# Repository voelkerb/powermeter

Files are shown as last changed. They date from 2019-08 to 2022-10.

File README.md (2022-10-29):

# PowerMeter

The PowerMeter is a WiFi equipped electricity meter which can also switch the connected appliance _on_ and _of_. 
You can record high-frequency voltage and current waveforms or embedd it into your smart home system using e.g. _MQTT_.
Further modular add-ons allow to use other wireless connectivity such as LoRaWAN or to embedd other sensors into the housing. 

<p align="center">
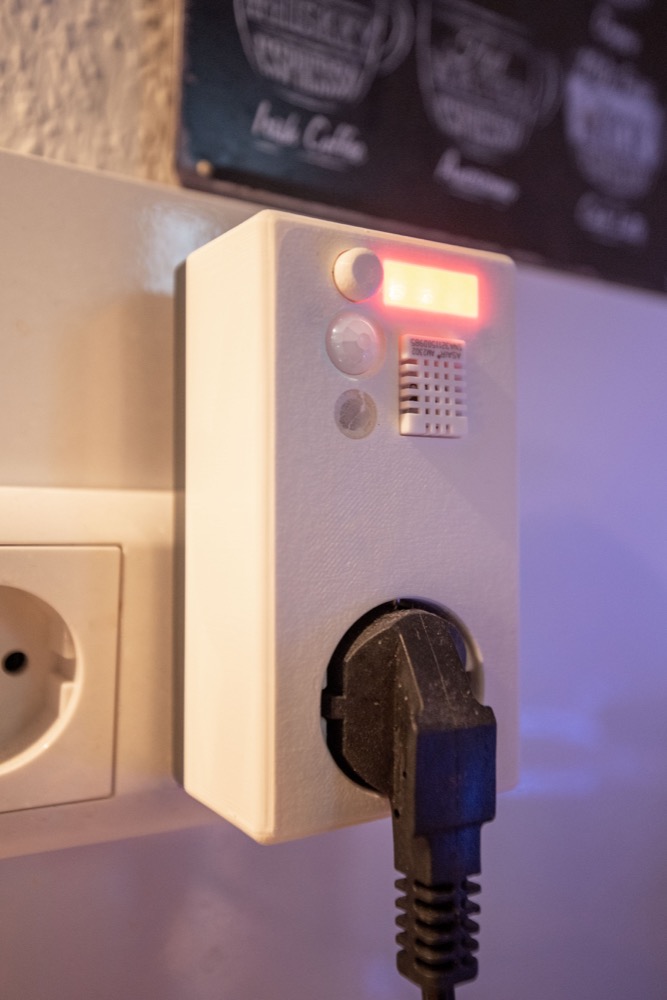
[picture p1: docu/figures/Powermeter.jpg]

</p>

### Clone this repo with
```bash
git clone --recurse-submodules git@github.com:voelkerb/powermeter.git
```

If you are interested in gathering the whole-house energy consumption, see the [SmartMeter](https://github.com/voelkerb/smartmeter) instead.

## Hardware Version _1_ vs _2_
The development started with hardware [Version 1.0](/Schematic/Version_1). It consists of an ESP8266 microcontroller and a dedicated electricity monitoring chip. As the main idea behind this project was to record voltage and current waveforms at higher frequencies, several drawbacks for this use case were fixed with Hardware [Version 2.0](/Schematic/Version_2). It features a faster microcontroller with 8MB internal storage for data buffering, an RTC for precise sampling and time keeping and a full 16A relay so that high-power appliances like dish washers can be switched _on_ and _off_. The USB connection present in [Version 1.0](/Schematic/Version_1) has been removed, but can still be added with an additional extension board.

## Why to use?
It's open source, easy to use, easy to build and offers lots of flexibility. 

The hardware is...
* tested to work reliable with 230V.
* flexible enough to be integrated into existing projects.
* extendable via a UART interface.
* rather cheap (all components sum up to around 30€).

The firmware supports...
* existing 2.4GHz WPA2 networks or can create its own network.
* to receive commands via USB, TCP or MQTT.
* to store the configuration in the internal non volatile memory.
* to provide data at sampling rates from 1/5Hz all the way up to 8kHz.
* to calibrate the measurements.
* integration into most existing smart home systems e.g. HomeKit (via homebridge and MQTT).
* FFMpeg streaming. This allows to store high frequency data directly into files (e.g. MKV).

## How to build one?
You want to build your own PowerMeter? As the PCBs are provided in this repo, you can simply make your own.

Depending on your requirements, you might either build [Version 1.0](/Schematic/Version_1) or [Version 2.0](/Schematic/Version_2). 
* [Version 1.0](/Schematic/Version_1) features an ESP8266 microcontroller and a 10A solid state relay.
    * Benefits: 
        * The parts are cheaper (around 30€).
        * It comes with a USB interface for uploading the firmware or streaming data
    * Drawbacks:
        * Non-modular.
        * The 10A relay can only switch connected appliances with a maximum power consumption of <2300 Watt.
* [Version 2.0](/Schematic/Version_2) features an ESP32 microcontroller and a 16A bistable relay.
    * Benefits: 
        * You can switch appliances with up to 3600Watt. 
        * You have multi-core microcontroller that also supports Bluetooth.
        * 8MB of internal storage allows to buffer data. If you stream high frequency data at e.g. 2kHz, this can hold up to 500s of data on network dropouts.
        * An RTC keeps track of time allowing you to synchronize sampling rates during high frequency sampling.
        * Extendable by stacking other modules on an extension header. 
    * Drawbacks:
        * A little bit more expensive (parts around 35€).

Steps to build your own PowerMeter:
1. Make the PCB ([Version 1.0](/Schematic/Version_1) or [Version 2.0](/Schematic/Version_2)). I recommend to use [JLC](https://jlcpcb.com) as it is super cheap and the quality is still decent.
2. Buy the parts listed under [BOM](/BOM).
3. Solder everything together. We used a small reflow oven, but it could also be done using a fine soldering iron. 
4. Buy a matching housing. We highly recommend to use [this one](https://www.conrad.de/de/p/bopla-eletec-se-432-de-cee-stecker-gehaeuse-120-x-65-x-50-abs-polycarbonat-lichtgrau-graphitgrau-1-st-522228.html) as the PCB was specially designed for it, the mounting holes match, and it is safe to use with 230V. We also experimented with custom 3D prints (see [CAD](/CAD)) but it's at your own risk to do so. 
5. Wire the PowerMeters using the following diagram. 

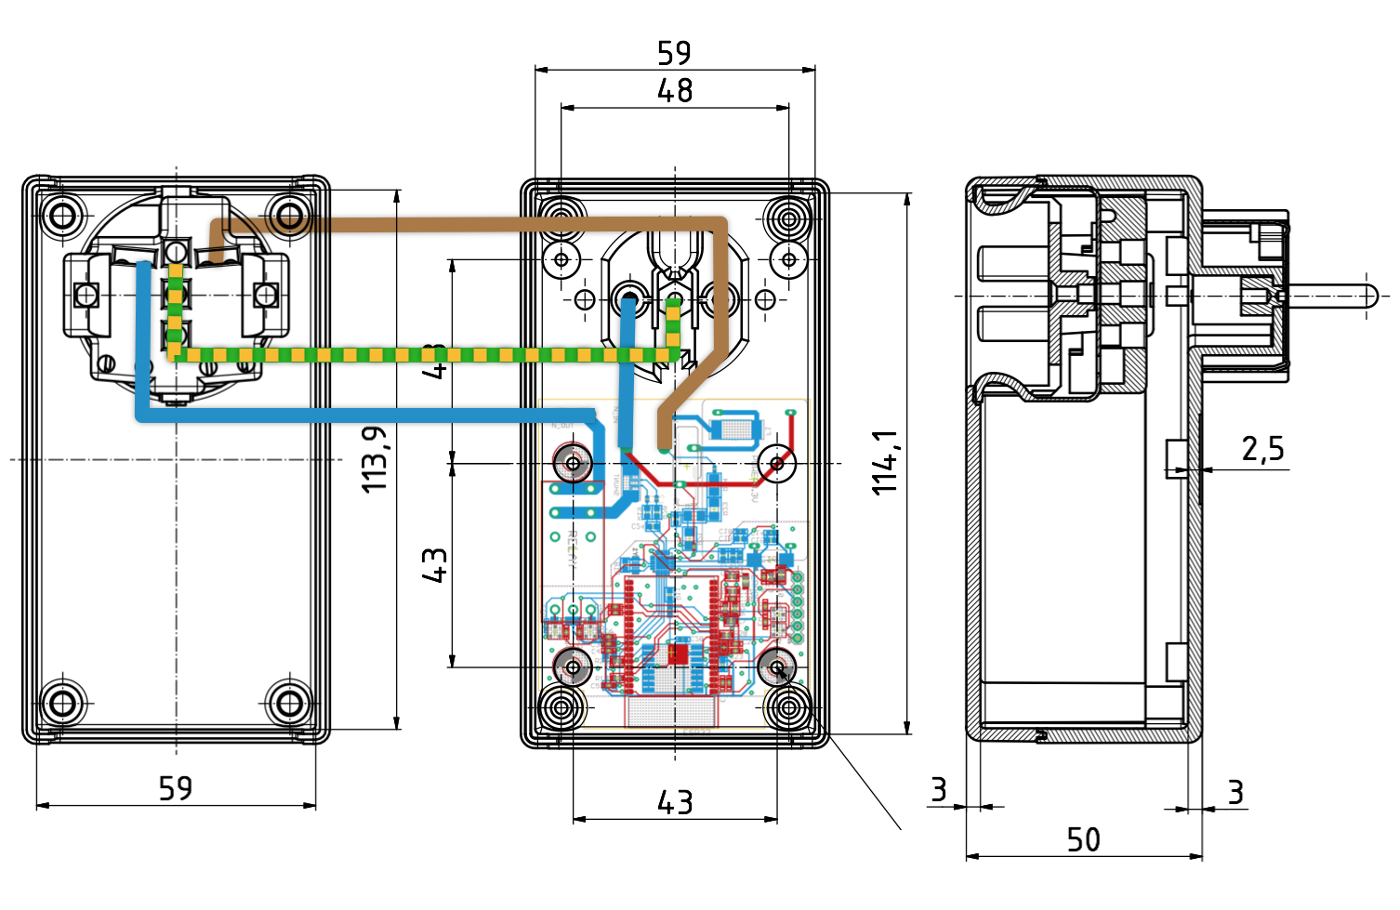
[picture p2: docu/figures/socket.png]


6. Upload the [firmware](/Firmware) according to the instructions for your version. 
7. Interface with the PowerMeter accordingly as stated [here](/docu/README_Firmware_Cmds.md) 

# Use cases
## Smart homes
There are plenty of use cases for a smart plug inside a smart home.
* Switch appliances _on_ and _off_ using a voice assistant or your smartphone
* Include it in home automation software to switch appliances based on an automation. There are lots of possibilities here, e.g.: 
    * Switch appliances _on_ and _off_ by time of day.
    * Switch appliances _off_ automatically at standby consumption.
    * Trigger an alert if the consumption exceeds a limit.
    
      <p align="center">
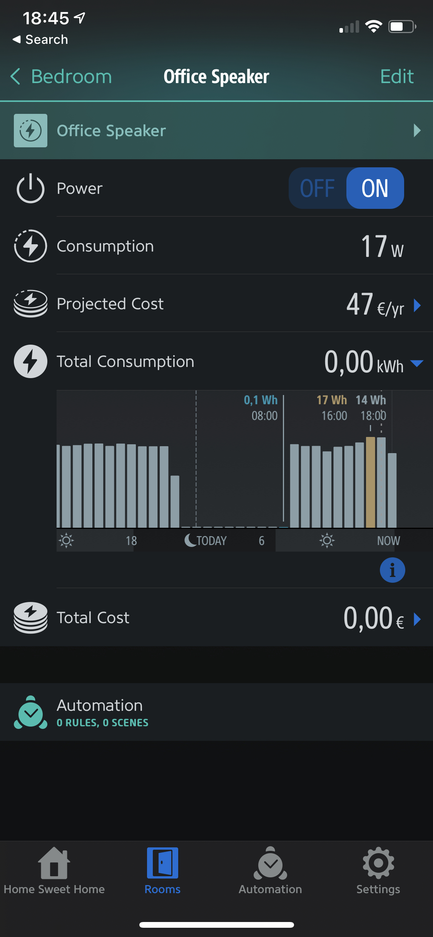
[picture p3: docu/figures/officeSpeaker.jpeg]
      
      </p>
* Monitor the power consumption of an appliance over day. See this faulty fridge as an example.
         
<p align="center">
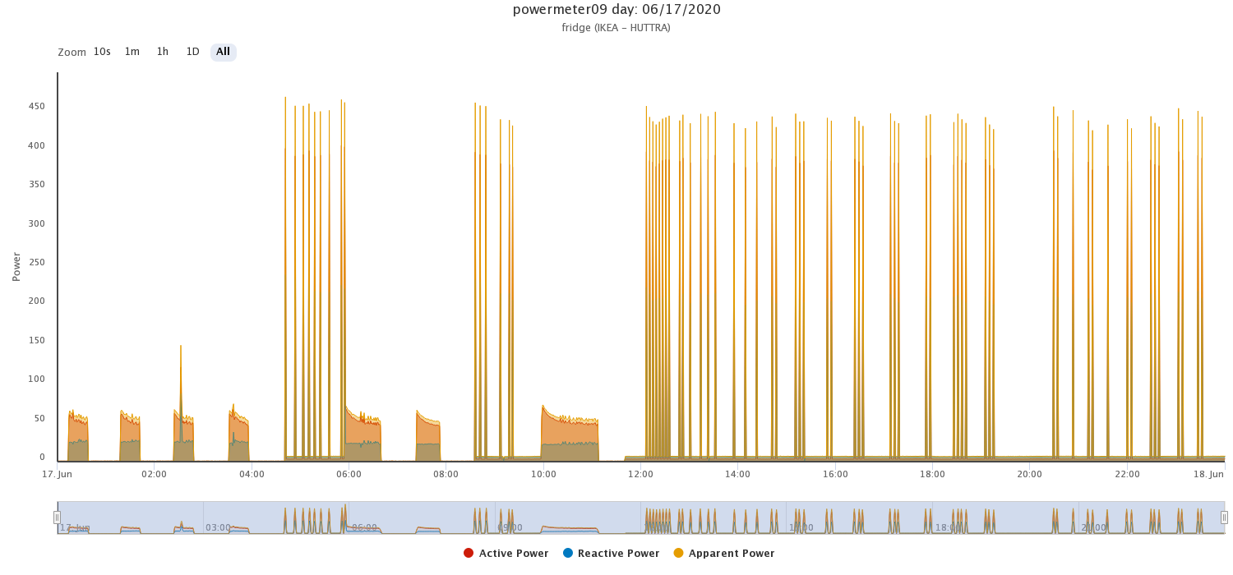
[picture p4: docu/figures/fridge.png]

</p>

## For research purpose
* Analyze high frequency voltage and current waveforms.
         
   <p align="center">
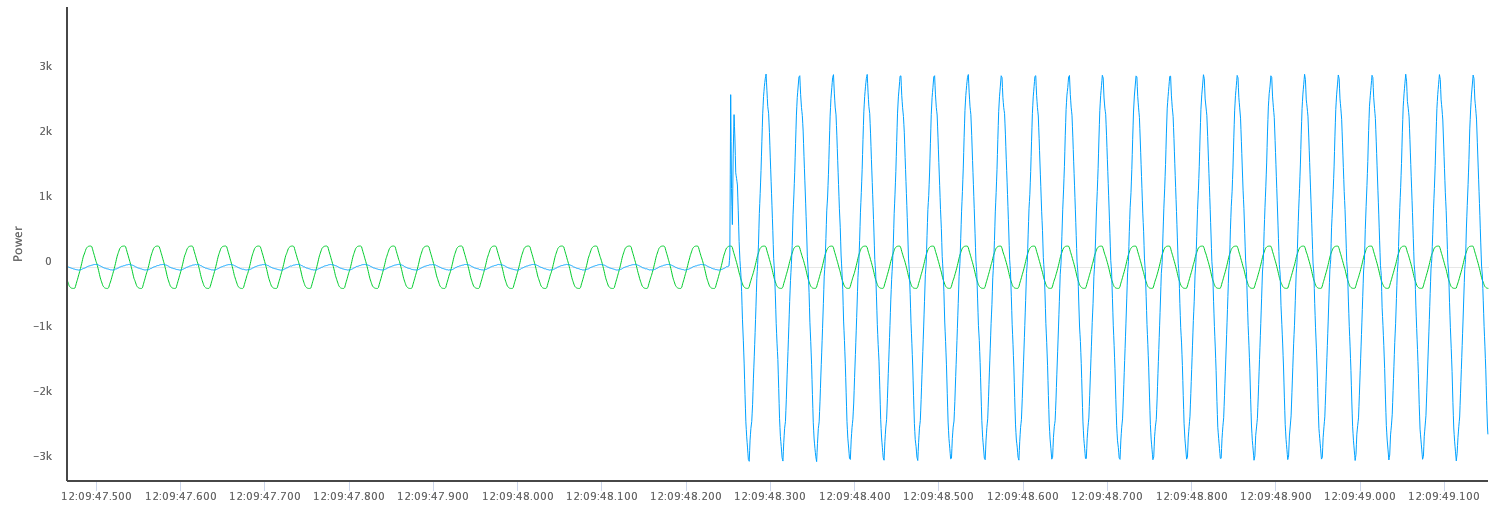
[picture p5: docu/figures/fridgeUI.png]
   
   </p>
* Record high frequency electricity datasets (see e.g. the [FIRED](https://github.com/voelkerb/FIRED_dataset_helper) dataset which can be used for Non-Intrusive Load Monitoring).

# License:
## Firmware:
Copyright (c) 2019 Benjamin Völker. All rights reserved.
This work is licensed under the terms of the [CC 4.0 licence](https://creativecommons.org/licenses/by/4.0/).

## Hardware:
Copyright (c) 2019 Benjamin Völker. All rights reserved.
This work is licensed under the terms of the [TAPR Open Hardware License](https://web.tapr.org/TAPR_Open_Hardware_License_v1.0.txt).

# Reference

Please cite our publications if you compare to or use this system:
* Benjamin Völker, Philipp M. Scholl, and Bernd Becker. 2019. Semi-Automatic Generation and Labeling of Training Data for Non-intrusive Load Monitoring. In Proceedings of the Tenth ACM International Conference on Future Energy Systems (e-Energy '19). Association for Computing Machinery, New York, NY, USA, 17–23. DOI:https://doi.org/10.1145/3307772.3328295
 
* Benjamin Völker, Marc Pfeifer, Philipp M. Scholl, and Bernd Becker. 2020. FIRED: A Fully-labeled hIgh-fRequency Electricity Disaggregation Dataset. In Proceedings of the 7th ACM International Conference on Systems for Energy-Efficient Buildings, Cities, and Transportation (BuildSys '20). Association for Computing Machinery, New York, NY, USA, 294–297. DOI:https://doi.org/10.1145/3408308.3427623

* Völker, B.; Pfeifer, M.; Scholl, P.M.; Becker, B. A Framework to Generate and Label Datasets for Non-Intrusive Load Monitoring. Energies 2021, 14, 75. https://doi.org/10.3390/en14010075

Kudos also go to Pascal Verboket & Valentin Czisch for developing the first draft schematics prior to [Version 1.0](/Schematic/Version_1).

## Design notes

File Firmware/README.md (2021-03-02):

[powermeter]: (https://github.com/voelkerb/powermeter)

# What hardware do you have?

Depending on the hardware you have, you require different firmware versions:

**[Hardware version 1](/Schematic/Version_1) requires [firmware version 1](Version_1/README.md).**

**[Hardware version 2](/Schematic/Version_2) requires [firmware version 2](Version_2/README.md).**

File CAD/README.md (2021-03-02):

[powermeter]: (https://github.com/voelkerb/powermeter)
[bopla]:(https://www.conrad.de/de/p/bopla-eletec-se-432-de-cee-stecker-gehaeuse-120-x-65-x-50-abs-polycarbonat-lichtgrau-graphitgrau-1-st-522228.html)

# Rough PCB Model
You can use the [circuit board](circuitBoard.SLDPRT) design file to design custom enclosures for the PCB.

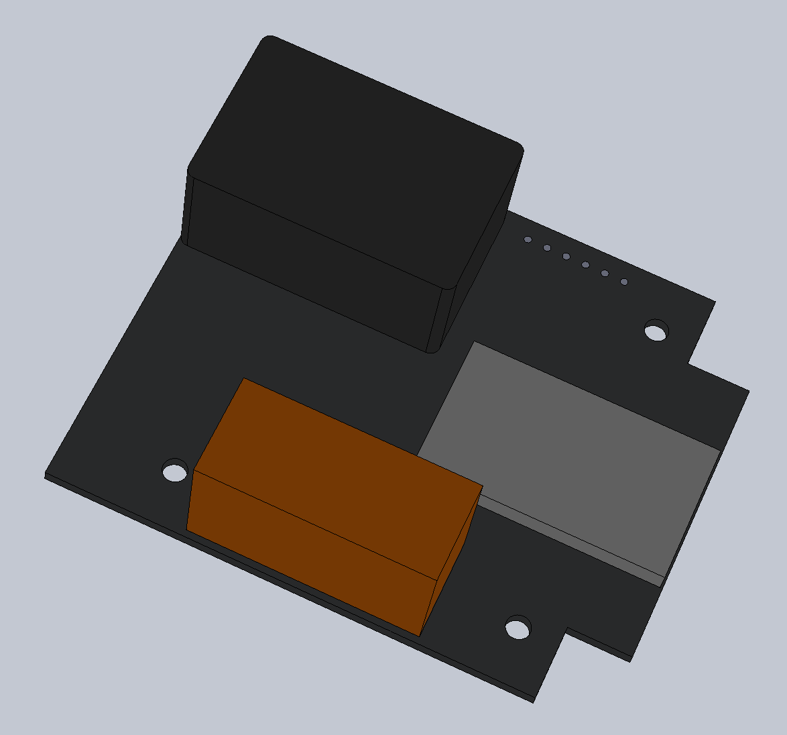
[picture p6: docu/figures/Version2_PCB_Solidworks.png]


We encourage you to use the off-the-shelf case which can be found at [here](https://www.conrad.de/de/p/bopla-eletec-se-432-de-cee-stecker-gehaeuse-120-x-65-x-50-abs-polycarbonat-lichtgrau-graphitgrau-1-st-522228.html) as you are working with 230V.
The PCB was specially designed for this case and perfectly matches into its mounting holes. Even if the case is bulky and kind of ugly, it offers a secure encapsulation, provides enough room and is rather inexpensive.

As the PCB is designed in Eagle, a 3D part can also be imported directly in Fusion360 (see file [powermeterV2.f3d](powermeterV2.f3d)).

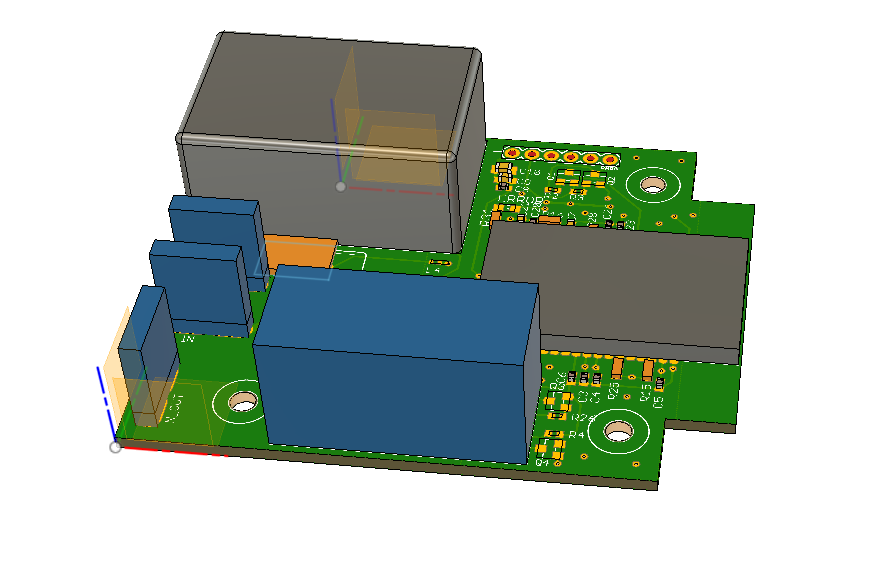
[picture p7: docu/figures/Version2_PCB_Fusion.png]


For a simple stl file which you can also 3D print to see if your casing matches, we refer to [powermeterV2.stl](powermeterV2.stl)).

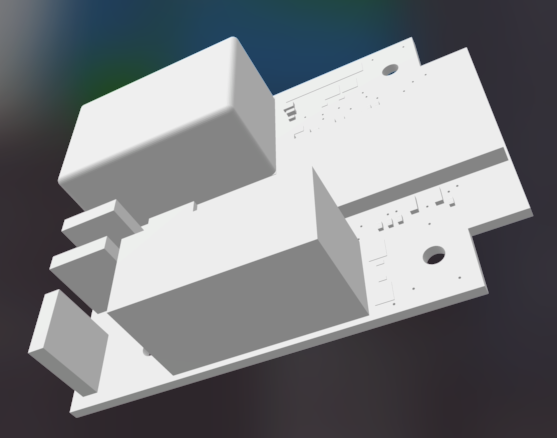
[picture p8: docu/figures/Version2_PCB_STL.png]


# Casing for a cable
Sometimes the [bopla] case cannot be used as it is a little to bulky. Then you can embed the [powermeter] inside the cable using [case_in_cable_top.STL](case_in_cable_top.STL) and [case_in_cable.STL](case_in_cable.STL). Simply print them and place the PCB inside. 

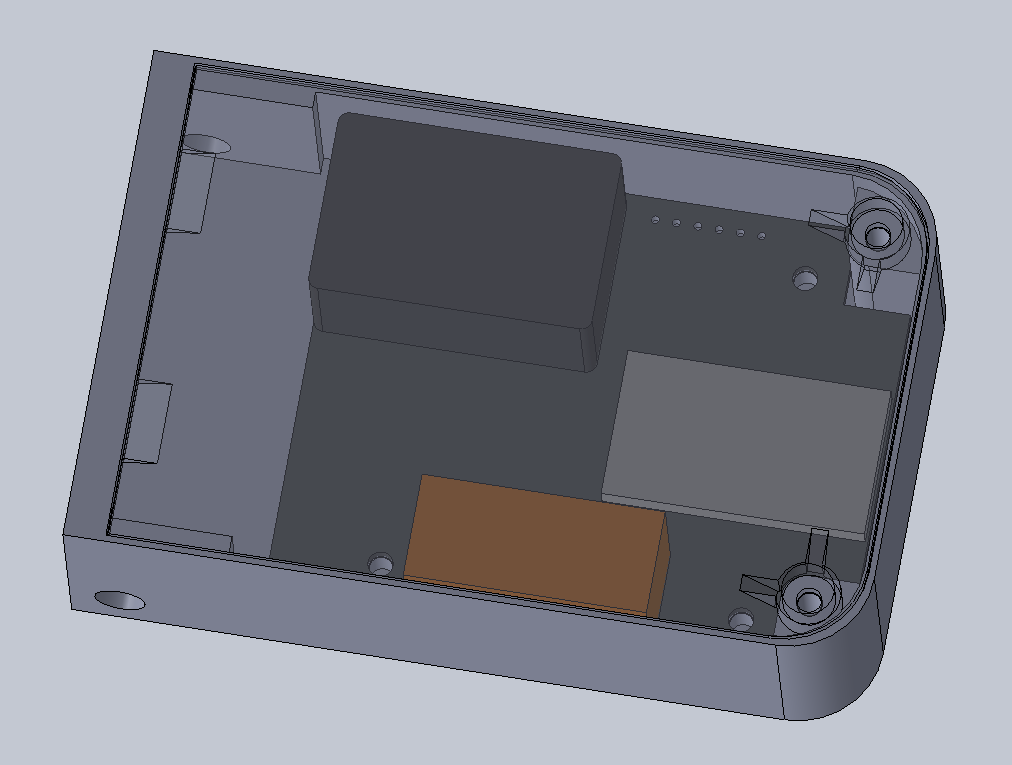
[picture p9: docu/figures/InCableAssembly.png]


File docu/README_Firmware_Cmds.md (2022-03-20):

[PowerMeter]: (https://github.com/voelkerb/PowerMeter)

# How to interface with a PowerMeter

## The Basics
The [PowerMeter] has to be connected to an outlet for power supply. \
At first boot, the [PowerMeter] will open a WiFi-Network called "powermeterX".\
It is not password protected, so you can simply connect to it. 
Open a TCP connection to IP ```powermeterX.local``` (or ```192.168.4.1```) at port ```54321```.
This will show you basic information of the [PowerMeter] as a JSON encoded messages.
```bash
Info:{"cmd":"info","type":"PowerMeter","version":"2.2","compiled":"Mar_2_2021_09:57:58","sys_time":"03/02/2021 10:37:07.662","name":"powermeterX","ip":"192.168.4.1","mqtt_server":"-","stream_server":"-","time_server":"time.google.com","sampling_rate":4000,"buffer_size":3670016,"psram":true,"rtc":false,"calV":1,"calI":1,"state":"idle","relay":1,"calibration":[1,1],"ssids":"[energywifi]","ssid":"-","rssi":-71,"bssid":"-"}
```
You will further notice that a lifeness log messages is sent each second.
We will further see how to use commands to interface with a PowerMeter.

**Each command sent to the [PowerMeter] over USB or a TCP channel requires JSON encoding as ```{"cmd":<cmdName>,[optional]}``` and is answered by a JSON encoded answer message preceded by a the text "Info:". If an error occurred while processing the commmand, the error key is set true in the returned JSON.**

## Overview
| CMD | Description | 
| --- |---|
| ["info"](#info) | Get basic information |
| ["switch"](#relay) | Switch relay _on_ or _off_ |
| ["getPower"](#getting-energy-data) | Get active, reactive and apparent power |
| ["getVoltage"](#getting-energy-data) | Get current RMS voltage level |
| ["getCurrent"](#getting-energy-data) | Get RMS current |
| ["getEnergy"](#getting-energy-data) | Get energy in Wh and time period |
| ["getPeriod"](#getting-energy-data) | Get current net frequency |
| ["getPhaseAngle"](#getting-energy-data) | Get phase angle between voltage and current  |
| ["mdns"](#name) | Set new mDNS and general [PowerMeter] name |
| ["addWifi"](#wifi) | Add WiFi AP |
| ["delWifi"](#wifi) | Remove WiFi AP |
| ["calibration"](#calibration) | Set calibration parameter |
| ["restart"](#restart) | Restart [PowerMeter] |
| ["dailyRestart"](#restart) | Schedule reset every day |
| ["factoryReset"](#reset) | Reset to standard values |
| ["basicReset"](#reset) | Reset everything but the name |
| ["resetEnergy"](#reset-energy) | Reset accumulated energy |
| ["sample"](#using-a-sampling-command) | Start receiving high frequency data |
| ["reqSamples"](#using-a-sampling-command) | Get certain amount of high frequency samples |
| ["cts"](#pause-streaming) | Allow/forbid to stream samples |
| ["stop"](#stop-streaming) | Stop receiving data |
| ["log"](#log-level) | Change log level |
| ["clearLog"](#log) | Clear logs |
| ["getLog"](#log) | Returns all warning and error log messages |
| ["mqttServer"](#mqtt) | Set MQTT server |
| ["publishInterval"](#mqtt) | Publish interval for data over MQTT |
| ["streamServer"](#using-a-stream-server) | Set stream server |
| ["ntp"](#time-synchronization) | Trigger NTP sync |
| ["timeServer"](#time-synchronization) | Set time server for NTP |
| ["lora"](#lorawan) | Interface with the LoRaWAN module |
| ["sensorBoardInfo"](#sensorboard) | Get info and config of sensor board |
| ["getSensors"](#getting-sensor-values) | Get sensor reading of all sensors |
| ["getHum"](#getting-sensor-values) | Get humidity level |
| ["getTemp"](#getting-sensor-values) | Get temperature |
| ["getLight"](#getting-sensor-values) | Get light intensity |
| ["getPIR"](#getting-sensor-values) | Get binary movement detection |
| ["calibrateTemp"](#calibrating-sensor-values)  | Set offset of temperature sensor |
| ["calibrateHum"](#calibrating-sensor-values) | Set offset of humidity sensor |
| ["calibrateLight"](#calibrating-sensor-values) | Set multiplier for light sensor |
| ["powerIndication"](#eco-feedback) | Set min and max power for eco feedback |
| ["setLED"](#changing-the-leds) | Set the LEDs to show a specific pattern |

## Info
```{"cmd":"info"}```\
The info command will print information about the [PowerMeter]. As this is the most often required command, it is automatically sent to each new connected TCP client. 

## Log Level
```{"cmd":"log","level":<logLevel>}```\
Choose between the following log levels: ```all, debug, info, warning, error```\
Each new connection is initialized with log level ```info```.
```bash
Info:{"error":false,"msg":"Log Level set to: warning"}
```

## Name
```{"cmd":"mdns","payload":{"name":"<newName>"}}```\
This command should be used to give the [PowerMeter] a new unique name.
It will be used to announce presence over MDNS and if no known network is found, an AP is opened using this name.

```bash
Info:[I]03/02 10:42:24: MDNS Name: powermeterX
Info:{"error":false,"msg":"Set MDNS name to: powermeterX","mdns_name":"powermeterX"}
```

## Relay
```{"cmd":"switch","payload":{"value":"<false or true>"}}```\
Switches the relay (and thus the connected appliance) _on_ or _off_.
```bash
Info:{"error":false,"msg":"Switching: On"}
```

## Restart
```{"cmd":"restart"}```\
Restarts the [PowerMeter]. The TCP connection will be lost.

You can also trigger the module to automatically reset at a particular time (```<hour>:<minute>:00```) each day for maintenance reason. Use ```<hour> = <minute> = -1``` to disable.\
```{"cmd":"restartDaily","hour":<hour>,"minute":<minute>}```

## Reset
```{"cmd":"factoryReset"}```\
Resets everything to defaults. The default values are:
- name: _powermeterX_
- wifi aps: <StandardSSID> -> (pwd: <StandardPWD>)
- timeserver: _time.google.com_
- streamserver: -
- mqtt broker: -
- _calV_ = _calI_ = 1.0
- _energy_ = 0
- _resetHour_ = _resetMinute_ = -1

If you want to reset everything except the name, use: ```{"cmd":"basicReset"}```

## Log
```{"cmd":"getLog"}```\
The [PowerMeter] has some decent logging capabilities. Despite logging over a connected TCP connection and Serial. _Warning_ and _Error_ messages are logged to internal flash memory.
The _getLog_ command will dump the all logs in the flash and contains two JSON response messages.
```bash
Info:{"cmd":"log","msg":"*** LOGFile *** [E]03/02 11:26:20: Cannot connect to MQTT Server -//n*** LOGFile *** "}
Info:{"error":false}
```
All newlines are replaces by "_//n_".\
To clear all log messages, use ```{"cmd":"clearLog"}```.

## Calibration
```{"cmd":"calibration","calV":<calV>,"calI":<calI>}```\
Calibrate the [PowerMeter].
```<calV>``` and ```<calI>``` are floating point values with the default value 1.0.
Every measured voltage and current value is multiplied by the calibration factor. Power and Energy are multiplied by ```<calV>```*```<calI>```.

## Reset Energy
```{"cmd":"resetEnergy","energy":<energy>,"ts",<ts>}```\
Simply resets the accumulated energy stored in flash.
* ```<energy>``` (optional): float value in Watthours. If no value is provided, the energy is reset to 0Wh.
* ```<ts>``` (optional): unix timestamp to indicate the start time of energy accumulation. If no value is provided the current time is used.  

## Time synchronization
```{"cmd":"ntp"}```\
Will perform an NTP time synchronization.
```
Info:[I]03/02 11:28:14: NTP synced with conf: 11
Info:{"msg":"Time synced","error":false,"current_time":"03/02/2021 11:27:40.182"}
```
To set a new NTP timeserver, use the command: ```{"cmd":"timeServer", "payload":{"server":"<serverAddress>"}}```. The _serverAddress_ can be also be its DNS name e.g. time.google.com
```bash
Info:[I]03/02 11:28:14: NTP synced with conf: 11
Info:{"error":false,"msg":"Set TimeServer address to: time.google.com","time_server":"time.google.com"}
```

## WiFi
Add wifi AP: ```{"cmd":"addWifi", "payload":{"ssid":"<ssidName>","pwd":"<pwdName>"}}```
```bash
Info:{"error":false,"ssid":"Test","pwd":"TestPwd","msg":"New Ap, SSID: Test, PW: TestPwd","ssids":"[energywifi, Test]"}
```
Remove a wifi AP: ```{"cmd":"delWifi", "payload":{"ssid":"<ssidName>"}}```
```bash
Info:{"error":false,"msg":"Removed SSID: Test","ssids":"[energywifi]"}
```

## MQTT
Once connected to an MQTT server, the PowerMeter will publish the current power consumption each 5 seconds and each state change of the relay. 
To set the MQTT server, use the command: 
```bash
{"cmd":"mqttServer", "payload":{"server":"<ServerAddress>, "user":<user>, "pwd":<pwd>, "port":<port>"}}
```
  
```<ServerAddress>```: IP of broker - "-" to disable MQTT\
```<user>```: [Optional] User name of authentification - standard None\
```<pwd>```: [Optional] PWD of authentification - standard None\
```<port>```: [Optional] Port of the TCP connection - standard 1883\
```bash
Info:[I]03/02 11:38:42: MQTT connected to 192.168.0.13
Info:[I]03/02 11:38:42: Subscribing to: powermeter/+
Info:[I]03/02 11:38:42: Subscribing to: powermeter/powermeterX/+
Info:{"error":false,"msg":"Set MQTTServer address to: 192.168.0.13","mqtt_server":"192.168.0.13"}
```

### Publish Interval
To set the interval that data is published over MQTT use: 
```bash
{"cmd":"publishInterval","intv":<intv>}
```
```<intv>```: the time in seconds (float) data is published automatically, -1 to disable autopublish

NOTE: In sampling mode, MQTT is disabled for performance reason.

### Receiving MQTT messages
The relay state is send as a retained message on topic ```powermeter/<name>/state/switch```
```bash
powermeter/powermeterX/state/switch true
```
Each 5 seconds, information about the power consumption is sent.
It contains the _active power_ in _Watt_, the _RMS voltage_ in _V_,  the _RMS current in _A_, the current timestamp, and the accumulated energy since last restart. Furthermore, if more than _2 Watt_ is drawn, ```inUse``` is ```true```.
```bash
powermeter/powermeter15/state/sample {"power":1116.89,"inUse":true,"current":4.82,"energy":0,"volt":236.56,"ts":"1614681575"}
powermeter/powermeter28/state/sample {"power":0.01,"inUse":false,"current":0,"energy":0,"volt":230.85,"ts":"1614681576"}
powermeter/powermeter27/state/sample {"power":0,"current":0,"inUse":false,"energy":0,"volt":231.28,"ts":"1614681576"}
```
If a [SensorBoard](#sensorboard) is connected to the [PowerMeter], all sensor values are further published over MQTT. Whenever a sensor changes its value, it is published under a distinct topic with the timestamp and unit.
```bash
powermeter/powermeter11/state/sensors/temp {"temp":25.5,"unit":"C","ts":1631873651}
powermeter/powermeter11/state/sensors/PIR {"PIR":true,"ts":1631873717}
powermeter/powermeter11/state/sensors/hum {"hum":51.7,"unit":"%","ts":1631873716}
powermeter/powermeter11/state/sensors/light {"light":110,"unit":"lux","ts":1631873486}
powermeter/powermeter08/state/sensors/temp {"temp":26.2,"unit":"C","ts":1631873706}
powermeter/powermeter08/state/sensors/hum {"hum":60.8,"unit":"%","ts":1631873716}
powermeter/powermeter08/state/sensors/light {"light":352,"unit":"lux","ts":1631873616}
```

### Sending MQTT messages
Mqtt can also be used to send any command. Special topics are used to switch the relay or to get basic electricity related measurements, but any of the available commands can be sent.
* Switching the relay using topic ```powermeter/<name>/switch```:
  ```bash
  mosquitto_pub -h 192.168.0.13 -t 'powermeter/powermeter27/switch' -m true
  ```
* Sample a single value using topic ```powermeter/<name>/sample``` and message one of ```v,i,p,q,s,e``` (_RMS voltage_,_RMS Current_, _active_, _reactive_, _apparent power_ or _active energy_). On no, or any other message, the _active power_ is sent.
  ```bash
  powermeter/powermeter27/sample p
  ````
  The response contains a JSON dictionary with the key _value_, _unit_ and _ts_, example:
  ```bash
  powermeter/powermeter27/state/sample {"value":1.003773,"unit":"W","ts":"03/02/2021 11:59:59.034"}
  ```
* You can also send any command, which can be sent over a bare TCP connection using topic ```powermeter/<name>/cmd```
  ```bash
  mosquitto_pub -h 192.168.0.13 -t 'powermeter/powermeter27/cmd' -m '{"cmd":"switch","payload":{"value":"false"}}'
  ```
* If you have multiple PowerMeters and want to send the message to all at the same time (e.g. to change some global settings such as the MQTT broker), you can simple ditch the specific PowerMeter name and all will answer. 
  ```bash
  powermeter/sample p
  powermeter/powermeter24/state/sample {"value":1.487539,"unit":"W","ts":"03/02/2021 12:08:28.208"}
  powermeter/powermeter28/state/sample {"value":0.039796,"unit":"W","ts":"03/02/2021 12:08:28.210"}
  powermeter/powermeter20/state/sample {"value":193.0246,"unit":"W","ts":"03/02/2021 12:08:28.208"}
  powermeter/powermeter26/state/sample {"value":15.28467,"unit":"W","ts":"03/02/2021 12:08:28.209"}
  ...
  ```

## SensorBoard
If a [SensorBoard](https://github.com/voelkerb/powermeter.sensorboard/) is connected to the expansion header and the Firmware is configured to make use of it (see [compile info](https://github.com/voelkerb/powermeter/blob/master/docu/README_Firmware_2_compile.md)), additional environmental sensor data is available.

* ```{"cmd":"sensorBoardInfo"}```\
  Returns information about the sensor board and all calibration parameters.\
  Sample output:
  ```bash
  {"error":false,"tempOffset":-2.5,"humOffset":10,"brightness":100,"calLight":1,"minLEDWatt":2,"maxLEDWatt":200,"active":true,"autoMode":true}
  ```

### Getting sensor values

* ```{"cmd":"getPIR"}```\
Returns if motion is detected near the [PowerMeter].

* ```{"cmd":"getHum"}```\
Returns the current humidity level in %.

* ```{"cmd":"getTemp"}```\
Returns the current temperature in degrees Celsius.

* ```{"cmd":"getLight"}```\
Returns the current light intensity in Lux.

* ```{"cmd":"getSensors"}```\
Returns all sensor values.

### Calibrating sensor values

* ```{"cmd":"calibrateTemp","offset":<offset>}```\
```<offset>```: ```float``` gets permanently stored as an offset added to the measured temperature.

* ```{"cmd":"calibrateHum","offset":<offset>}```\
  ```<offset>```: ```float``` gets permanently stored as an offset added to the measured humidity level.

* ```{"cmd":"calibrateLight","value":<value>}```\
  ```<value>```: ```float``` gets permanently stored as a value multiplied with the measured light intensity level.

### Changing the LEDs

```bash
{"cmd":"setLED","brightness":<brightness>,"pattern":<patter>,"duration":<duration>,"fgColor":[<red>,<green>,<blue>],"bgColor":[<red>,<green>,<blue>]}
```
* ```<brightness>``` (optional): ```0.0-100.0```
  * gets permanently stored as the new maximum brightness value.
* ```<pattern>``` (optional): ```0-5```; the specific LED pattern to show.
  * ```0```: _static_ pattern, shows a static color
  * ```1```: _blink_ pattern, blink between foreground and background color. The blink interval is 1s.
  * ```2```: _round_ pattern, one LED (fgColor) goes around. Other LEDs in bgColor. The time to move to the next LED is 200ms.
  * ```3```: _glow_ pattern, glow (fade) from fg to bg color and back. Glowing takes around 1.5s.
  * ```4```: _power_ pattern, show the power consumption mapped to a color (<3W = Black, 3-500W linear mapped between green and red, >500W full red). The LED color is updated depending on the current power each 5s.
* ```<duration>``` (optional): ```-1-2^32```
  * duration in milliseconds, the new patter is shown. Afterwards, the last pattern (with a duration of -1) is shown.
  * ```-1``` indicates that the pattern should be shown for infinite length.
* ```<fgColor>``` (optional):
  * foreground color of the pattern.
  * array with three values from ```0-255``` for each color: _red_, _green_, _blue_
  * default: [64,64,64]
* ```<bgColor>``` (optional):
  * background color of the pattern.
  * array with three values from ```0-255``` for each color: _red_, _green_, _blue_
  * default: [0,0,0]

### Eco Feedback

Use the build in LEDs of the SensorBoard as Eco-Feedback. This is the standard setting when the [PowerMeter] boots. 

* ```{"cmd":"powerIndication","min":<minW>,"max":<maxW>}```
  * ```<minW>``` (optional): ```float``` minimum Watt. If less power is drawn, the LEDs are turned black.If exactly ```<minW>```W are drawn, the LEDs will indicate green. 
  * ```<maxW>``` (optional): ```float``` maximum Watt. If more power is drawn, the LEDs are full red. Otherwise, they linearly map between full green on ```<minW>```W and full red on ```<maxW>```W. 

## LoRaWAN
If a supported module is connected to the expansion header and the Firmware is configured to make use of it (see [compile info](https://github.com/voelkerb/powermeter/blob/master/docu/README_Firmware_2_compile.md)), data is also sent via LoRaWAN.

Credentials for OTA activation must be set at compile time. We may add this to the configuration later on.

### Communicate with the module

* ```{"cmd":"lora", "msg":"info"}```\
Send this command to get info about the currently set DEV_EUI and APP_EUI and the connection status. Sample output:
  ```bash
  Info:[I]08/03 18:02:03: LoRa-TX: AT+ID
  Info:[I]08/03 18:02:03: LoRa-RX: +ID: DevAddr, <XX:XX:XX:XX>
  Info:[I]08/03 18:02:03: LoRa-RX: +ID: DevEui, <XX:XX:XX:XX:XX:XX:XX:XX>
  Info:[I]08/03 18:02:03: LoRa-RX: +ID: AppEui, <XX:XX:XX:XX:XX:XX:XX:XX>
  Info:{"error":false,"connected":true,"joined":true}
  ```
* ```{"cmd":"lora", "msg":"join"}```\
Try to join the network.
Sample output:
  ```bash
  Info:[I]08/03 18:04:17: LoRa-TX: AT+MODE=LWOTAA
  Info:[I]08/03 18:04:17: LoRa-RX: +MODE: LWOTAA
  Info:[I]08/03 18:04:17: LoRa-TX: AT+DR=EU868
  Info:[I]08/03 18:04:17: LoRa-RX: +DR: EU868
  Info:[I]08/03 18:04:17: LoRa-TX: AT+CH=NUM,0-2
  Info:[I]08/03 18:04:17: LoRa-RX: +CH: NUM, 0-2
  Info:[I]08/03 18:04:17: LoRa-TX: AT+KEY=APPKEY,"XXXXXXXXXXXXXXXXXXXXXXXXXXXXXXX"
  Info:[I]08/03 18:04:17: LoRa-RX: +KEY: APPKEY XXXXXXXXXXXXXXXXXXXXXXXXXXXXXXX
  Info:[I]08/03 18:04:17: LoRa-TX: AT+CLASS=A
  Info:[I]08/03 18:04:17: LoRa-RX: +CLASS: A
  Info:[I]08/03 18:04:17: LoRa-TX: AT+JOIN
  Info:[I]08/03 18:04:17: LoRa-RX: +JOIN: Start
  Info:[I]08/03 18:04:17: LoRa-RX: +JOIN: NORMAL
  Info:[I]08/03 18:04:26: LoRa-RX: +JOIN: Network joined
  Info:[I]08/03 18:04:26: LoRa-RX: +JOIN: NetID 000013 DevAddr <XX:XX:XX:XX>
  Info:[I]08/03 18:04:26: LoRa-RX: +JOIN: Done
  ```
* ```{"cmd":"lora", "msg":"AT"}```\
Sample output:
  ```bash
  Info:[I]08/03 18:04:11: LoRa-TX: AT
  Info:{"error":false,"connected":true,"joined":true}
  Info:[I]08/03 18:04:11: LoRa-RX: +AT: OK
  ```
Anything else is regarded as an AT command. See the modules documentation for more detail: [Grove-E5](https://files.seeedstudio.com/products/317990687/res/LoRa-E5%20AT%20Command%20Specification_V1.0%20.pdf)

### UpLink Messages

If the module is connected, the code will automatically try to join the LoRaWAN network each ```LORA_UPDATE_INTERVAL''' seconds. If connected, active and reactive power, RMS voltage and current and electrical energy is sent with the relay state and the system time as raw bytes. 
All values are send as little-endian in the following order:

* active power as 4 byte float value
* reactive power as 4 byte float value
* RMS current as 4 byte float value
* RMS voltage as 4 byte float value
* electrical energy as 4 byte float value
* unix timestamp as 4 byte unsigned int
* relay state as 1 byte unsigned int

These can be decoded in the TTN network application layer e.g. using the following uplink formatter:

```JavaScript
function Decoder(bytes, port) {
  var decoded = {};
  if (port == 8) {  // Adjust the port depending on your config
    var values = ["active","reactive","irms","vrms","energy","ts","relay"];
    var valueBytes = [4, 4, 4, 4, 4, 4, 1];
    var i = 0;
    for (let k = 0; k < values.length; k++) {
      if (i >= bytes.length) { break; }
      var buf = new ArrayBuffer(valueBytes[k]);  // Create a buffer
      var view = new DataView(buf);  // Create a data view of it
      // Set individual bytes LE
      for (let j=0; j < valueBytes[k]; j++) { view.setUint8(valueBytes[k]-1-j, bytes[i+j]); }
      var num = 0;
      if (values[k] == "ts") { num = view.getUint32(0); }
      else if (values[k] == "relay") { num = view.getUint8(0); } 
      else { num = view.getFloat32(0); }
      decoded[values[k]] = num;
      i += valueBytes[k];
    }
  }
  return decoded;
}
```

### DownLink Messages

Down link messages must be sent on the same port according to the following format:
```<prefix><relayState><reset>```.

* ```<prefix>```: Should match the config and exists to check data integrity.
* ```<relayState>```: 1 byte unsigned int. ```0``` to switch off, ```1``` to switch on, and ```2``` to toggle.
* ```<reset>```: 1 byte unsigned int. ```0``` to do nothing, ```1``` to restart the PowerMeter.
If you have configured TTN to be accessible via an MQTT server, you can toggle the relay using:

```
mosquitto_pub -h <ttnLocation>.cloud.thethings.network -d -t '<ttnVerssion>/<yourApplicationID>@ttn/devices/<yourDeviceID>/down/push' -u <yourMqttUser> -P <yourMqttPWD> -m '{"downlinks":[{"f_port": 8,"frm_payload":"AB0200","priority": "NORMAL"}]}' -d
```
The message must be a JSON dictionary in the shown format. The DownLink message is set via the key ```frm_payload``` and must be base64 encoded. 

## Getting Energy Data
To obtain one shot measurements, several commands exist for all kinds of electrical quantities.
All data is returned as a JSON dict with the command and the measurement's unit.

* ```{"cmd":"getPower"}```\
Returns active, reactive and apparent power.

* ```{"cmd":"getVoltage"}```\
Returns RMS voltage level.

* ```{"cmd":"getCurrent"}```\
Returns RMS current level.

* ```{"cmd":"getEnergy"}```\
  Returns energy since reset. Includes time span.
  ```bash
  Info:{"error":false,"cmd":"getEnergy","energy":1034.259,"unit":"Wh","startTs":1629464739,"start":"08/20/2021 15:05:39.000","days":31}
  ```

* ```{"cmd":"getPeriod"}```\
Get current net frequency. Resolution is 8us according to datasheet.

* ```{"cmd":"getPhaseAngle"}```\
Returns phase angle between voltage and current.

## Getting High Frequency Data
Finally, to get some high frequency data out of the PowerMeters beyond whats possible using [mqtt](#mqtt), you have multiple possibilities. 

### Using FFmpeg
Using ffmpeg is by far the most simple way to store high frequency data. Thus, the sampling rate remains at 4kHz and only current and voltage measurements are streamed.
On your host computer, simply install [ffmpeg](https://ffmpeg.org) and run the following:
```bash
ffmpeg -nostdin -hide_banner -fflags +nobuffer+flush_packets -f f32le -ar 4000.0 -guess_layout_max 0 -ac 2.0 -flush_packets 1 -thread_queue_size 512 -analyzeduration 0 -i tcp://<PowerMeterIP>:54322 -c:a wavpack -frame_size 4000 -metadata:s:a:0 CHANNELS=2 -metadata:s:a:0 CHANNEL_TAGS="v,i" -metadata:s:a:0 title="<PowerMeterName>" -map 0 -y output.mkv 
```
You can directly use the MDNS name for ```<PowerMeterIP>```. Some of the settings in call such as the metadata are of course optional. 

### Using a stream server
At your future data sink (which simply might be your computer), host a TCP server at port ```54322```.
Find you IP address and set it as the target stream server for each PowerMeter using the command ```{"cmd":"streamServer", "payload":{"server":"<YourIp>"}}```.
The [PowerMeter] will check if the stream server is available each 30s and automatically connects to it.
For the data format, see [Data Format](#data-format).

### Using a sampling command
This is the most complicated command of the PowerMeter. It has multiple and potentially optional parameter which will be explained in the following. 
```bash
{"cmd":"sample", "payload":{"type":"<type>", "measures":"<measures>", "rate":<rate>, "prefix":<prefix>, "port":<port>,"time":<time>,"flowCtr":<flowCtr>,"slot":[<slot>,<slots>],"ntpConf":<ntpConf>}}
```
Example:
The response for the command ```{"cmd":"stop","payload":{"type":"TCP","rate":1}}``` is:
```bash
Info:{"error":false,"measures":"v,i","chunksize":8,"samplingrate":1,"conn_type":"TCP","measurements":2,"prefix":true,"flowCtr":false,"cmd":"sample","unit":"V,mA","startTs":"1614697441.119"}
```

Parameters:
* ```<type>``` + optional: ```<port>```: The Type of the data stream.
  * "Serial": sampled data is sent over USB Serial connection
  * "TCP": sampled data is sent over TCP connection (the one you opened to it). 
  * "UDP": sampled data is sent over a UDP connection. You need to specify the UDP Port with ```<port>```.
  * "MQTT": sampled data is sent over MQTT (broker must be set, see [MQTT](#mqtt)). 
  * "FFMPEG": connect with an ffmpeg call to the stream server on port ```54322```. No prefix is supported and no line ending, just the raw data. Can be used directly with ffmpeg streaming. Allows to change settings while using [ffmpeg streaming](#using-ffmpeg).

* ```<rate>```: The goal sampling rate of the data.
  * Integer value between 1 and 8000 (default: 4000)

* ```<measures>``` (optional):
  * "v,i": will return _voltage_ and _current_
  * "p,q": will return _active_ and _reactive power_
  * "v,i_RMS": will return _RMS voltage_ and _RMS current_
  * "v,i,p,q": will return _voltage_, _current_, _active_, and _reactive power_
  * Default: "v,i"

* ```<prefix>``` (optional):
  * "true" or "false": if _true_, each chunk of measurement will be sent with the prefix ```"Data:"<chunk_length><packet_num><data>```
  * ```<chunk_length>```: 2 bytes stating the length the amount of bytes in ```<data>```, format: _```<H```_
  * ```<packet_num>```: running packet number as 4 bytes integer, format: _```<I```_
  * Default: _true_

* ```<ntpConf>``` (optional):
  * Integer, interpreted as milliseconds. The NTP request before starting the sampling needs to be confident within this threshold value. 
  * NOTE: NTP requests are send over UDP to the specified NTP server. The time it takes to get the answer needs to be considered as well for millisecond resolution. As the request has to be sent to the server and from the server back to the [PowerMeter], half of the time the request took is added to the received NTP time. The request is thus only confident up to the time it took to receive the response, as in the worst case - if a response took 10ms - it could be 0ms for sending to the server and 10ms for getting the response. This would mean, the time is off the actual time about 5ms - which is our confidence level. As most sampling is stored relative (start time + sampling rate), getting the start time as exact as possible is crucial. 
  * Default: no NTP request is sent

* ```<flowCtr>``` (optional):
  * "true" or "false": if _true_, the sink has to request _x_ amount of samples with the ```reqSamples``` command or actively enable sending with a [cts](#pause-streaming) command.
  * Default: _false_
  * Request ```<numSamples>``` using the command: ```{"cmd":"reqSamples","samples":<numSamples>}```
    * ```<numSamples>```: long, must be between 10 and 2000
    * NOTE: In order for the command to work, the [PowerMeter] must be sampling and during the sampling command ```flowCtr``` must have been set to _true_!

* ```<time>``` (optional):
  * Unix timestamp at which sampling should be started. The timestamp must be in the future more than 500ms but is not allowed to be further in time then 20s. 
  * NOTE: This can be used to start sampling with multiple devices at an exact point in time. Sampling further starts at a positive voltage zero crossing. Therewith, PowerMeters at the same phase are synchronized within 1/f<sub>L</sub> with f<sub>L</sub> being the grid line frequency.  
  * Default: Sampling is started immediately 

* ```[<slot>,<slots>]``` (optional):
  * ```<slot>``` integer, the slot number in which data is sent
  * ```<slots>``` integer, the total number of slots
  * The idea is that only one device sends data at the same time in a network with multiple device ```d_i```. Each device will only send data if the following condition is true: ```now.seconds%slots == slot```
  * Example: 3 devices _d<sub>i</sub>_ with configs: _d<sub>0</sub> = [0,3]_, _d<sub>1</sub> = [1,3]_, _d<sub>2</sub> = [2,3]_. All devices send data each 3 seconds. e.g. _d<sub>0</sub>_ at second _0,3,6,..._ 
  * NOTE: This only works, if all data sampled can be send out in this second. If you e.g. have 10 devices, one device has to send 10s of data every 10s within just 1s. If the PowerMeter is not able to sent all data within this second, buffer overflows will occur. However, it avoids wifi/tcp collisions caused by multiple PowerMeters.
  * Default: _false_

### Pause streaming
You can use flow control during sampling with the command: ```{"cmd":"cts","value":<value>}```
* ```<value>``` can be _true_ or _false_. _True_ to let device stream data, _false_ to pause.
* NOTE: does not necessarily have to be paired with sampling in which ```flowCtr``` was set to _true_.

### Stop streaming 
```{"cmd":"stop"}```\
Send this command to stop sampling or streaming. As a response, you get information about the sampling process.
```bash
Info:{"msg":"Received stop command","sample_duration":16157,"samples":16,"sent_samples":16,"start_ts":"1614697441.119","stop_ts":"1614697457.276","ip":"192.168.0.138","avg_rate":0.955618,"cmd":"stop"}
```

## Misc
### Availability
You can send ```?``` without a JSON encoding to test if the device is still reachable. It will return ```Info: Setup done``` and will stop sampling! (Just for backward compatibility)

### Keepalive
As a keepalive command, you can send ```!```. This simply gets ignored but might prevent the TCP connection from being closed automatically if nothing is sent.

## Data Format
The data is returned encoded as 32 Bit MSB first float values.
If not explicitly disabled using ```"prefix":"false"```, data is preceded by a prefix.\
```"Data:"<chunk_length><packet_num><data>```
  * ```<chunk_length>```: 2 bytes describing the length of this data chunk, format: _```<H```_
  * ```<packet_num>```: running packet number as 4 bytes integer, format: _```<I```_
If disable or the stream type is set to FFMPEG, just the ```<data>``` is returned.

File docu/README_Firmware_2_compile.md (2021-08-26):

[PowerMeter]: (https://github.com/voelkerb/PowerMeter)

# How to compile Firmware Version 2

## Preprocessor Settings

Before you want to compile the code, make sure the preprocessor settings are as you want them to be.
Take a look at [constDefine.h](https://github.com/voelkerb/PowerMeter/blob/master/Firmware/Version_2/constDefine.h).
The PowerMeter supports multiple addons such as LoRa or an additional sensor board. Depending on your configuration, the preprocessor settings must be set correctly. 

### Standard Settings:
You can set some standard WiFi configurations which will also be kept on a configuration reset. Simply add you WiFi credentials to a file named ```privateConfig.h``` under _src/config/_  
```c++
#define NUM_STANDARD_WIFIS 2

const char * MY_STANDARD_WIFIS[] = {
     /*SSID*/ "mySecretAP1", /*PWD*/ "mySecret1",
     /*SSID*/ "mySecretAP2", /*PWD*/ "mySecret2",
};
```

### General Settings:

* ```SENT_LIFENESS_TO_CLIENTS```: Uncomment to send lifeness messages with the current system time each second to connected TCP clients or over serial.
* ```REPORT_ENERGY_ON_LIFENESS```: Uncomment to send energy info as lifeness messages.
* ```LIFENESS_UPDATE_INTERVAL```: Interval for sending lifeness messages.
* ```SEND_INFO_ON_CLIENT_CONNECT```: Uncomment to send system info JSON dictionary automatically on TCP client connect.
* ```USE_SERIAL```: Comment to disable serial, uncomment if you want to use serial.
* ```SERIAL_SPEED```: Baudrate of any serial connection. The serial connectors are accessible via the extension header.
* ```SERIAL_LOGGER```: Uncomment if you want log messages to be sent via serial.
* ```LOG_PREFIX_SERIAL```: Prefix for logs over serial connection.
* ```CMD_OVER_SERIAL```: Uncomment if you want commands to be processed via serial.
* ```PS_BUF_SIZE```: Amount of PSRAM for data buffering. Arduino does only support up to 3.5MB.
* ```DEFAULT_SR```: Default samplingrate.
* ```LOCATION_TIME_OFFSET```: Location time offset from UTC. 
* ```MDNS_UPDATE_INTERVAL```: Interval for MDNS updates.
* ```TCP_UPDATE_INTERVAL```: Interval for adding TCP clients.
* ```RTC_UPDATE_INTERVAL```: Interval for updating the RTC's time.
* ```ENERGY_UPDATE_INTERVAL```: Interval energy is stored to flash. If no energy is reported, this is also the interval it is updated. As energy register overflows around each 19Wh, keep it smaller than ```t < 19Wh*3600s/MAX_POWER```. With a worst case ```MAX_POWER``` of ```3600W``` this results in around ```19s```. 
* ```STREAM_SERVER_UPDATE_INTERVAL```: Interval for checking if an external TCP server is ready to receive data.
* ```MQTT_UPDATE_INTERVAL```: Interval to send energy info over MQTT.
* ```LOG_PREFIX```: Prefix for logs via TCP connection.
* ```DATA_PREFIX```: Prefix for data via TCP connection.

### Connection Settings:

* ```STANDARD_UDP_PORT```: Standard port for UDP connections.
* ```STANDARD_TCP_SAMPLE_PORT```: Standard port for TCP connections.
* ```STANDARD_TCP_STREAM_PORT```: Standard port for TCP streaming e.g. via ffmpeg.
* ```MAX_CLIENTS```: Allow at max this many TCP clients.
* ```MAX_SEND_SIZE```: Maximum chunk size for data. Chunksize is set dynamically depending on the samplingrate.  

### NTP Sampling Correction

* ```NTP_CORRECT_SAMPLINGRATE```: If NTP synchronizations should be used to correct the sampling rate by means of repeating or leaving out samples.
* ```NTP_CONFIDENCE_FOR_CORRECTION```: Required confidence for NTP sampling correction in milliseconds.
* ```CORRECT_SAMPLING_THRESHOLD```: Drift in seconds when sampling correction should be applied.
* ```MAX_CORRECT_SAMPLES```: Maximum number of samples to correct for one sync.

### LoRaWAN Settings:

* ```LORA_WAN```: Comment to disable, uncomment to enable LoRaWAN connection via an extension board with AT command firmware (e.g. [Grove LoRa E5](https://wiki.seeedstudio.com/Grove_LoRa_E5_New_Version/)). Therewith you can e.g. connect to [The Things Network](https://www.thethingsnetwork.org). Lora Credentials (such as ```APP_KEY```, ```APP_EUI``` and ```DEV_EUI``` - in case of LoRaWAN OTA Authentification) should be stored in an external ```privateConfig.h``` file in the base folder of the specific firmware (see [constDefine.h](https://github.com/voelkerb/PowerMeter/blob/master/Firmware/Version_2/constDefine.h) for more details).
* ```APP_KEY```: Application key of OTA activation for TTN network.
* ```DEV_EUI```: Device EUI for TTN network.
* ```APP_EUI```: Application EUI of OTA activation for TTN network.
* ```LORA_PORT```: Port over which data is sent and received.

### SensorBoard Settings:

* ```SENSOR_BOARD```: Comment to disable, uncomment to enable SensorBoard connection via the custom [SensorBoard](https://github.com/voelkerb/powermeter.sensorboard/). Therewith you can measure temperature, humidity, light and people's motion next to the [PowerMeter]. It further has a button to toggle the relay and LEDs to indicate the current power consumption and interactions with the [PowerMeter]
* ```SENSOR_UPDATE_INTERVALL```: Update interval for sensor measurements if in latch mode. In the automatic mode, sensor values are sent by the SensorBoard if they have changed.

## Compile from source using Arduino or PlatformIO

* In order to upload the firmware, you must install the latest version of the Arduino ESP32 environment. See [official instructions](https://github.com/espressif/arduino-esp32/blob/master/docs/arduino-ide/boards_manager.md):
  * Enter _https://raw.githubusercontent.com/espressif/arduino-esp32/gh-pages/package_esp32_index.json_ into _Arduino > Settings > Additional Board Manager URLs_ field.
  * Open Boards Manager from _Tools > Board_ menu and install _esp32 platform_
* Select _ESP32 Dev kit_ with _240MHz_ and _PSRAM enabled_ from _Tools > Board_ 

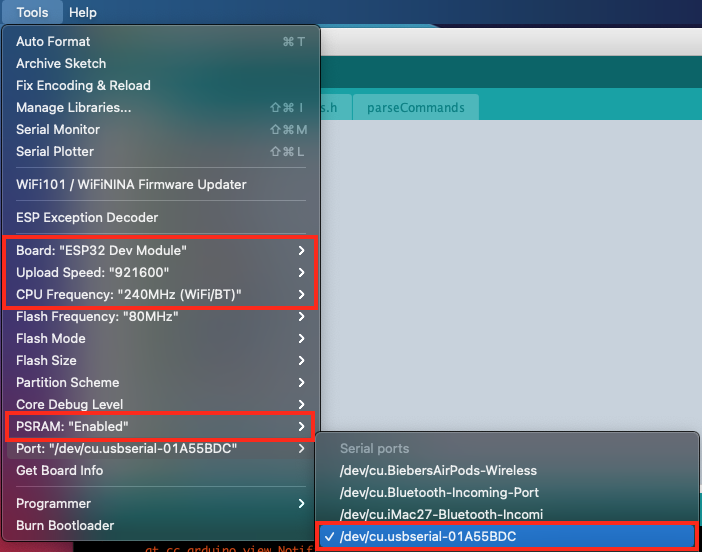
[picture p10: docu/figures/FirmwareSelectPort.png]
    
    
* Open the latest firmware "Version_X_X".
* Press _Compile_

## Upload using an FTDI

* Connect the [PowerMeter] to an FTDI according to the following wiring: 

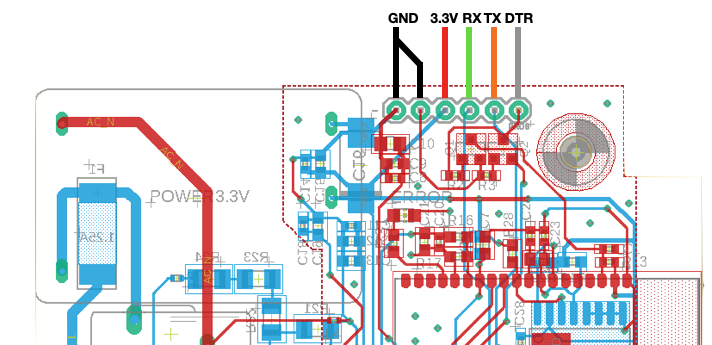
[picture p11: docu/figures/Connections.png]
  

* Select no more than 2Mbauds
* Press _Compile and Upload_

## Upload using Arduino-OTA

* Select the [PowerMeter] you want to upload to from the available network ports
* If the corresponding [PowerMeter] is not shown, make sure you are in the same network or try to reset the [PowerMeter] (unplug it from the socket and plug it back in).

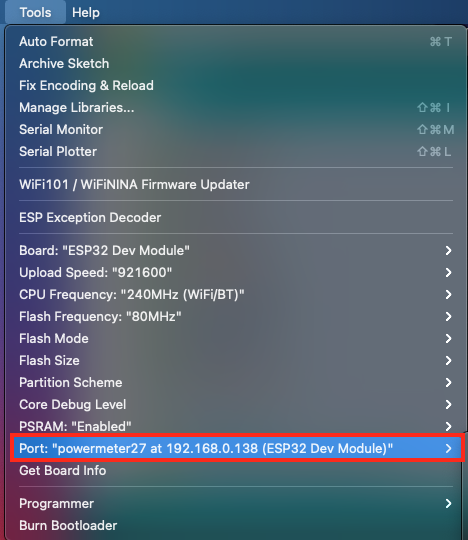
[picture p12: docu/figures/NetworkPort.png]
    

* Upload using password "energy"

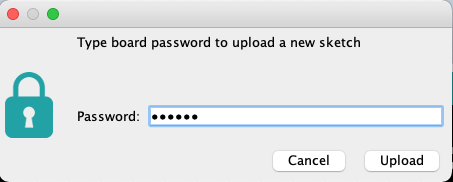
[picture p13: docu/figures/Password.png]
    

## Upload using custom Uploader

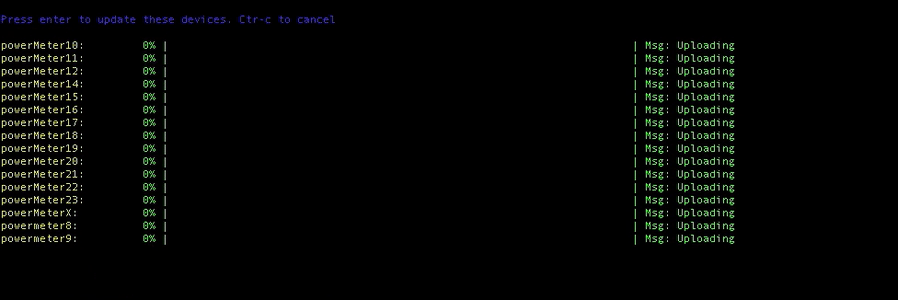
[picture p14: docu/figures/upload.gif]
  

* Compile the firmware
* Copy the path of the compiled binary _elf_ or _bin_ (the _bin_ will be used either way)

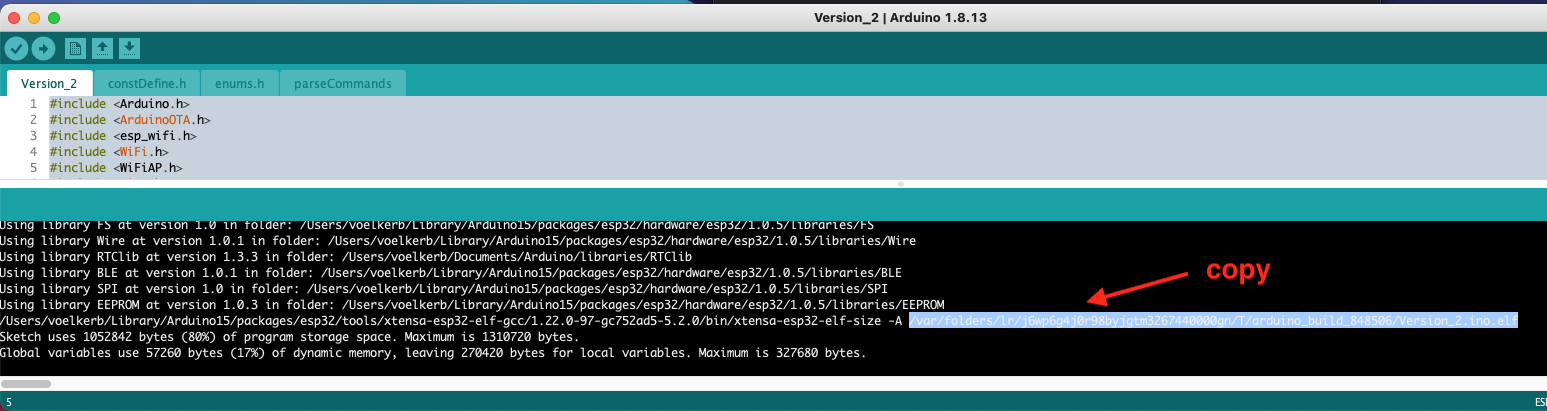
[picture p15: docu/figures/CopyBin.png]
    

* Use the upload script
  ```bash
  python3 upload.py PowerMeter <pathToElfOrBin> 
  ```
  Select one or mulitple [PowerMeter] from the provided list
  ```
  Available Devices:
  #  PowerMeter:              Device:                  IP:                      
  0  PowerMeter0              PowerMeter0              192.168.0.145            
  1  PowerMeter15             PowerMeter15             192.168.0.113            
  2  PowerMeter20             PowerMeter20             192.168.0.111            
  3  PowerMeter21             PowerMeter21             192.168.0.118            
  4  PowerMeter24             PowerMeter24             192.168.0.115            
  5  PowerMeter26             PowerMeter26             192.168.0.119            
  6  PowerMeter27             PowerMeter27             192.168.0.138            
  7  PowerMeter28             PowerMeter28             192.168.0.114            
  Press ENTER to continue with all devices.
  Deselect specific devices e.g.: -2,-4,-7
  Select specific devices e.g.: 1,3,5,6
  Search again a/A
  Press r/R to reset
  e/E to cancel Or press CTR-C to exit program
  ```
  Press enter and watch the magic

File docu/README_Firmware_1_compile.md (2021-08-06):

[PowerMeter]: (https://github.com/voelkerb/PowerMeter)

# How to compile firmware version 1

## Compile from source using Arduino or PlatformIO

* In order to upload the firmware, you must install the latest version of the Arduino ESP8266 environment. See [official instructions](https://github.com/esp8266/Arduino):
  * Enter _http://arduino.esp8266.com/stable/package_esp8266com_index.json_ into _Arduino > Settings > Additional Board Manager URLs_ field.
  * Open Boards Manager from _Tools > Board_ menu and install _esp8266 platform_
  * Select _Node MCU 1.0_ from _Tools > Board_ 
  * Select a reasonable fast _upload speed_ and select _160 MHz_ as the _CPU Frequency_
    
* Open the latest firmware "Version_X_X".
* Press _Compile_

## Upload using USB

* Plug the [PowerMeter] into a socket, as it is requires for power supply 
* Connect the [PowerMeter] over micro USB to you PC. The USB connection is galvanically isolated - so do not panick.
* Select no more than 2Mbauds
* Press _Compile and Upload_

## Upload using Arduino-OTA

* Select the [PowerMeter] you want to upload to from the avaialble network ports
* If the corresponding [PowerMeter] is not shown, make sure you are in the same network or try to reset the [PowerMeter] (unplug it from the socket and plug it back in).

    

* Upload using password "energy"

    

## Upload using custom Uploader

  

* Compile the firmware
* Copy the path of the compiled binary _elf_ or _bin_ (the _bin_ will be used either way)

    

* Use the upload script
  ```bash
  python3 upload.py PowerMeter <pathToElfOrBin> 
  ```
  Select one or mulitple [PowerMeter] from the provided list
  ```
  Available Devices:
  #  PowerMeter:              Device:                  IP:                      
  0  PowerMeter0              PowerMeter0              192.168.0.145            
  1  PowerMeter15             PowerMeter15             192.168.0.113            
  2  PowerMeter20             PowerMeter20             192.168.0.111            
  3  PowerMeter21             PowerMeter21             192.168.0.118            
  4  PowerMeter24             PowerMeter24             192.168.0.115            
  5  PowerMeter26             PowerMeter26             192.168.0.119            
  6  PowerMeter27             PowerMeter27             192.168.0.138            
  7  PowerMeter28             PowerMeter28             192.168.0.114            
  Press ENTER to continue with all devices.
  Deselect specific devices e.g.: -2,-4,-7
  Select specific devices e.g.: 1,3,5,6
  Search again a/A
  Press r/R to reset
  e/E to cancel Or press CTR-C to exit program
  ```
  Press enter and watch the magic

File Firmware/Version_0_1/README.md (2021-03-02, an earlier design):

[powermeter]: (https://github.com/voelkerb/powermeter)

# Firmware Version 0.1

## Supported Hardware
This firmware version supports Hardware Revision 1.

## Legacy Notice
This firmware is no longer supported. Please use [Version 1](../Version_1/README.md)

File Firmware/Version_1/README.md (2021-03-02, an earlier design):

[powermeter]: (https://github.com/voelkerb/powermeter)

# Firmware Version 1

## Supported Hardware
This firmware version supports Hardware Revision 1.

## [Firmware Commands](/docu/README_Firmware_Cmds.md)

## [Compilation](/docu/README_Firmware_1_compile.md)

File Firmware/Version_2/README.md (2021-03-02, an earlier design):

[powermeter]: (https://github.com/voelkerb/powermeter)

# Firmware Version 2

## Supported Hardware
This firmware version supports Hardware Revision 2.

## [Firmware Commands](/docu/README_Firmware_Cmds.md)

## [Compilation](/docu/README_Firmware_2_compile.md)

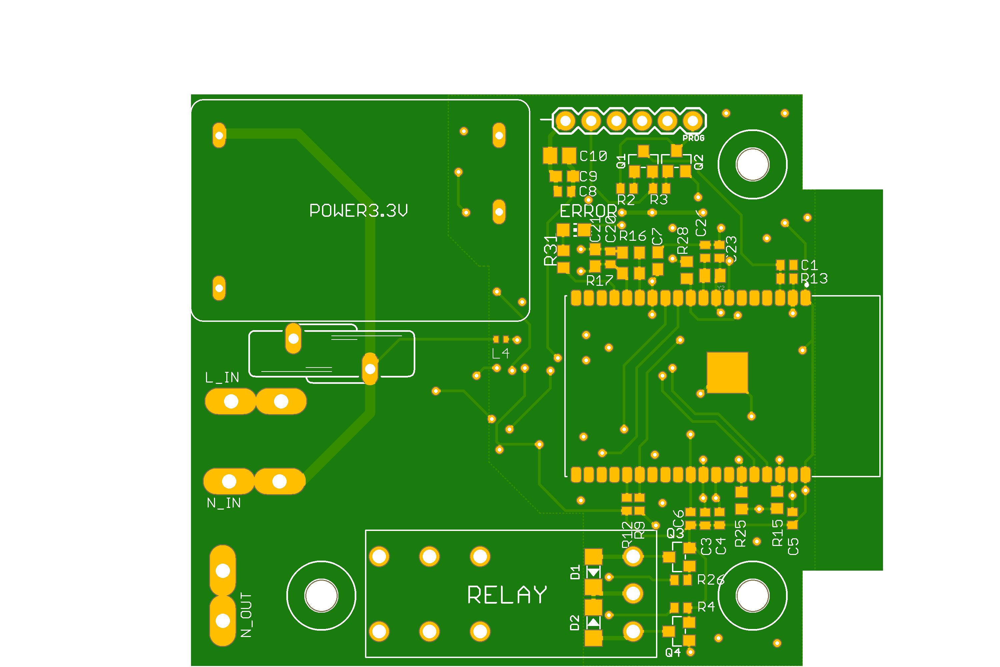
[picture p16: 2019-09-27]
Schematic/Version_2/powermeterV2_top.png

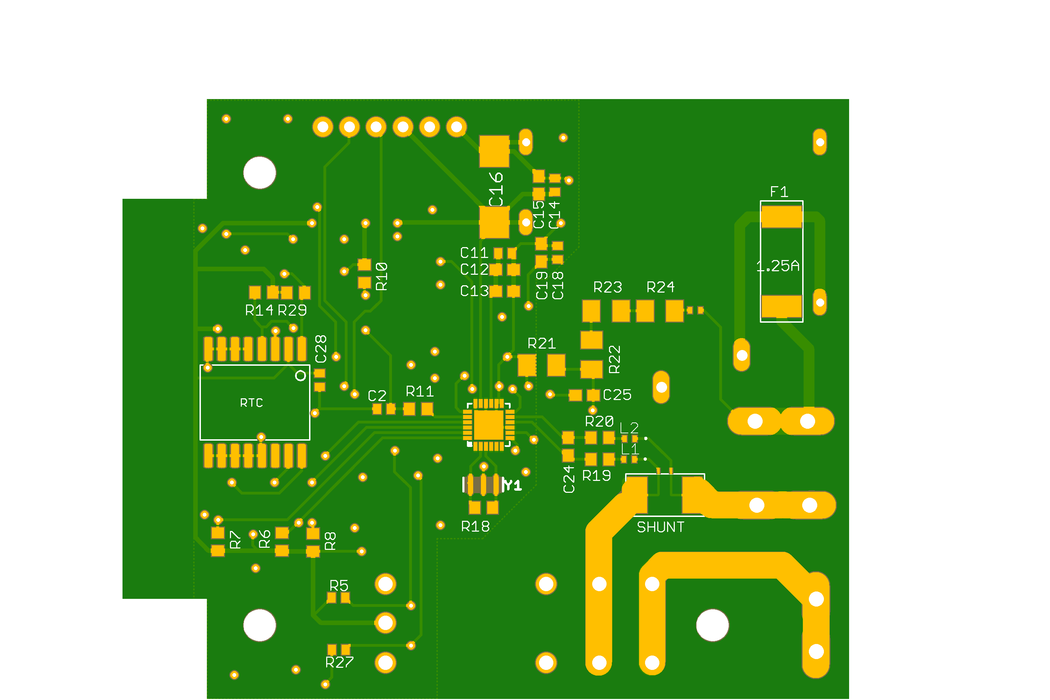
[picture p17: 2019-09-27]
Schematic/Version_2/powermeterV2_bot.png

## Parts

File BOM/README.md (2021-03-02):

[powermeter]: (https://github.com/voelkerb/powermeter)

# BOM
| Schematic Reference | Qty/Board | MPN | Description | Line Item | Octopart URL |
|---|---|---|---|---|---|
| Power | 1 | IRM-02-3.3 | Power adapter | IRM-02-3.3 | https://octopart.com/irm-02-3.3-mean+well-74649647 |
| F1 | 1 | 3403.0167.11 | Fuse | 3403.0167.11 | https://octopart.com/3403.0167.11-schurter-107903 |
| Q1, Q2, Q3, Q4 | 4 | MMSS8050-L-TP | Transistor | MMSS8050-L-TP | https://octopart.com/mmss8050-l-tp-mcc-21709877 |
| Y1 | 1 | CSTCE16M0V53-R0 | Crystal | CSTCE16M0V53-R0 | https://octopart.com/cstce16m0v53-r0-murata-314372 |
| ESP | 1 | ESP32-WROVER-B | ESP | ESP32-WROVER-B | https://octopart.com/esp32-wrover-b-espressif+systems-94918056 |
| Relais | 1 | 8-1393239-4 | Relais | RT314F03 | https://octopart.com/8-1393239-4-te+connectivity-40362663 |
| STPM | 1 | STPM32TR | Current measure IC | STPM32TR | https://octopart.com/stpm32tr-stmicroelectronics-31004291 |
| SHUNT | 1 | WSLF25123L000FEA | Shunt | WSLF25123L000FEA | https://octopart.com/wslf25123l000fea-vishay-75451311 |
| R1 | 1 | B72210S0321K101 | Varistor | B72210S0321K101 | https://octopart.com/b72210s0321k101-epcos-11931378 |
| R2, R3, R13 | 3 | 7-1676481-8 | 12k | CPF0603B12KE1 | https://octopart.com/7-1676481-8-te+connectivity+%2F+amp-41874359 |
| R4-8, R10, R14, R28, R29 | 9 | CPF0603F10KC1 | 10k | CPF0603F10KC1 | https://octopart.com/cpf0603f10kc1-te+connectivity-42013076 |
| R19, R20, R26, R27 | 4 | CPF0603F1K0C1 | 1k | CPF0603F1K0C1 | https://octopart.com/cpf0603f1k0c1-te+connectivity-42013134 |
| R11, R16 | 2 | CPF0603B100RE | 100 | CPF0603B100RE | https://octopart.com/cpf0603b100re-te+connectivity-22738717 |
| R17 | 1 | CPF0603B22KE1 | 22k | CPF0603B22KE1 | https://octopart.com/cpf0603b22ke1-te+connectivity-9539435 |
| R18 | 1 | CRCW06031M00FKEA | 1M | CRCW06031M00FKEA | https://octopart.com/crcw06031m00fkea-vishay-39988003 |
| R21 | 1 | TNPW1206470RBEEN | 470 (large) | TNPW1206470RBEEN | https://octopart.com/tnpw1206470rbeen-vishay-42015781 |
| R22, R23, R24 | 3 | MMA02040C2703FB300 | 270k | MMA02040C2703FB300 | https://octopart.com/mma02040c2703fb300-vishay-44272846 |
| R15, R25 | 2 | CPF0603B4K75E1 | 4.7k | CPF0603B4K75E1 | https://octopart.com/cpf0603b4k75e1-te+connectivity-22739584 |
| R9, R12 | 0 | RT0402DRE075K1L | Not connected | RT0402DRE075K1L | https://octopart.com/rt0402dre075k1l-yageo-1447598 |
| R31 | 1 | CRGP0603F220R | 220Ohm | CRGP0603F220R | https://octopart.com/crgp0603f220r-te+connectivity-91018741 |
| L1, L2, L3, L4 | 4 | MMZ1005A152ET000 | Inductors | MMZ1005A152ET000 | https://octopart.com/mmz1005a152et000-tdk-51459017 |
| C2-6, C8, C11, C14, C18, C20 | 10 | GRM1555C1H151JA01D | 150p | GRM1555C1H151JA01D | https://octopart.com/grm1555c1h151ja01d-murata-196848 |
| C7, C24 | 2 | C0603C103K5RECAUTO | 10n | C0603C103K5RECAUTO | https://octopart.com/c0603c103k5recauto-kemet-81065496 |
| C9, C12, C15, C19, C21, C28  | 6 | VJ0603V104ZXAPW1BC | 100n (0603) | VJ0603V104ZXAPW1BC | https://octopart.com/vj0603v104zxapw1bc-vishay-44708075 |
| C10 | 1 | C0603C475K9PACTU | 4.7u | C0603C475k9PACTU | https://octopart.com/c0603c475k9pactu-kemet-104242 |
| C13 | 1 | 06033C104KAT2A | 1u | 06033C104KAT2A | https://octopart.com/06033c104kat2a-avx-39590598 |
| C16 | 1 | TAJD107K006SNJ | 100u | TAJD107K006SNJ | https://octopart.com/trjd107k016rrj-avx-17541841 |
| C1 | 1 | C0402C102K5RAC7411 | 1nF | C0402C102K5RAC7411 | https://octopart.com/c0402c102k5rac7411-kemet-51077941 |
| C25 | 1 | 06035C223KAT4A | 22n | 06035C223KAT4A | https://octopart.com/06035c223kat4a-avx-2680592 |
| C23, C26 | 1 | C0402C270J5GACTU | 27pF | C0402C270J5GACTU | https://octopart.com/c0402c270j5gactu-kemet-149444 |
| D1, D2 | 2 | 1N4148UR-1 | Freilaufdiode | 1N4148UR-1 or 1N4148W-HE3-08 | https://octopart.com/1n4148ur-1-microchip-95801106 |
| ERROR | 1 | LTST-C191KRKT | Error LED 0603 package | 859-LTST-C191KRKT | https://octopart.com/ltst-c191krkt-lite-on-549908 |
| Y2 | 0 | NX2012SA-32.768K-STD-MUB-1 | Not connected | NX2012SA-32.768K-STD-MUB-1 | https://octopart.com/nx2012sa-32.768k-std-mub-1-ndk-47319425 |
| RTC | 1 | DS3231S# | | 700-DS3231S | https://octopart.com/ds3231s%23-maxim+integrated-8253516 |
| Flat Headers | 3 | 1226275 | | | |
| Sum/Boards | 74 | | | | |

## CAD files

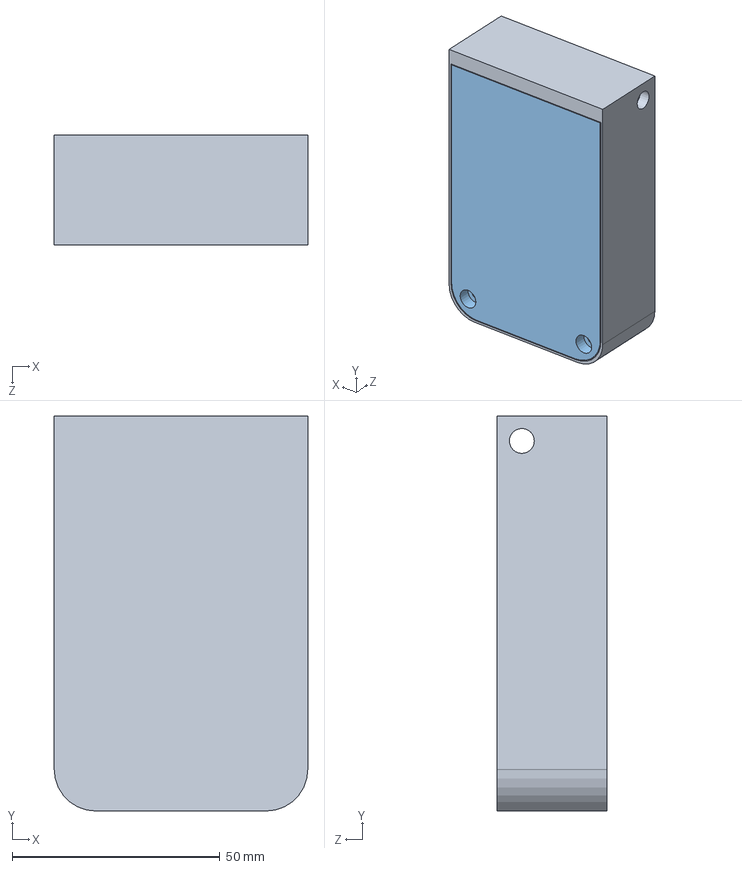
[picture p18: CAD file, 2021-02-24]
CAD/Assem1.SLDASM
61.0 x 95.0 x 26.5 mm
case_in_cable
platine
case_in_cable_top

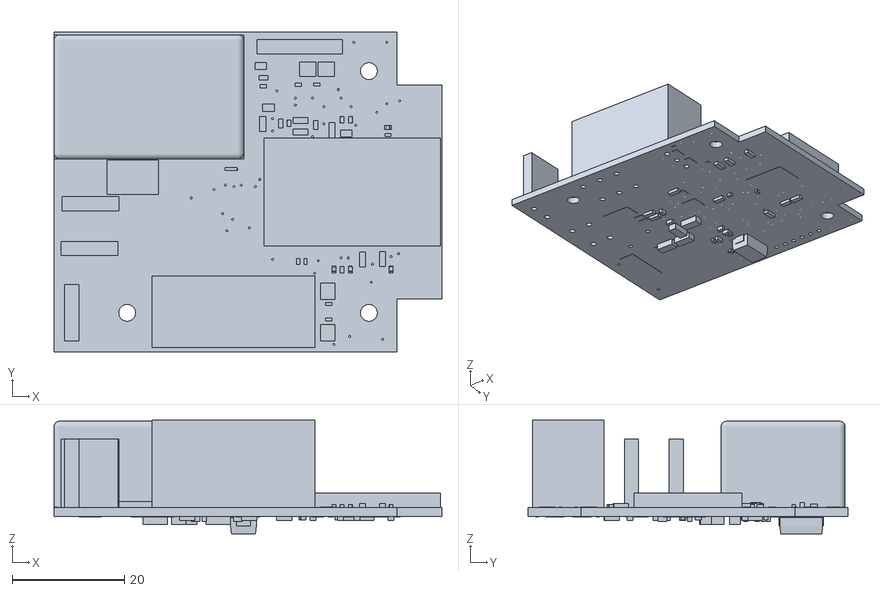
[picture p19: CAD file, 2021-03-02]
CAD/powermeterV2.stl
69.0 x 57.0 x 20.3

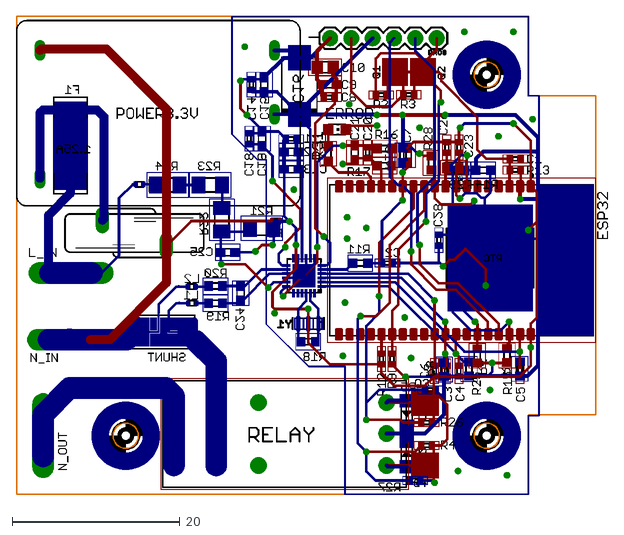
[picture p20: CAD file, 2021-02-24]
Schematic/Version_2/powermeterV2.dxf
70.5 x 57.1

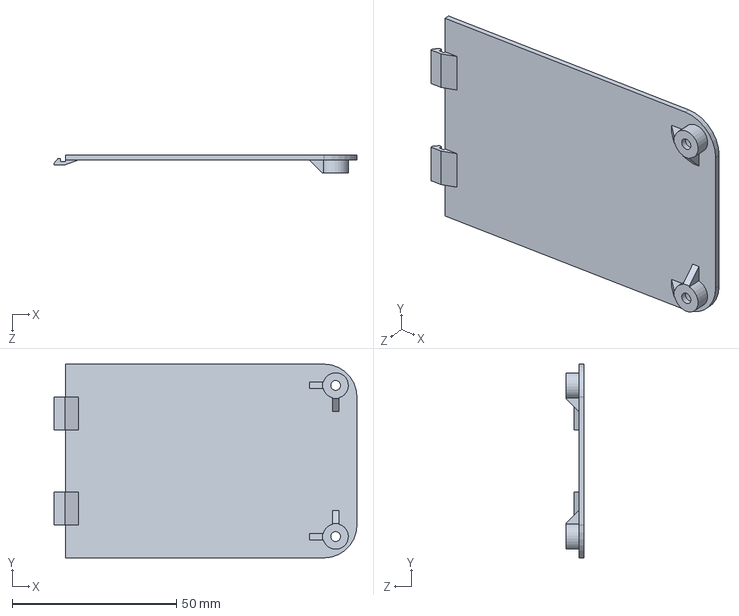
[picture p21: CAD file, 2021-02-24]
CAD/case_in_cable_top.SLDPRT
92.2 x 59.0 x 5.50 mm

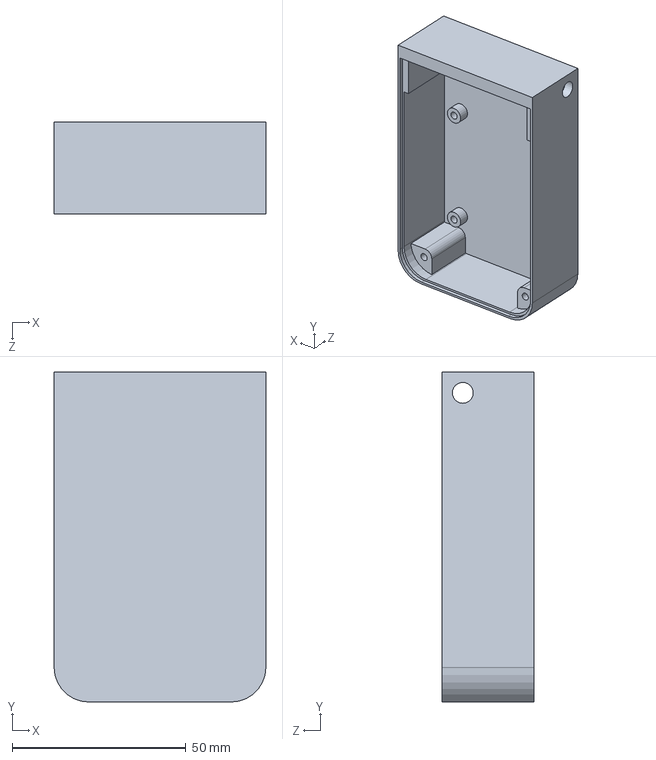
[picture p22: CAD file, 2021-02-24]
CAD/case_in_cable.SLDPRT
61.0 x 95.0 x 26.5 mm

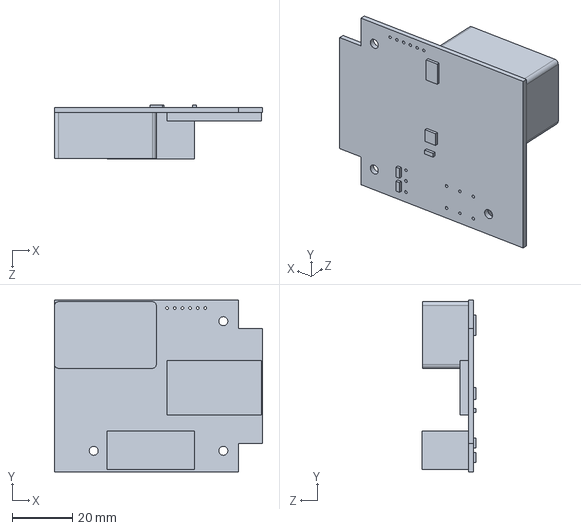
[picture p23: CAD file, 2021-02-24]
CAD/cuircuitBoard.SLDPRT
69.0 x 57.0 x 18.0 mm

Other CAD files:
CAD/case_in_cable.STL
CAD/case_in_cable_top.STL
CAD/powermeterV2.f3d

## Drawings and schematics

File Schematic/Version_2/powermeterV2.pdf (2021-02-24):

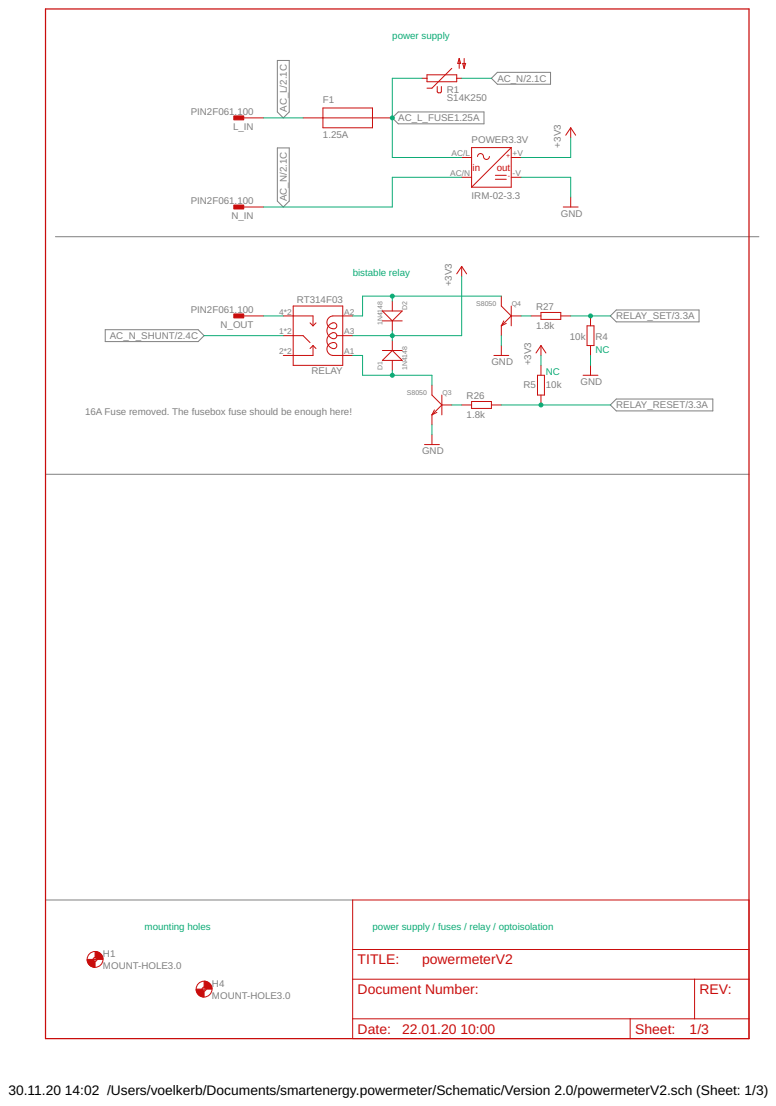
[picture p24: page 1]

16A Fuse removed. The fusebox fuse should be enough here!

power supply / fuses / relay / optoisolation

Document Number: | REV:

Date: 22.01.20 10:00 | Sheet: 1/3

30.11.20 14:02 /Users/voelkerb/Documents/smartenergy.powermeter/Schematic/Version 2.0/powermeterV2.sch (Sheet: 1/3)

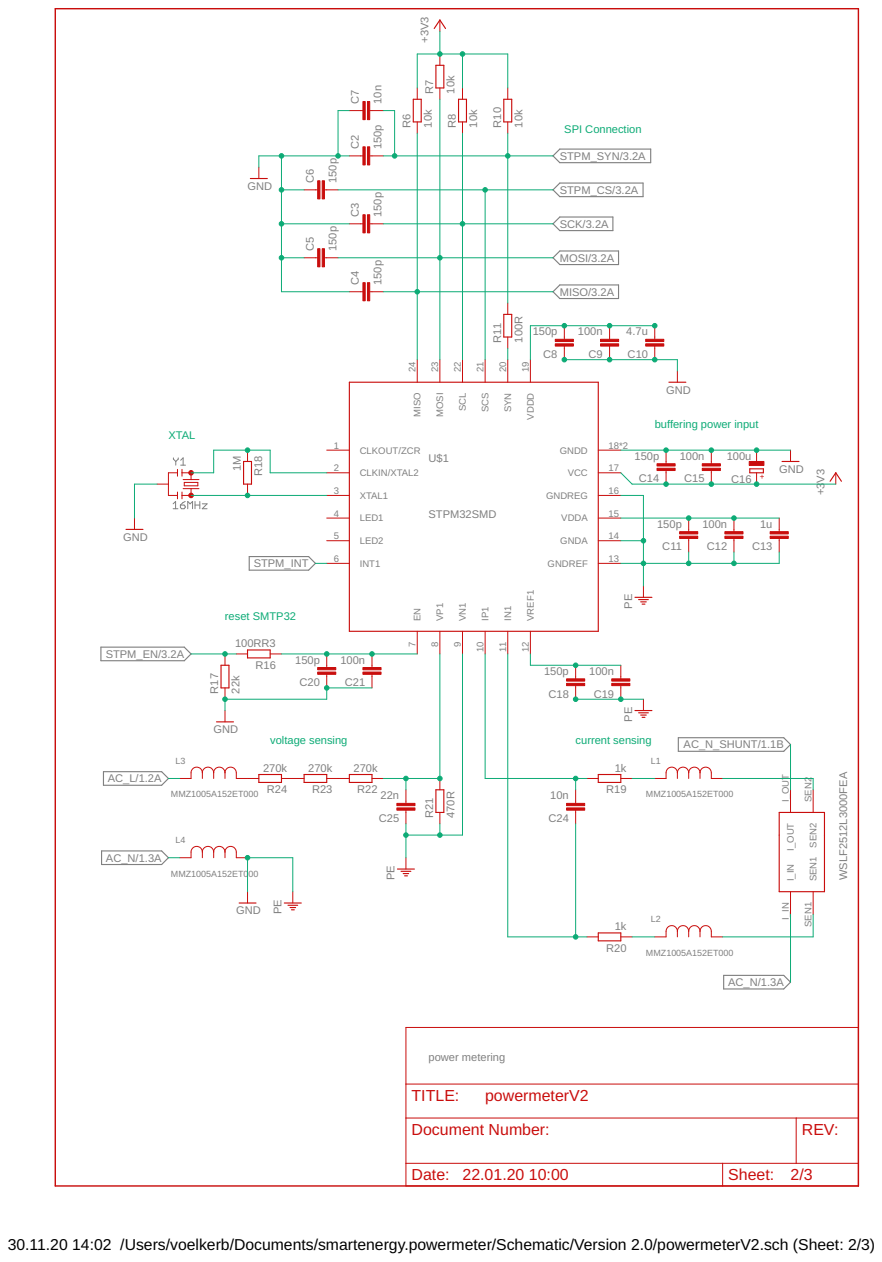
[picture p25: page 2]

30.11.20 14:02 /Users/voelkerb/Documents/smartenergy.powermeter/Schematic/Version 2.0/powermeterV2.sch (Sheet: 2/3)

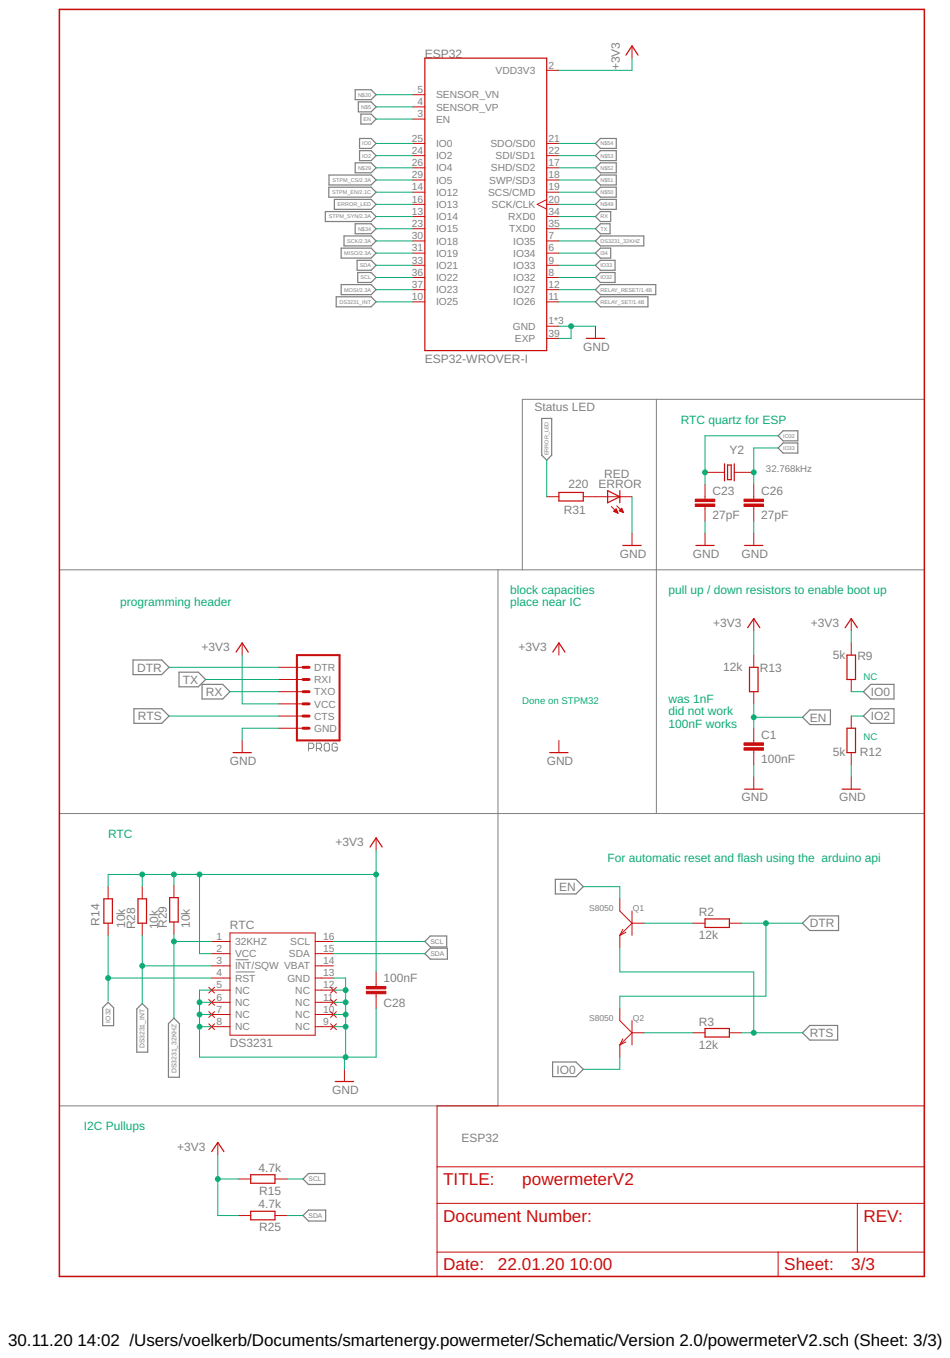
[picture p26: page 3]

RTC quartz for ESP

block capacities place near IC

pull up / down resistors to enable boot up

For automatic reset and flash using the arduino api

30.11.20 14:02 /Users/voelkerb/Documents/smartenergy.powermeter/Schematic/Version 2.0/powermeterV2.sch (Sheet: 3/3)

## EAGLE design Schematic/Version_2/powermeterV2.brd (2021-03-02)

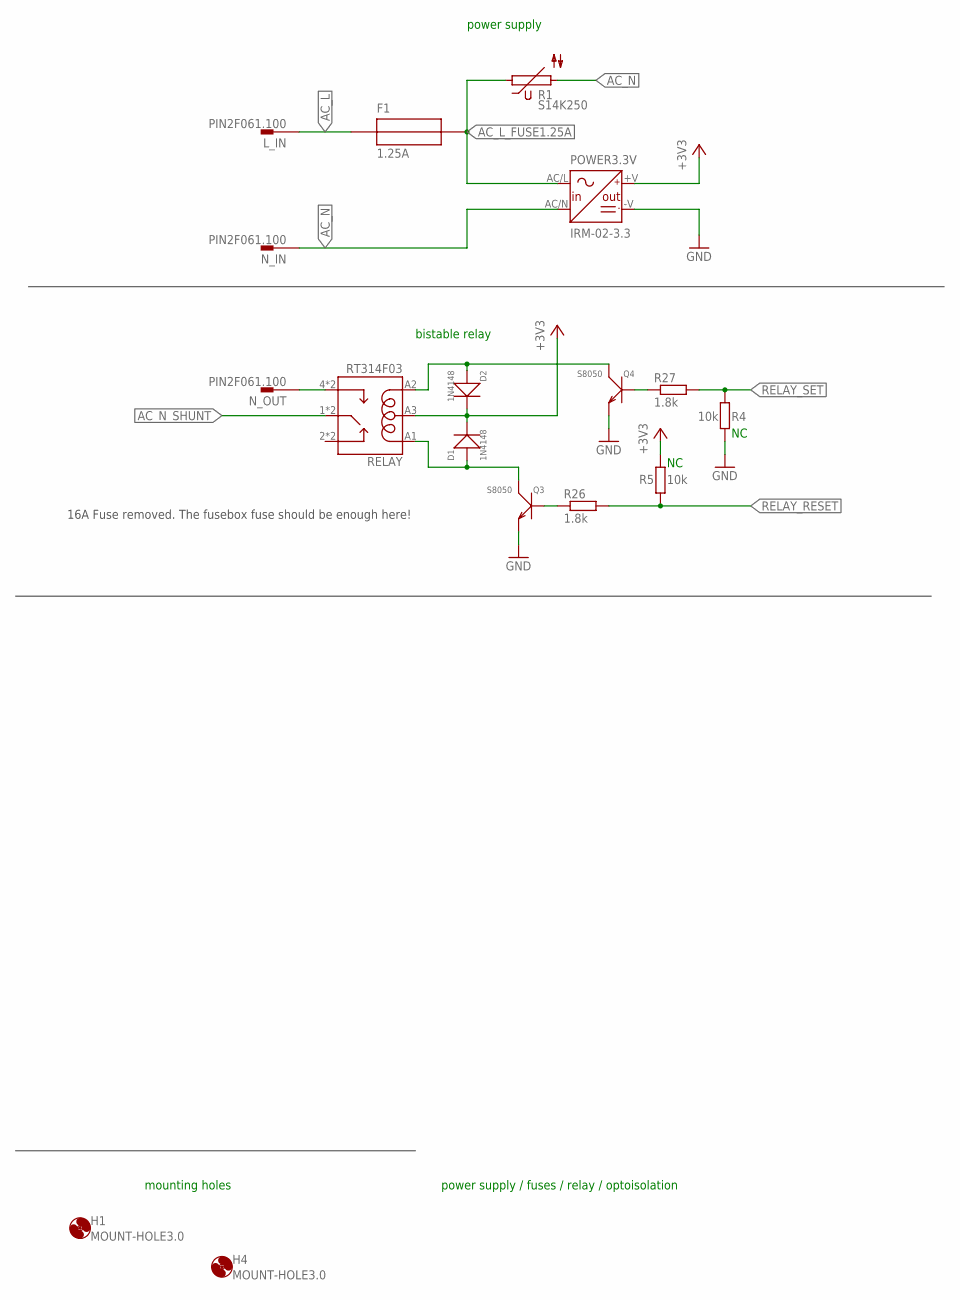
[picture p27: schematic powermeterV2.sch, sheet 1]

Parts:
D1, D2: 1N4148; LL-34
F1: 1.25A; SMD_FUSE
H1, H4: MOUNT-HOLE3.0; 3,0
L_IN: PIN2F061.100; F061.100
N_IN: PIN2F061.100; F061.100
N_OUT: PIN2F061.100; F061.100
POWER3.3V: IRM-02-3.3; MW_IRM-02
Q3, Q4: S8050; SOT-23
R1: S14K250
R4, R5: 10k; R0402
R26, R27: 1.8k; R0402
RELAY: RT314F03; RELAY_RT314F03

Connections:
+3V3: D1.C (-), D2.C (-), POWER3.3V.+V (+V_OUT), R5.2, RELAY.A3; also elsewhere on the board
AC_L: F1.P$1 (1), L_IN.A1, L_IN.A2; also elsewhere on the board
AC_L_FUSE1.25A: F1.P$2 (2), POWER3.3V.AC/L (L), R1.1
AC_N: N_IN.A1, N_IN.A2, POWER3.3V.AC/N (N), R1.2; also elsewhere on the board
AC_N_SHUNT: RELAY.1 (11), RELAY.11; also elsewhere on the board
GND: POWER3.3V.-V (-V_OUT), Q3.2 (E), Q4.2 (E), R4.2; also elsewhere on the board
unnamed: N_OUT.A1, N_OUT.A2, RELAY.4 (14), RELAY.14
unnamed: Q3.1 (B), R26.1
unnamed: D1.A (+), Q3.3 (C), RELAY.A1
unnamed: Q4.1 (B), R27.1
unnamed: D2.A (+), Q4.3 (C), RELAY.A2
RELAY_RESET: R5.1, R26.2; also elsewhere on the board
RELAY_SET: R4.1, R27.2; also elsewhere on the board

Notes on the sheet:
power supply / fuses / relay / optoisolation
power supply
bistable relay
mounting holes
16A Fuse removed. The fusebox fuse should be enough here!

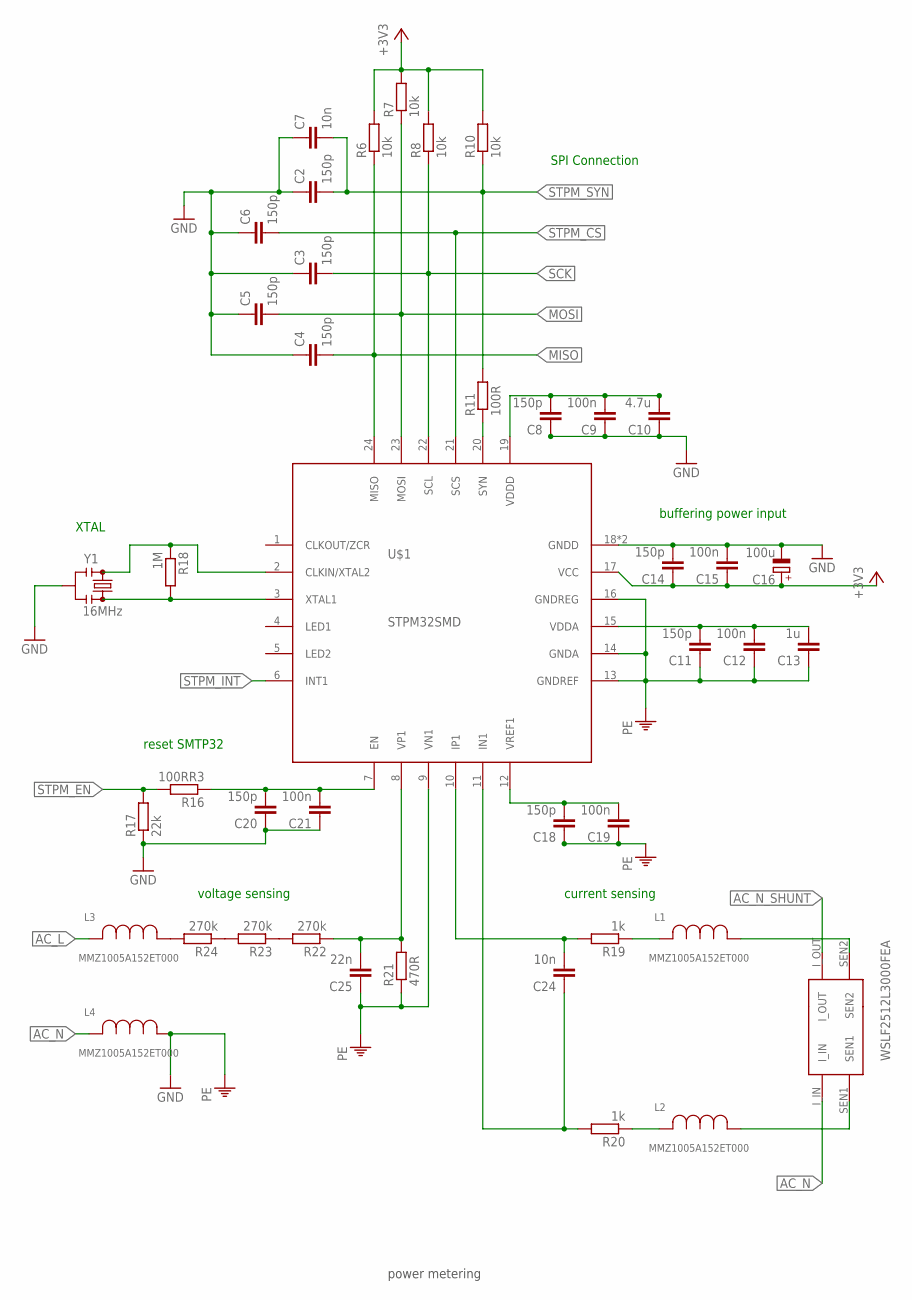
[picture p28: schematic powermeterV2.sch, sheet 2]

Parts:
C2, C3, C4, C5, C6, C8, C11, C14, C18, C20: 150p; C0402
C7, C24: 10n; C0603
C9, C12, C15, C19, C21: 100n; C0603
C10: 4.7u; C0805
C13: 1u; C0603
C16: 100u; D/7343-31W
C25: 22n; C0603
L1, L2, L3, L4: MMZ1005A152ET000; IND_1005
R6, R7, R8, R10: 10k; R0603
R11: 100R; R0603
R16: 100RR3; R0603
R17: 22k; R0603
R18: 1M; R0603
R19, R20: 1k; R0603
R21: 470R; M1206
R22, R23, R24: 270k; M1206
SHUNT: WSLF2512L3000FEA; SMD_SHUNT
U$1: STPM32SMD; QFN24
Y1: 16MHz; RESONATOR-SMD-3.2X1.3

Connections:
+3V3: C14.1, C15.1, C16.+, R6.2, R7.2, R8.2, R10.2, U$1.17 (VCC); also elsewhere on the board
AC_L: L3.2; also elsewhere on the board
AC_N: L4.2, SHUNT.I_IN; also elsewhere on the board
AC_N_SHUNT: SHUNT.I_OUT; also elsewhere on the board
DC_GND1: C18.2, C19.2, U$1.12 (VREF1)
DC_GND2: C20.2, C21.2, R16.1, U$1.7 (EN)
GND: C2.1, C3.1, C4.1, C5.1, C6.1, C7.1, C8.1, C9.1, C10.1, C11.1, C12.1, C13.1, C14.2, C15.2, C16.-, C18.1, C19.1, C20.1, C21.1, C25.1, L4.1, R17.1, R21.1, U$1.9 (VN1), U$1.13 (GNDREF), U$1.14 (GNDA), U$1.16 (GNDREG), U$1.18 (GNDD), U$1.EXP (GNDD), Y1.2; also elsewhere on the board
MISO: C4.2, R6.1, U$1.24 (MISO); also elsewhere on the board
MOSI: C5.2, R7.1, U$1.23 (MOSI); also elsewhere on the board
unnamed: C8.2, C9.2, C10.2, U$1.19 (VDDD)
unnamed: C11.2, C12.2, C13.2, U$1.15 (VDDA)
unnamed: R18.2, U$1.3 (XTAL1), Y1.3
unnamed: R18.1, U$1.2 (CLKIN/XTAL2), Y1.1
unnamed: C24.1, R20.2, U$1.11 (IN1)
unnamed: R11.1, U$1.20 (SYN)
unnamed: C24.2, R19.2, U$1.10 (IP1)
unnamed: C25.2, R21.2, R22.1, U$1.8 (VP1)
unnamed: R23.2, R24.1
unnamed: R22.2, R23.1
unnamed: L3.1, R24.2
unnamed: L1.2, R19.1
unnamed: L2.2, R20.1
unnamed: L1.1, SHUNT.SEN2
unnamed: L2.1, SHUNT.SEN1
SCK: C3.2, R8.1, U$1.22 (SCL); also elsewhere on the board
STPM_CS: C6.2, U$1.21 (SCS); also elsewhere on the board
STPM_EN: R16.2, R17.2; also elsewhere on the board
STPM_INT: U$1.6 (INT1)
STPM_SYN: C2.2, C7.2, R10.1, R11.2; also elsewhere on the board

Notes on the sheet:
power metering
SPI Connection
buffering power input
reset SMTP32
XTAL
current sensing
voltage sensing

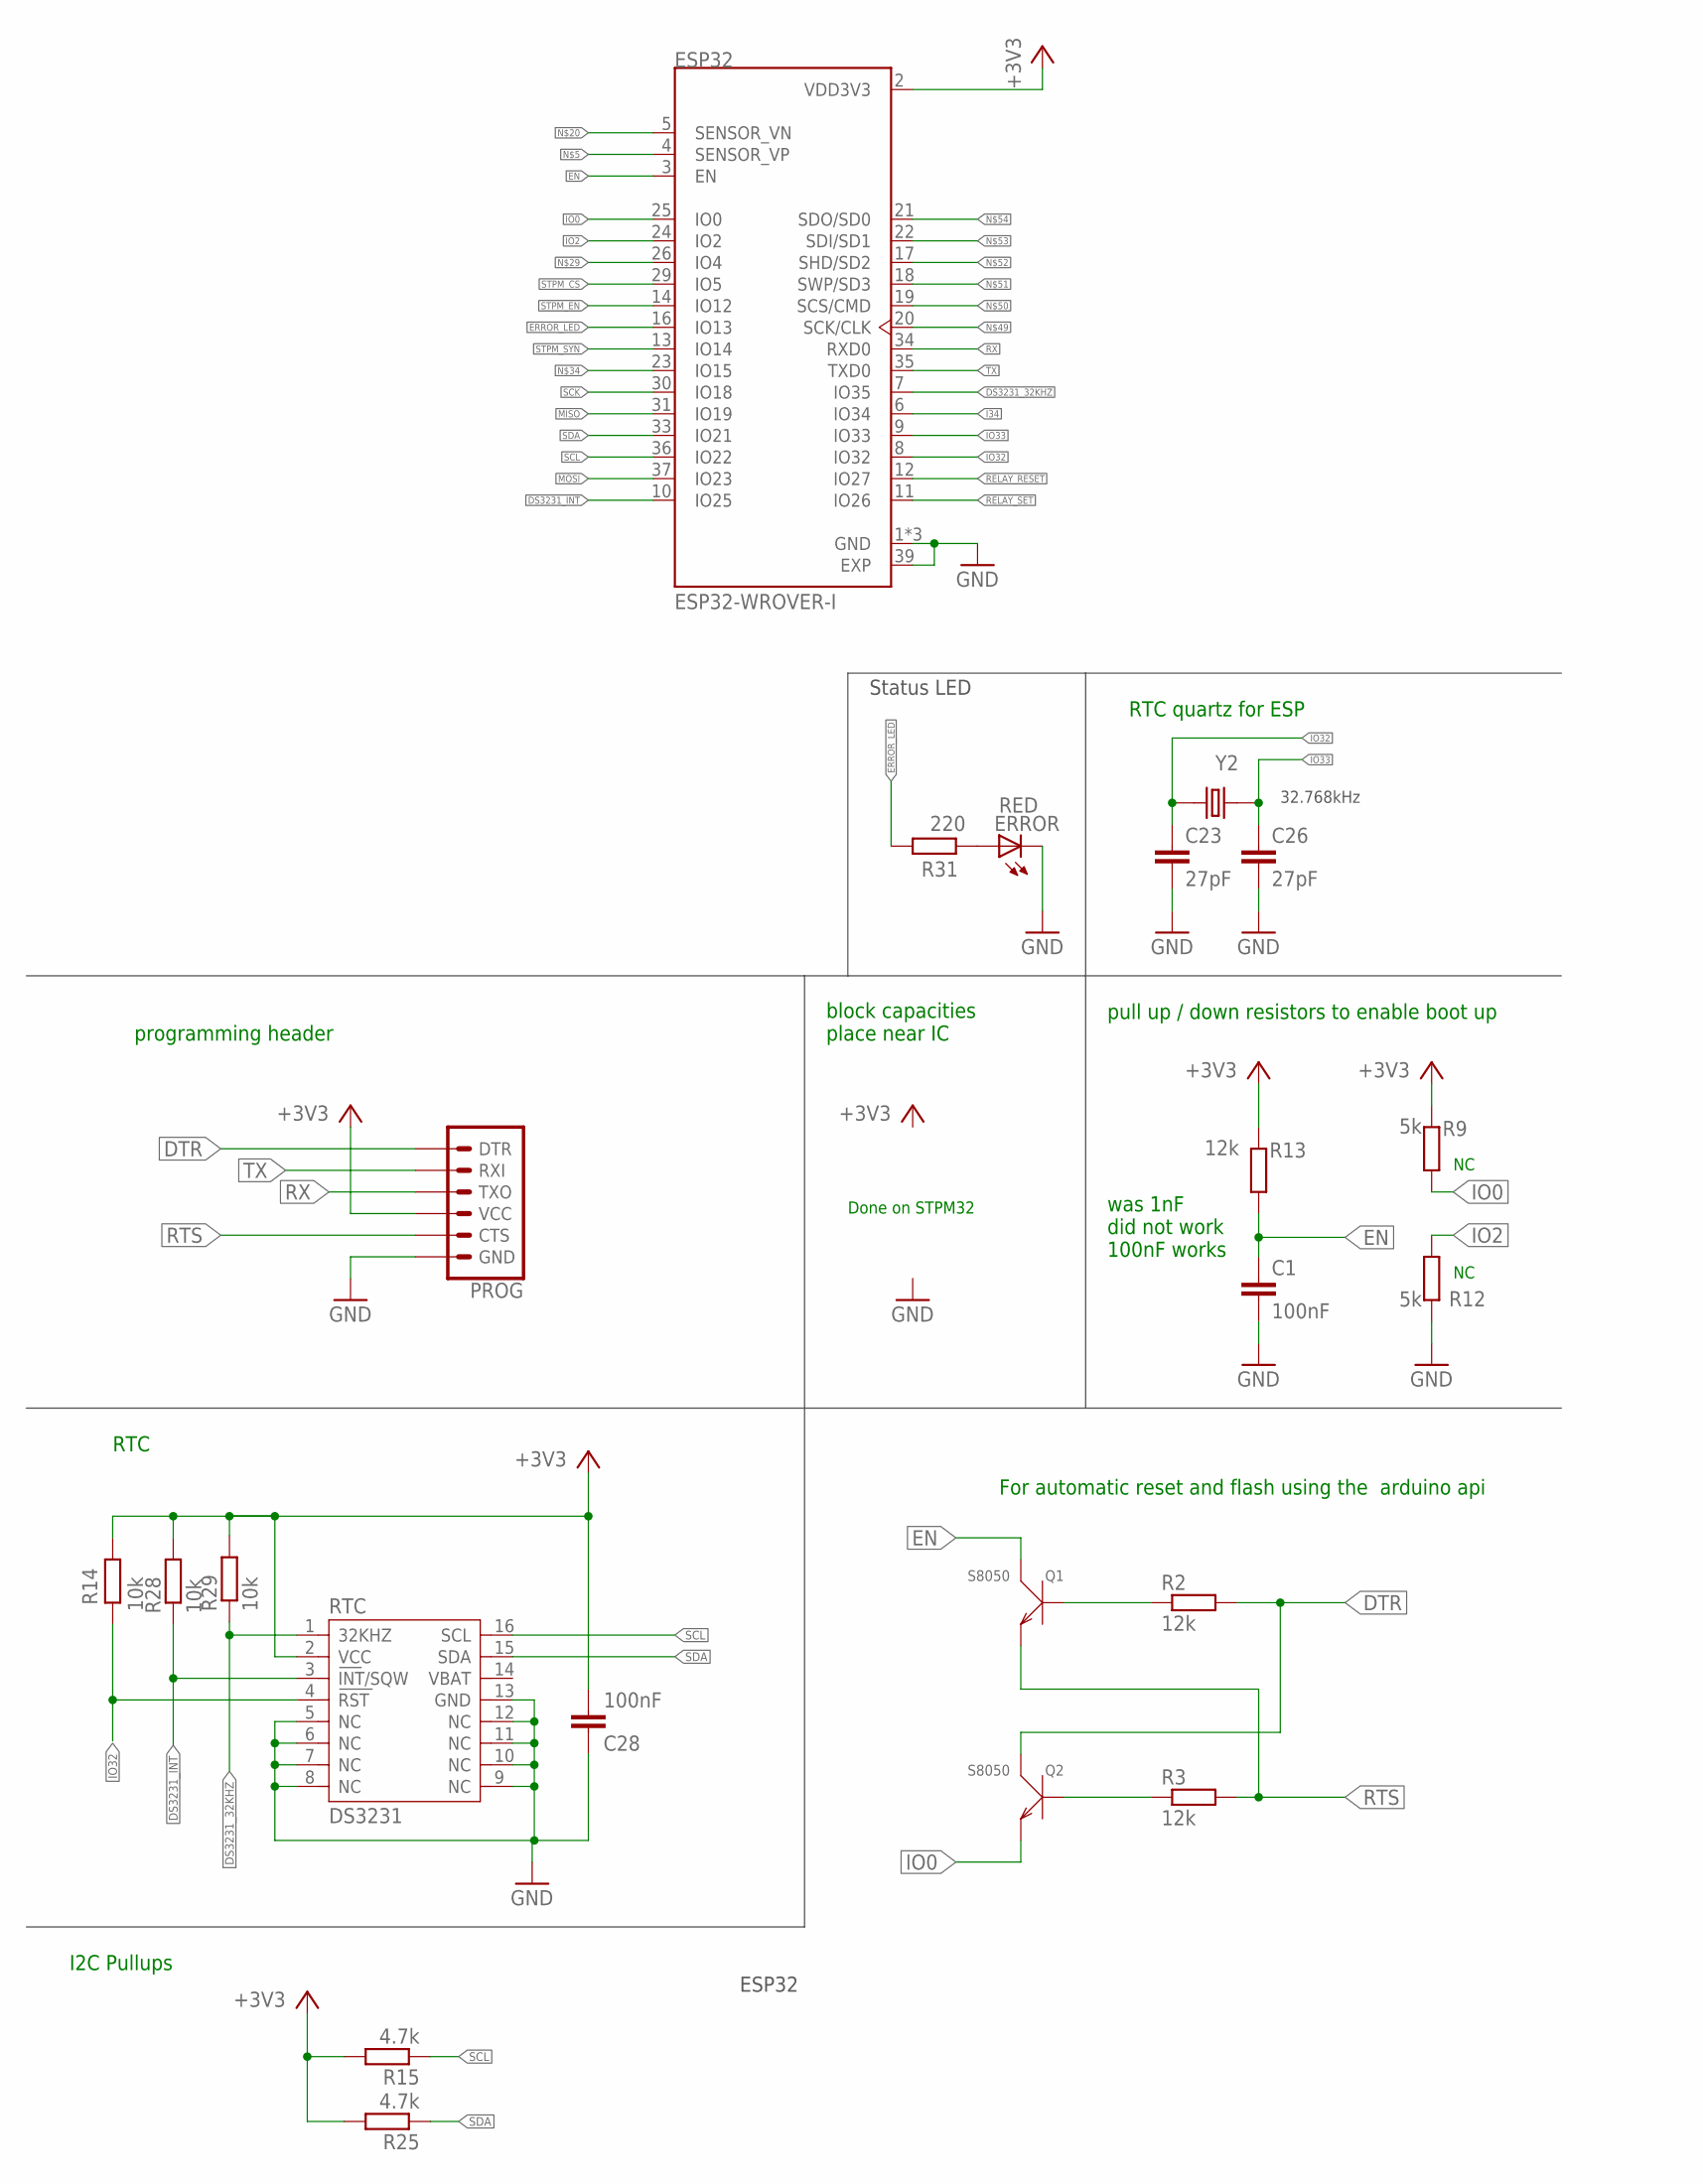
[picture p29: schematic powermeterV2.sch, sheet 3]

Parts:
C1, C28: 100nF; C0402
C23, C26: 27pF; C0402
ERROR: RED; CHIP-LED0805
ESP32: ESP32-WROVER-I; XCVR_ESP32-WROVER-I
PROG: 6_PIN_SERIAL_TARGET; 1X06
Q1, Q2: S8050; SOT-23
R2, R3, R13: 12k; R0402
R9, R12: 5k; R0402
R14, R28, R29: 10k; R0603
R15, R25: 4.7k; R0603
R31: 220; R0603
RTC: DS3231
Y2: NX2012SA-32.768K-STD-MUB-1; XTAL_NX2012SA-32.768K-STD-MUB-1

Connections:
+3V3: C28.2, ESP32.2 (VDD3V3), PROG.4 (VCC), R9.1, R13.1, R14.1, R15.2, R25.2, R28.2, R29.2, RTC.2 (VCC); also elsewhere on the board
DS3231_32KHZ: ESP32.7 (IO35), R29.1, RTC.1 (32KHZ)
DS3231_INT: ESP32.10 (IO25), R28.1, RTC.3 (INT/SQW)
DTR: PROG.1 (DTR), Q2.3 (C), R2.2
EN: C1.1, ESP32.3 (EN), Q1.3 (C), R13.2
ERROR_LED: ESP32.16 (IO13), R31.1
GND: C1.2, C23.2, C26.2, C28.1, ERROR.C, ESP32.1 (GND), ESP32.15 (GND), ESP32.38 (GND), ESP32.39 (EXP), PROG.6 (GND), R12.1, RTC.5 (NC), RTC.6 (NC), RTC.7 (NC), RTC.8 (NC), RTC.9 (NC), RTC.10 (NC), RTC.11 (NC), RTC.12 (NC), RTC.13 (GND); also elsewhere on the board
I34: ESP32.6 (IO34)
IO0: ESP32.25 (IO0), Q2.2 (E), R9.2
IO2: ESP32.24 (IO2), R12.2
IO32: C23.1, ESP32.8 (IO32), R14.2, RTC.4 (RST), Y2.1
IO33: C26.1, ESP32.9 (IO33), Y2.2
MISO: ESP32.31 (IO19); also elsewhere on the board
MOSI: ESP32.37 (IO23); also elsewhere on the board
unnamed: Q1.1 (B), R2.1
unnamed: Q2.1 (B), R3.1
unnamed: ERROR.A, R31.2
RELAY_RESET: ESP32.12 (IO27); also elsewhere on the board
RELAY_SET: ESP32.11 (IO26); also elsewhere on the board
RTS: PROG.5 (CTS), Q1.2 (E), R3.2
RX: ESP32.34 (RXD0), PROG.3 (TXO)
SCK: ESP32.30 (IO18); also elsewhere on the board
SCL: ESP32.36 (IO22), R15.1, RTC.16 (SCL)
SDA: ESP32.33 (IO21), R25.1, RTC.15 (SDA)
STPM_CS: ESP32.29 (IO5); also elsewhere on the board
STPM_EN: ESP32.14 (IO12); also elsewhere on the board
STPM_SYN: ESP32.13 (IO14); also elsewhere on the board
TX: ESP32.35 (TXD0), PROG.2 (RXI)

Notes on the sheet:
pull up / down resistors to enable boot up
For automatic reset and flash using the arduino api
ESP32
block capacities place near IC
Done on STPM32
32.768kHz
RTC quartz for ESP
RTC
programming header
I2C Pullups
Status LED
was 1nF did not work 100nF works

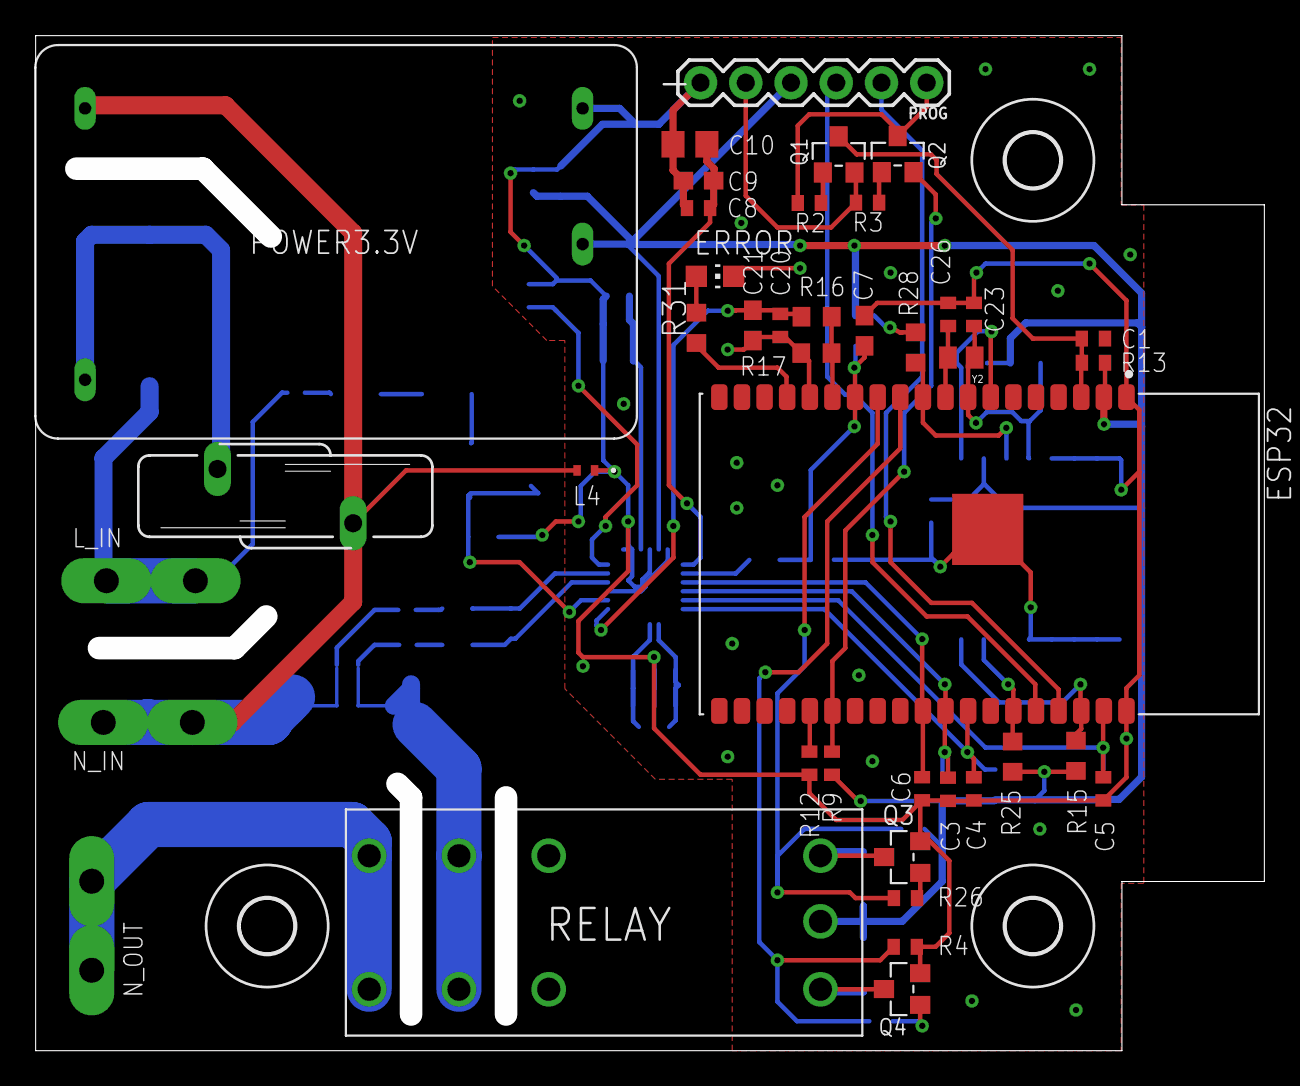
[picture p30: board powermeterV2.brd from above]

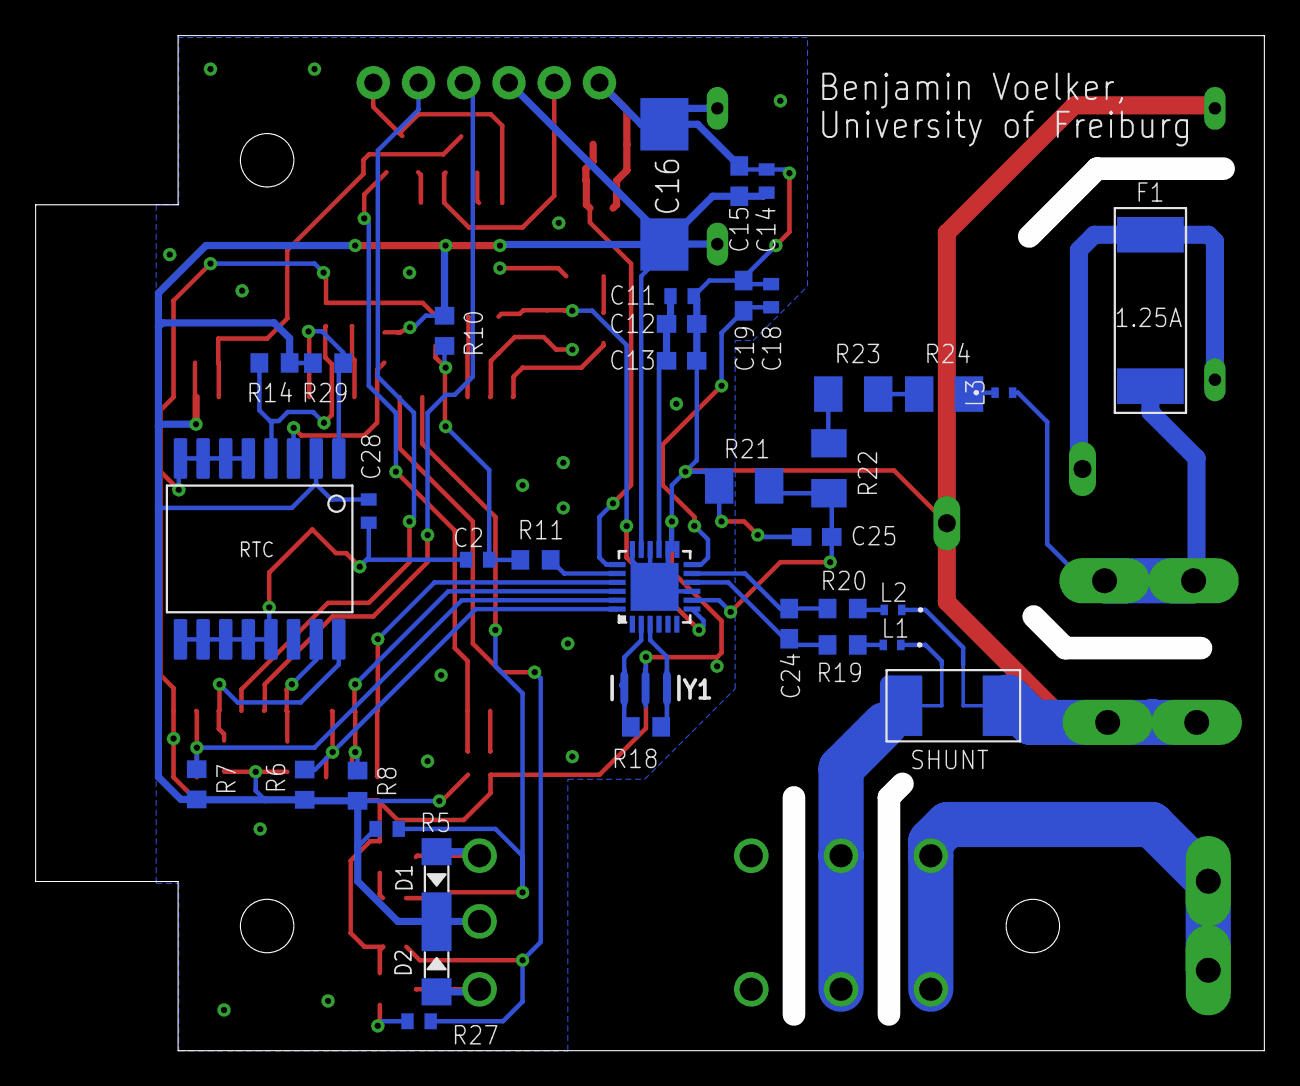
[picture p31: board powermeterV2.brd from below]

Board: 2 copper layers, 69.0 x 57.0 mm, 82 parts (38 on the bottom side), 53 nets.

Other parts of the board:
H2: MOUNT-HOLE3.0; 3,0

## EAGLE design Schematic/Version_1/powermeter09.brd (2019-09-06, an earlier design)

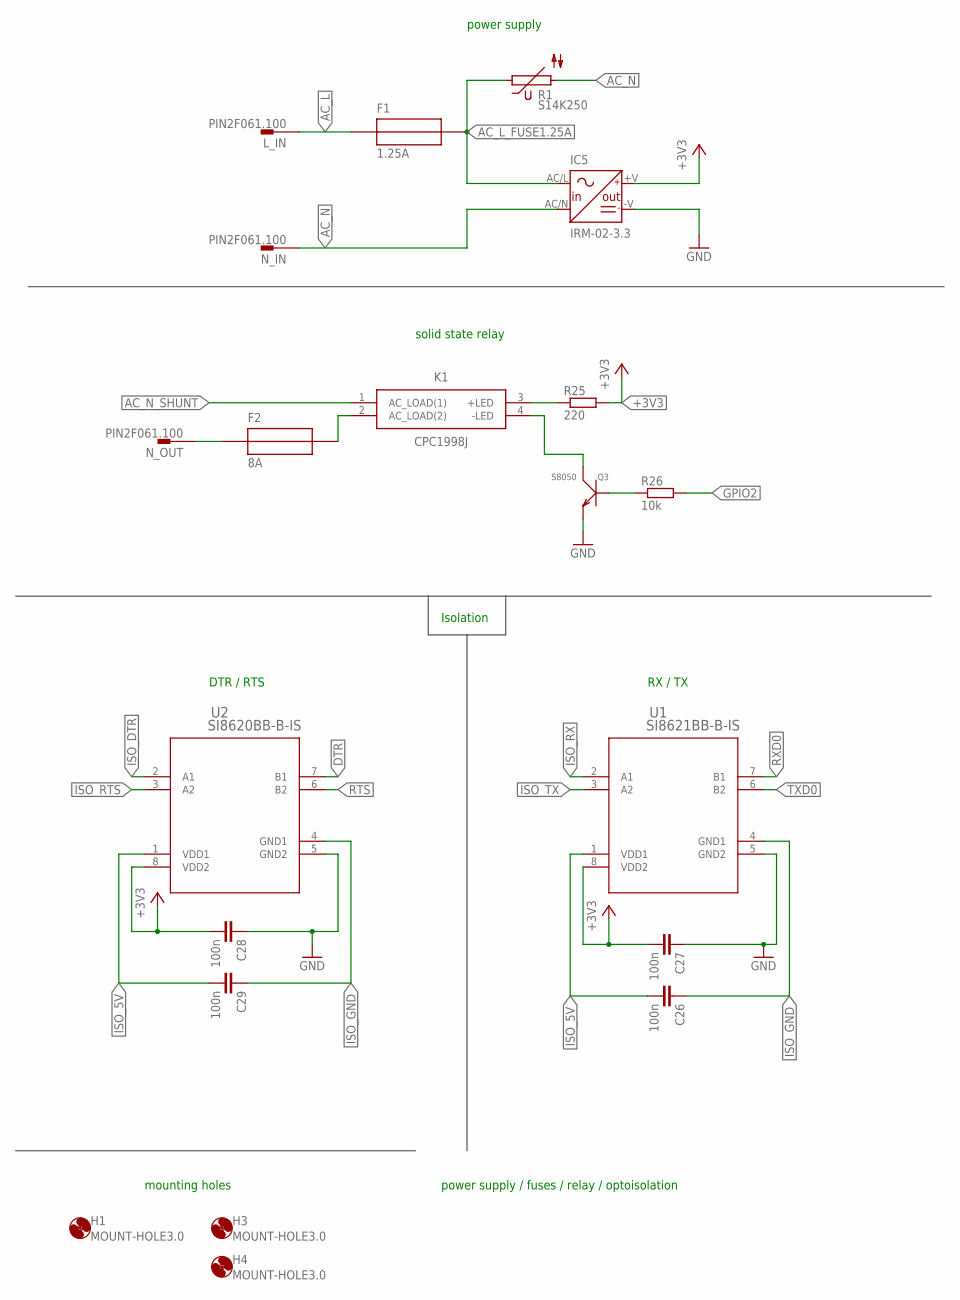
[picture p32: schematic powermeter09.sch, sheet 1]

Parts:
C26, C27, C28, C29: 100n; C0402
F1: 1.25A; SMD_FUSE
F2: 8A; SMD_FUSE
H1, H3, H4: MOUNT-HOLE3.0; 3,0
IC5: IRM-02-3.3; MW_IRM-02
K1: CPC1998J; TO381P516X1991X2388-4P
L_IN: PIN2F061.100; F061.100
N_IN: PIN2F061.100; F061.100
N_OUT: PIN2F061.100; F061.100
Q3: S8050; SOT-23
R1: S14K250
R25: 220; R0402
R26: 10k; R0402
U1: SI8621BB-B-IS; SOIC_8_PASCAL
U2: SI8620BB-B-IS; SOIC_8_PASCAL

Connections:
+3V3: C27.2, C28.2, IC5.+V (+V_OUT), R25.2, U1.8 (VDD2), U2.8 (VDD2); also elsewhere on the board
AC_L: F1.P$1 (1), L_IN.A1, L_IN.A2; also elsewhere on the board
AC_L_FUSE1.25A: F1.P$2 (2), IC5.AC/L (L), R1.1
AC_N: IC5.AC/N (N), N_IN.A1, N_IN.A2, R1.2; also elsewhere on the board
AC_N_SHUNT: K1.1 (AC_LOAD(1)); also elsewhere on the board
DTR: U2.7 (B1); also elsewhere on the board
GND: C27.1, C28.1, IC5.-V (-V_OUT), Q3.2 (E), U1.5 (GND2), U2.5 (GND2); also elsewhere on the board
GPIO2: R26.2; also elsewhere on the board
ISO_5V: C26.2, C29.2, U1.1 (VDD1), U2.1 (VDD1)
ISO_DTR: U2.2 (A1); also elsewhere on the board
ISO_GND: C26.1, C29.1, U1.4 (GND1), U2.4 (GND1); also elsewhere on the board
ISO_RTS: U2.3 (A2); also elsewhere on the board
ISO_RX: U1.2 (A1); also elsewhere on the board
ISO_TX: U1.3 (A2); also elsewhere on the board
unnamed: Q3.1 (B), R26.1
unnamed: F2.P$2 (2), K1.2 (AC_LOAD(2))
unnamed: K1.4 (-LED), Q3.3 (C)
unnamed: K1.3 (+LED), R25.1
unnamed: F2.P$1 (1), N_OUT.A1, N_OUT.A2
RTS: U2.6 (B2); also elsewhere on the board
RXD0: U1.7 (B1); also elsewhere on the board
TXD0: U1.6 (B2); also elsewhere on the board

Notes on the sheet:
power supply / fuses / relay / optoisolation
power supply
solid state relay
Isolation
RX / TX
DTR / RTS
mounting holes

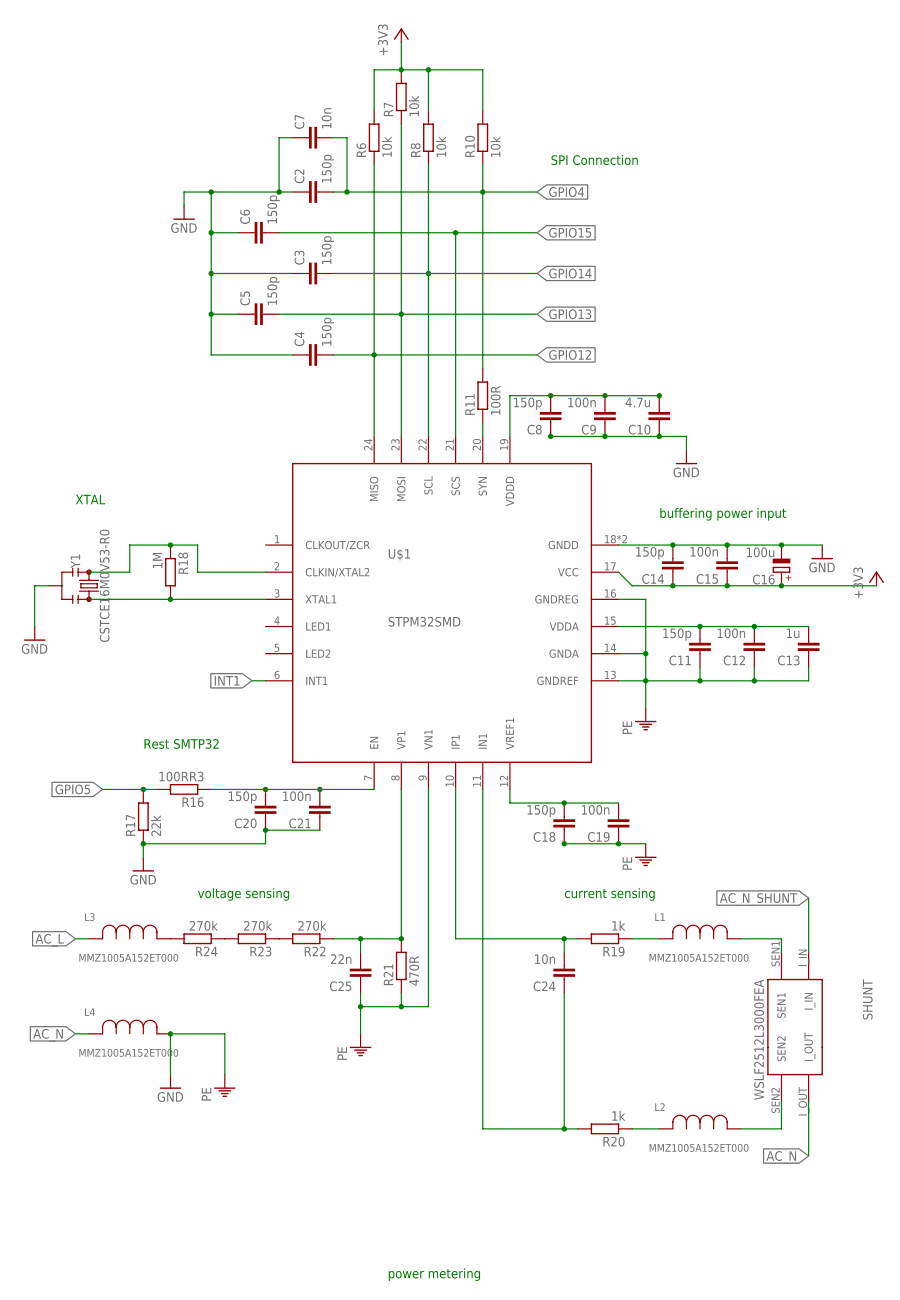
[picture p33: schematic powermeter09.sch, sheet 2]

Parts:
C2, C3, C4, C5, C6, C8, C11, C14, C18, C20: 150p; C0402
C7, C24: 10n; C0603
C9, C12, C15, C19, C21: 100n; C0603
C10: 4.7u; C0805
C13: 1u; C0603
C16: 100u; D/7343-31W
C25: 22n; C0603
L1, L2, L3, L4: MMZ1005A152ET000; IND_1005
R6, R7, R8, R10: 10k; R0603
R11: 100R; R0603
R16: 100RR3; R0603
R17: 22k; R0603
R18: 1M; R0603
R19, R20: 1k; R0603
R21: 470R; M1206
R22, R23, R24: 270k; M1206
SHUNT: WSLF2512L3000FEA; SMD_SHUNT
U$1: STPM32SMD; QFN24
Y1: CSTCE16M0V53-R0; RESONATOR-SMD-3.2X1.3

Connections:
+3V3: C14.1, C15.1, C16.+, R6.2, R7.2, R8.2, R10.2, U$1.17 (VCC); also elsewhere on the board
AC_L: L3.2; also elsewhere on the board
AC_N: L4.2, SHUNT.I_OUT; also elsewhere on the board
AC_N_SHUNT: SHUNT.I_IN; also elsewhere on the board
DC_GND1: C18.2, C19.2, U$1.12 (VREF1)
DC_GND2: C20.2, C21.2, R16.1, U$1.7 (EN)
GND: C2.1, C3.1, C4.1, C5.1, C6.1, C7.1, C8.1, C9.1, C10.1, C11.1, C12.1, C13.1, C14.2, C15.2, C16.-, C18.1, C19.1, C20.1, C21.1, C25.1, L4.1, R17.1, R21.1, U$1.9 (VN1), U$1.13 (GNDREF), U$1.14 (GNDA), U$1.16 (GNDREG), U$1.18 (GNDD), U$1.EXP (GNDD), Y1.2; also elsewhere on the board
GPIO4: C2.2, C7.2, R10.1, R11.2; also elsewhere on the board
GPIO5: R16.2, R17.2; also elsewhere on the board
GPIO12: C4.2, R6.1, U$1.24 (MISO); also elsewhere on the board
GPIO13: C5.2, R7.1, U$1.23 (MOSI); also elsewhere on the board
GPIO14: C3.2, R8.1, U$1.22 (SCL); also elsewhere on the board
GPIO15: C6.2, U$1.21 (SCS); also elsewhere on the board
INT1: U$1.6 (INT1); also elsewhere on the board
unnamed: C8.2, C9.2, C10.2, U$1.19 (VDDD)
unnamed: C11.2, C12.2, C13.2, U$1.15 (VDDA)
unnamed: R18.2, U$1.3 (XTAL1), Y1.3
unnamed: R18.1, U$1.2 (CLKIN/XTAL2), Y1.1
unnamed: C24.1, R20.2, U$1.11 (IN1)
unnamed: R11.1, U$1.20 (SYN)
unnamed: C24.2, R19.2, U$1.10 (IP1)
unnamed: C25.2, R21.2, R22.1, U$1.8 (VP1)
unnamed: R23.2, R24.1
unnamed: R22.2, R23.1
unnamed: L3.1, R24.2
unnamed: L1.2, R19.1
unnamed: L2.2, R20.1
unnamed: L1.1, SHUNT.SEN1
unnamed: L2.1, SHUNT.SEN2

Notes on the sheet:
power metering
SPI Connection
buffering power input
Rest SMTP32
XTAL
current sensing
voltage sensing

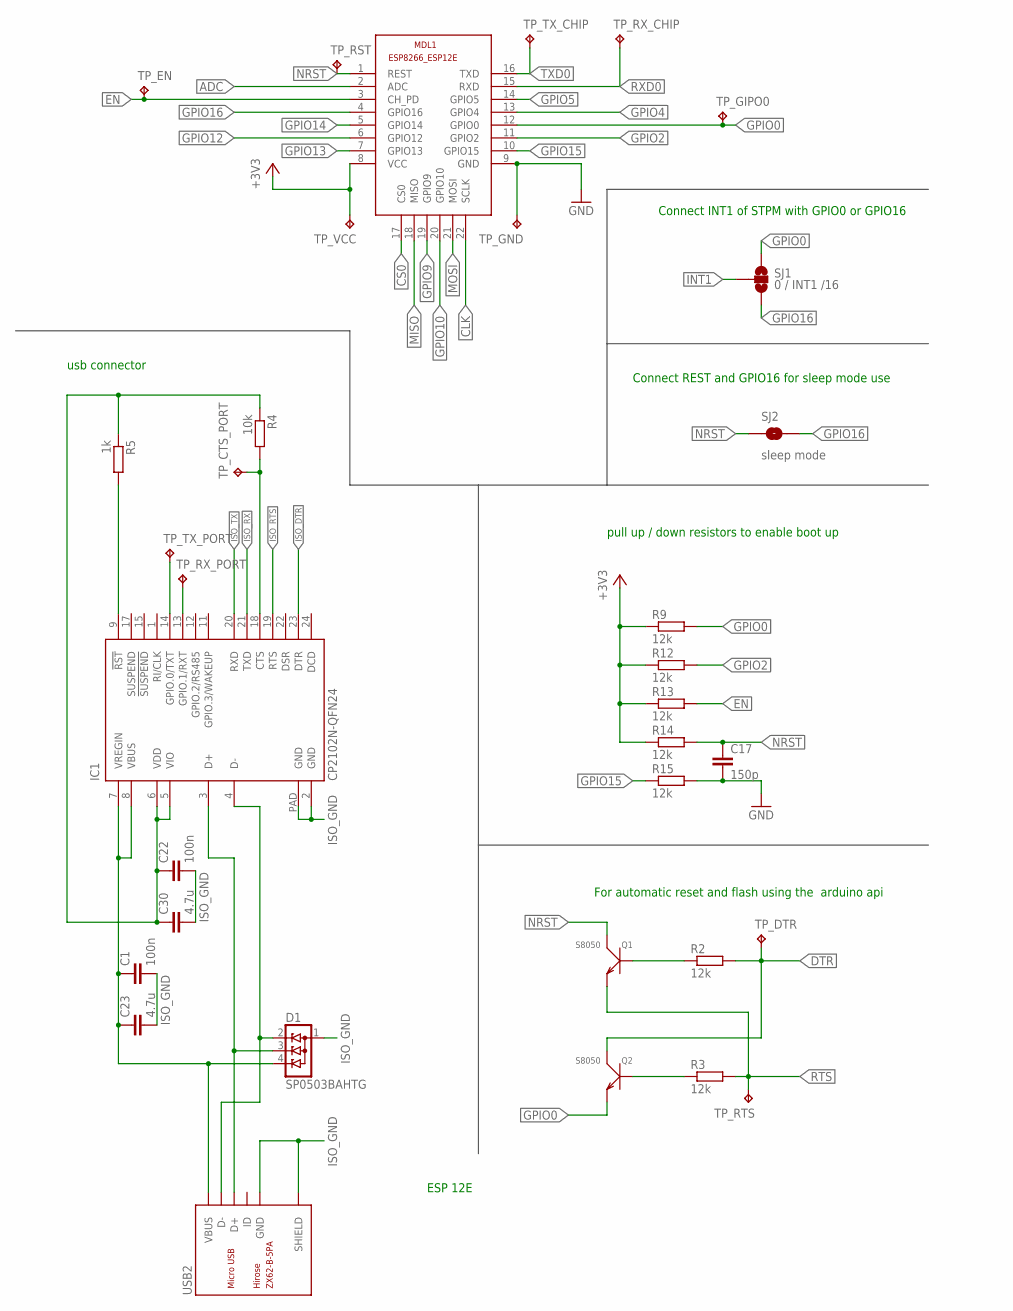
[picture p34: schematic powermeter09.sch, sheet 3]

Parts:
C1, C22: 100n; C0402
C17: 150p; C0402
C23, C30: 4.7u; C0402
D1: SP0503BAHTG; SOT143-4-R
IC1: CP2102N-QFN24; QFN24
MDL1: ESP8266-12EESP8266-ESP12E; ESP8266-ESP12E
Q1, Q2: S8050; SOT-23
R2, R3, R9, R12, R13, R14, R15: 12k; R0402
R4: 10k; R0603
R5: 1k; R0603
SJ1: 0 / INT1 /16; SJ_3
SJ2: sleep mode; SJ_2S
TP_CTS_PORT: TPB1,27; B1,27
TP_DTR: TPB1,27; B1,27
TP_EN: TPB1,27; B1,27
TP_GIPO0: TPB1,27; B1,27
TP_GND: TPB1,27; B1,27
TP_RST: TPB1,27; B1,27
TP_RTS: TPB1,27; B1,27
TP_RX_CHIP: TPB1,27; B1,27
TP_RX_PORT: TPB1,27; B1,27
TP_TX_CHIP: TPB1,27; B1,27
TP_TX_PORT: TPB1,27; B1,27
TP_VCC: TPB1,27; B1,27
USB2: ZX62-B-5PA; MICRO-USB5+6P-SMD-0.65-AB

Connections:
+3V3: MDL1.8 (VCC), R9.1, R12.1, R13.1, R14.1, TP_VCC.TP; also elsewhere on the board
ADC: MDL1.2 (ADC)
CLK: MDL1.22 (SCLK)
CP2102_3.3V1: C22.1, C30.1, IC1.5 (VIO), IC1.6 (VDD), R4.1, R5.1
CS0: MDL1.17 (CS0)
DTR: Q2.3 (C), R2.2, TP_DTR.TP; also elsewhere on the board
EN: MDL1.3 (CH_PD), R13.2, TP_EN.TP
GND: C17.2, MDL1.9 (GND), R15.2, TP_GND.TP; also elsewhere on the board
GPIO0: MDL1.12 (GPIO0), Q2.2 (E), R9.2, SJ1.1, TP_GIPO0.TP
GPIO2: MDL1.11 (GPIO2), R12.2; also elsewhere on the board
GPIO4: MDL1.13 (GPIO4); also elsewhere on the board
GPIO5: MDL1.14 (GPIO5); also elsewhere on the board
GPIO9: MDL1.19 (GPIO9)
GPIO10: MDL1.20 (GPIO10)
GPIO12: MDL1.6 (GPIO12); also elsewhere on the board
GPIO13: MDL1.7 (GPIO13); also elsewhere on the board
GPIO14: MDL1.5 (GPIO14); also elsewhere on the board
GPIO15: MDL1.10 (GPIO15), R15.1; also elsewhere on the board
GPIO16: MDL1.4 (GPIO16), SJ1.3, SJ2.2
INT1: SJ1.2; also elsewhere on the board
ISO_DTR: IC1.23 (DTR); also elsewhere on the board
ISO_GND: C1.2, C22.2, C23.2, C30.2, D1.1, IC1.2 (GND), IC1.PAD (GND), USB2.5 (GND), USB2.P1 (SHIELD), USB2.P2 (SHIELD), USB2.P3 (SHIELD), USB2.P4 (SHIELD), USB2.P5 (SHIELD), USB2.P6 (SHIELD); also elsewhere on the board
ISO_RTS: IC1.19 (RTS); also elsewhere on the board
ISO_RX: IC1.21 (TXD); also elsewhere on the board
ISO_TX: IC1.20 (RXD); also elsewhere on the board
MISO: MDL1.18 (MISO)
MOSI: MDL1.21 (MOSI)
unnamed: Q1.1 (B), R2.1
unnamed: Q2.1 (B), R3.1
unnamed: IC1.18 (CTS), R4.2, TP_CTS_PORT.TP
unnamed: IC1.9 (!RST), R5.2
unnamed: IC1.14 (GPIO.0/TXT), TP_TX_PORT.TP
unnamed: IC1.13 (GPIO.1/RXT), TP_RX_PORT.TP
NRST: C17.1, MDL1.1 (REST), Q1.3 (C), R14.2, SJ2.1, TP_RST.TP
RTS: Q1.2 (E), R3.2, TP_RTS.TP; also elsewhere on the board
RXD0: MDL1.15 (RXD), TP_RX_CHIP.TP; also elsewhere on the board
TXD0: MDL1.16 (TXD), TP_TX_CHIP.TP; also elsewhere on the board
USB_D+1: D1.3, IC1.3 (D+), USB2.3 (D+)
USB_D-1: D1.2, IC1.4 (D-), USB2.2 (D-)
VBUS: C1.1, C23.1, D1.4, IC1.7 (VREGIN), IC1.8 (VBUS), USB2.1 (VBUS)

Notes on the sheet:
ESP 12E
pull up / down resistors to enable boot up
For automatic reset and flash using the arduino api
Connect REST and GPIO16 for sleep mode use
Connect INT1 of STPM with GPIO0 or GPIO16
usb connector

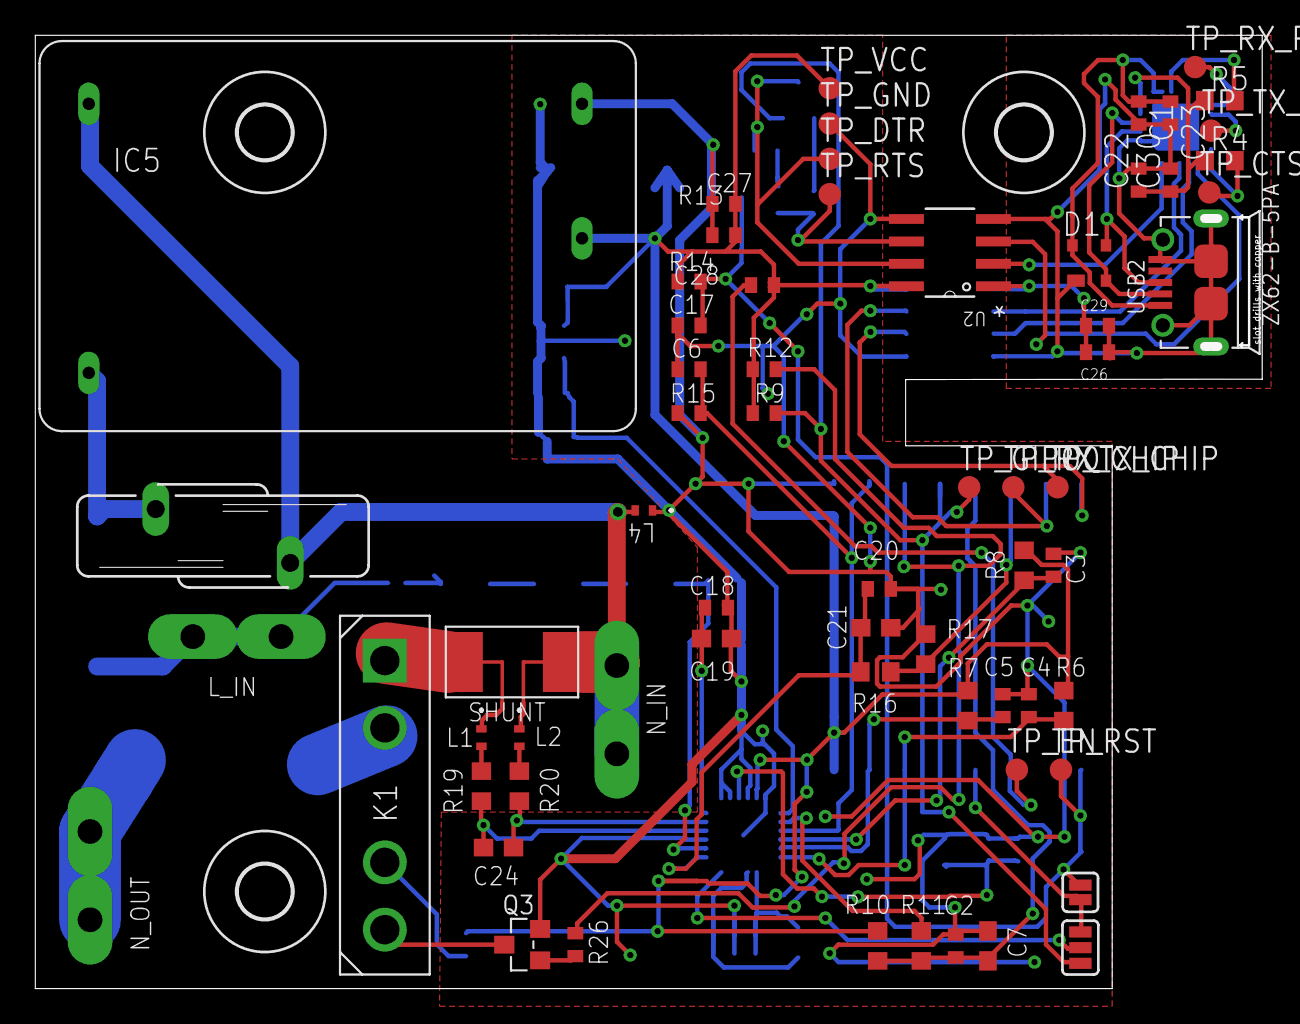
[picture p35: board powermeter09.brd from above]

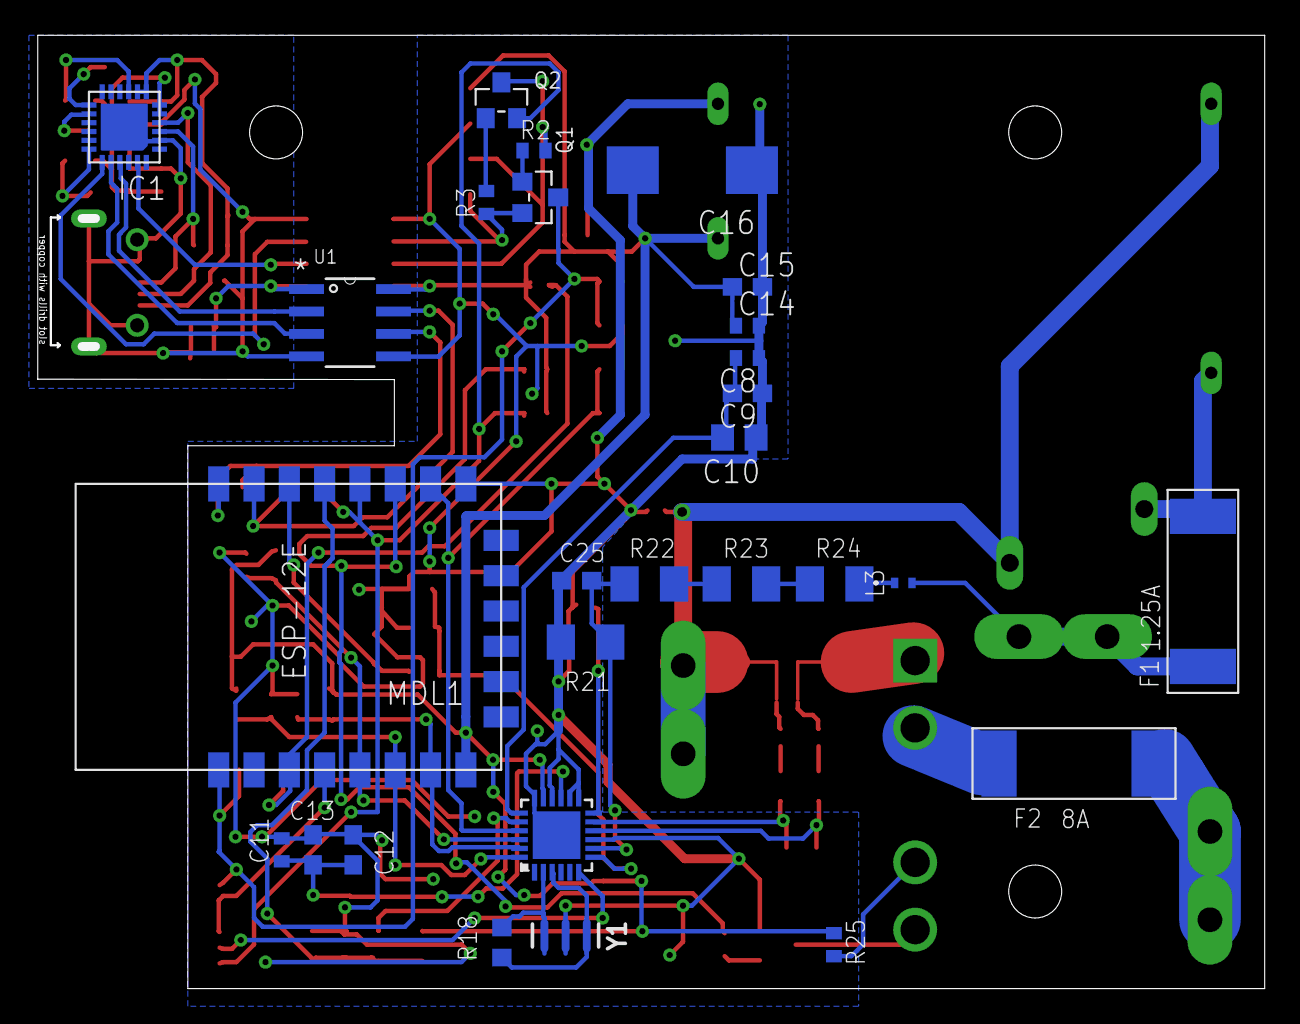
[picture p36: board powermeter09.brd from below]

Board: 2 copper layers, 69.5 x 54.0 mm, 96 parts (28 on the bottom side), 60 nets.

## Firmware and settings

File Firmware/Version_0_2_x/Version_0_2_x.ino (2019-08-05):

extern "C" {
  #include "user_interface.h"
}
#include <SPI.h>
#include "STPM.h"
#include <ESP8266WiFi.h>
// #include <esp_wifi.h>
#include <WiFiClient.h>
#include <WiFiUdp.h>
#include <time.h>
#include <ESP8266mDNS.h>
#include <EEPROM.h>
#include <ArduinoJson.h>
#include <TimeLib.h>
#include <DNSServer.h>
#include "FS.h"

const byte DNS_PORT = 53;
DNSServer dnsServer;

// Serial Speed and DEBUG option
#define SERIAL_SPEED 2000000
#define DEBUG

#define VERSION "0.2_x"

#define MAX_MDNS_LEN 16
#define MDNS_START_ADDRESS 0
// Pins for STPM34 SPI Connection
const int STPM_CS = 15;
const int STPM_SYN = 4;
// Reset pin of STPM
const int STPM_RES = 5;

// Pins for 230V Relay
const int RELAY_PIN = 2;

// STPM Object
STPM stpm34(STPM_RES, STPM_CS, STPM_SYN);

// counter holds # isr calls
volatile uint16_t counter = 0;
// Last micros() count of isr call
volatile long nowTs = 0;
volatile long lastTs = 0;

// Buffering stuff
// Number of bytes for one measurement
int MEASURMENT_BYTES = 8; //(16+2)
// Chunk sizes of data to send
#define BUF_SIZE (4096*10)
uint32_t chunkSize = 256;
// Circular chunked buffer
static uint8_t buffer[BUF_SIZE] = {0};
// Buffer read/write position
uint16_t readPtr = 0;
volatile uint16_t writePtr = 0;

// WLAN configuration
const char* ssid =  "esewifi";
const char* password =  "silkykayak943";

// Open two TCP ports, one for commands and sampling and one for a raw data stream
WiFiServer server(54321);
WiFiServer streamServer(54322);

// TIMER stuff
#define CLOCK 160 // clock frequency in MHz.
#define DEFAUL_SR 4000
unsigned int samplingRate = DEFAUL_SR; // Standard read frequency is 4kHz
// Calculate the number of cycles we have to wait
volatile uint32_t TIMER_CYCLES_FAST = (CLOCK * 1000000) / samplingRate; // Cycles between HW timer inerrupts
volatile uint32_t timer_next;
volatile uint32_t timer_now;

// Sample state machine
#define CMD_SAMPLE "sample"
#define CMD_SWITCH "switch"
#define CMD_STOP "stop"
#define CMD_RESTART "restart"
#define CMD_INFO "info"
#define CMD_MDNS "mdns"
#define CMD_NTP "ntp"

#define STATE_IDLE -1
#define STATE_SAMPLE_USB 0
#define STATE_SAMPLE_TCP 1
#define STATE_STREAM_TCP 2
int state = STATE_IDLE;
int next_state = STATE_IDLE;


#define STATE_VI 0
#define STATE_PQ 1
#define STATE_VIPQ 2
volatile int measures = STATE_VI;

// Stuff for frequency calculation
volatile long freqCalcStart;
volatile long freqCalcNow;
volatile long freq = 0;


WiFiClient client;
WiFiClient streamClient;

#define COMMAND_MAX_SIZE 128
char command[COMMAND_MAX_SIZE] = {'\0'};
StaticJsonDocument<COMMAND_MAX_SIZE> doc;
String response = "";

char mdnsName[MAX_MDNS_LEN] = {'\0'};


#define LOCATION_OFFSET (2*60*60)
IPAddress timeServerIP; // time.nist.gov NTP server address
// Use local tcp server with hopefully a small ping
const char* ntpServerName = "0.de.pool.ntp.org";
unsigned int localNTPPort = 2390; // local port to listen for UDP packets
const int NTP_PACKET_SIZE = 48; // NTP time stamp is in the first 48 bytes
byte ntpBuffer[NTP_PACKET_SIZE]; //buffer to hold incoming and outgoing
// A UDP instance to let us send and receive packets over UDP
WiFiUDP udp;
unsigned long ntpValidMillis = 0;
unsigned long ntpEpochSeconds = 0;
unsigned long ntpMilliseconds = 0;

unsigned long currentSeconds = 0;
unsigned long currentMilliseconds = 0;

unsigned long samplingCountdown = 0;
unsigned long startSamplingMillis = 0;
unsigned long samplingDuration = 0;
unsigned long sentSamples = 0;
volatile unsigned long totalSamples = 0;


typedef void (*GetterTypeFunc)(uint8_t channel, float *voltage, float *current, float* active, float* reactive);
GetterTypeFunc getterFunc = NULL;

void setup() {
  // Set Relay pins as output which should be switched on by default
  pinMode(RELAY_PIN, OUTPUT);
  digitalWrite(RELAY_PIN, HIGH);

   // Setup serial communication
  Serial.begin(SERIAL_SPEED);

  // Setup STPM 32
  stpm34.init();
  timer0_isr_init();

  // Load the MDNS name from eeprom
  EEPROM.begin(2*MAX_MDNS_LEN);

#ifdef DEBUG
  Serial.printf("Info:Connecting WLAN to %s \r\n", ssid);
#endif
  WiFi.mode(WIFI_STA);
  // esp_wifi_set_ps(WIFI_PS_NONE);
  wifi_set_sleep_type(NONE_SLEEP_T);
  char * name = getMDNS();
  WiFi.hostname(name);
  WiFi.begin(ssid, password);
  long start = millis();
  bool connected = true;
  while (WiFi.status() != WL_CONNECTED) {
    yield();
    // After trying to connect for 5s continue without wifi
    if (millis() - start > 8000) {
      connected = false;
      WiFi.forceSleepBegin();
      Serial.println(F("Info:Connection Failed! Continuing without wifi..."));
      break;
    }
  }
#ifdef DEBUG
  if (connected) {
    Serial.println(F("Info:Connected to WLAN"));
    Serial.print(F("Info:Connected to ")); Serial.println(ssid);
    Serial.print(F("Info:IP Address: ")); Serial.println(WiFi.localIP());
  }
#endif

  initMDNS();
  // Start the TCP server
  server.begin();
  streamServer.begin();

  client.setDefaultNoDelay(false);

  udp.begin(localNTPPort);

  getTimeNTP();
  // modify TTL associated  with the domain name (in seconds)
  // default is 60 seconds
  dnsServer.setTTL(300);
  // set which return code will be used for all other domains (e.g. sending
  // ServerFailure instead of NonExistentDomain will reduce number of queries
  // sent by clients)
  // default is DNSReplyCode::NonExistentDomain
  dnsServer.setErrorReplyCode(DNSReplyCode::ServerFailure);

  // start DNS server for a specific domain name
  String dns = String(name);
  dns += ".local";
  dnsServer.start(DNS_PORT, dns, WiFi.localIP());

  response.reserve(128);
  WiFi.setOutputPower(20.5);

  Serial.println(F("Info:Setup done"));
}


uint16_t getReadWriteDistance() {
  if (writePtr < readPtr) return writePtr + (BUF_SIZE - readPtr);
  else return writePtr - readPtr;
}

long mdnsUpdate = millis();
// the loop routine runs over and over again forever:
void loop() {
  dnsServer.processNextRequest();
  // If we only have 100 ms before sampling should start, wait actively
  if (samplingCountdown != 0 and (samplingCountdown - millis()) < 2000) {
    WiFi.setOutputPower(20.5);
    // Ramp up TCP Speed
    if (next_state == STATE_SAMPLE_TCP) {
      response = "Info:KeepAlive";
      // client.setNoDelay(true);
      while (((long)(samplingCountdown) - millis()) > 100) {
        Serial.println(response);
        client.println(response);
        delay(2);
        yield();
      }
      // client.setNoDelay(false);
    }
    int32_t mydelta = samplingCountdown - millis();
    if (mydelta > 0) delay(mydelta-1);
    #ifdef DEBUG
    state = next_state;
    updateTime(false);
    char * cur = printCurrentTime();
    Serial.print(F("Info:StartSampling @ "));
    Serial.println(cur);
    #endif
    startSampling();
    samplingCountdown = 0;
  }
  if (state == STATE_IDLE and millis() - mdnsUpdate >= 1000) {
    // MDNS.update();
    mdnsUpdate = millis();
    #ifdef DEBUG
    char * cur = printCurrentTime();
    Serial.print(F("Info:"));
    Serial.println(cur);
    #endif
  }
  MDNS.update();
  // Output frequency
  if (freq != 0) {
    long fr = freq;
    freq = 0;
    float frequency = (float)samplingRate/(float)((fr)/1000000.0);
    response = F("Info:");
    response += frequency;
    response += F("Hz");
    char * cur = printCurrentTime();
    response += F("\r\nInfo:");
    response += cur;
    #ifdef DEBUG
    Serial.println(response);
    #endif
    if (client.connected()) {
      client.println(response);
    }
  }

  // Handle serial events
  if (Serial.available()) {
    handleEvent(Serial);
  }


  // Handle client connections
  if (!client.connected()) {
    // Look for people connecting over the server
    client = server.available();
    // We want that because we don't want each buffer part to be send immidiately
    // client.setNoDelay(false);
    // Each buffer should be written directly
    client.setNoDelay(false);
  } else {
    // Handle client events
    if (client.available() > 0) {
      handleEvent(client);
    }
  }

  if (state == STATE_IDLE) {
    // Look for people connecting over the server
    streamClient = streamServer.available();
    if (streamClient.connected()) {
      state = STATE_STREAM_TCP;
      samplingRate = DEFAUL_SR;
      startSampling();
    }
  } else if (state == STATE_SAMPLE_USB) {
    writeChunks(Serial, false);
  } else if (state == STATE_SAMPLE_TCP) {
    if (!client.connected()) {
      #ifdef DEBUG
      Serial.println(F("Info:TCP not connected"));
      #endif
      state = STATE_IDLE;
      stopSampling();
    } else {
      writeChunks(client, false);
    }
  } else if (state == STATE_STREAM_TCP) {
    if (!streamClient.connected()) {
      #ifdef DEBUG
      Serial.println(F("Info:TCP Stream not connected"));
      #endif
      state = STATE_IDLE;
      stopSampling();
    } else {
      writeChunks(streamClient, false, false);
    }
  }
  yield();
}

void writeChunks(Stream &getter, bool tail) {
  while(getReadWriteDistance() > chunkSize) writeChunk(getter, chunkSize);
  if (tail) writeChunk(getter, getReadWriteDistance());
}

void writeChunks(Stream &getter, bool tail, bool prefix) {
  while(getReadWriteDistance() > chunkSize) writeChunk(getter, chunkSize, prefix);
  if (tail) writeChunk(getter, getReadWriteDistance(), prefix);
}

void writeChunk(Stream &getter, uint16_t size) {
  writeChunk(getter, size, true);
}

uint8_t size_prefix[sizeof(uint16_t)];
void writeChunk(Stream &getter, uint16_t size, bool prefix) {
  if (size <= 0) return;
  uint16_t end = (readPtr+size)%BUF_SIZE;
  if (prefix) {
    getter.print(F("Data:"));
    memcpy(&size_prefix[0], (void*)&size, sizeof(uint16_t));
    getter.write(size_prefix, sizeof(uint16_t));
  }
  if (end > readPtr) {
    getter.write((uint8_t*)&buffer[readPtr], size);
  } else {
    getter.write((uint8_t*)&buffer[readPtr], BUF_SIZE - readPtr);
    getter.write((uint8_t*)&buffer[0], end);
  }
  sentSamples += size/MEASURMENT_BYTES;
  readPtr = end;
  getter.flush();
}

float values[4] = {0};

/****************************************************
 * ISR for sampling
 ****************************************************/
void ICACHE_RAM_ATTR sample_ISR(){
  cli();//stop interrupts
  // Vaiables for frequency count
  counter++;
  totalSamples++;
  if (counter >= samplingRate) {
    freqCalcNow = micros();
    freq = freqCalcNow-freqCalcStart;
    freqCalcStart = freqCalcNow;
    counter = 0;
  }
  if (measures == STATE_VI) {
    stpm34.readVoltageAndCurrent(1, (float*) &values[0], (float*) &values[1]);
  } else if (measures == STATE_PQ) {
    stpm34.readPower(1, (float*) &values[0], (float*) &values[2], (float*) &values[1], (float*) &values[2]);
  } else if (measures == STATE_VIPQ) {
    stpm34.readAll(1, (float*) &values[0], (float*) &values[1], (float*) &values[2], (float*) &values[3]);
  }
  memcpy(&buffer[writePtr], (void*)&values[0], MEASURMENT_BYTES);
  if (writePtr<readPtr and ((writePtr+MEASURMENT_BYTES) % BUF_SIZE) >= readPtr) {
    Serial.println(F("Info:BufferOvf"));
  }
  writePtr = (writePtr+MEASURMENT_BYTES) % BUF_SIZE;


  // Calculate next time to execute and compare to current time
  timer_next = timer_next + TIMER_CYCLES_FAST;
  timer_now = ESP.getCycleCount();
  // Check If next is not in the past and handle overflow
  // Cant we make this better with absolut values?
  if (timer_next > timer_now || (timer_now <= 4294967296 && timer_next <= TIMER_CYCLES_FAST)) {
    timer0_write(timer_next);
  // If the ISR took to long, we indicate the error and start the ISR again immidiately
  } else {
    Serial.println(F("Info:Timer error"));
    timer0_write(ESP.getCycleCount() + 1000);
  }
  sei();
}


/****************************************************
 * A serial event occured
 ****************************************************/
void handleEvent(Stream &getter) {
  if (!getter.available()) return;
  getter.readStringUntil('\n').toCharArray(command,COMMAND_MAX_SIZE);
  // Be backwards compatible to "?" command all the time
  if (command[0] == '?') {
    getter.println(F("Info:Setup done"));
    return;
  }
  #ifdef DEBUG
  Serial.print(F("Info:")); Serial.println(command);
  #endif

  // Deserialize the JSON document
  DeserializationError error = deserializeJson(doc, command);
  // Test if parsing succeeds.
  if (error) {
    getter.print(F("Info:deserializeJson() failed: "));
    getter.println(error.c_str());
    #ifdef DEBUG
    if (&getter != &Serial) {
      Serial.print(F("Info:deserializeJson() failed: "));
      Serial.println(error.c_str());
    }
    #endif
    return;
  }
  response = F("Info:");
  handleJSON();

  getter.println(response);
  #ifdef DEBUG
  if (&getter != &Serial) Serial.println(response);
  #endif
}

void handleJSON() {
  // All commands look like the following:
  // {"cmd":{"name":"commandName", "payload":{<possible data>}}}
  // e.g. mdns

  const char* cmd = doc[F("cmd")]["name"];
  JsonObject root = doc.as<JsonObject>();
  if (cmd == nullptr) {
    response += F("JSON does not match format, syntax: {\"cmd\":{\"name\":<commandName>, \"[payload\":{<possible data>}]}}");
    return;
  }

  /*********************** SAMPLING COMMAND ****************************/
  // e.g. {"cmd":{"name":"sample", "payload":{"type":"Serial", "rate":4000}}}
  if(strcmp(cmd, CMD_SAMPLE) == 0) {
    // For sampling we need type payload and rate payload
    const char* typeC = root["cmd"]["payload"]["type"];
    const char* measuresC = root["cmd"]["payload"]["measures"];
    int rate = doc["cmd"]["payload"]["rate"].as<int>();
    unsigned long ts = doc["cmd"]["payload"]["time"].as<unsigned long>();

    if (typeC == nullptr or rate == 0) {
      response += F("Not a valid \"sample\" command");
      if (typeC == nullptr) response += F(", \"type\" missing");
      if (rate == 0) response += F(", \"rate\" missing");
      return;
    }
    if (rate > 8000 || rate <= 0) {
      response += F("SamplingRate could not be set to ");
      response += rate;
      return;
    }
    if (strcmp(measuresC, "v,i") == 0) {
      measures = STATE_VI;
      MEASURMENT_BYTES = 8;
    } else if (strcmp(measuresC, "p,q") == 0) {
      measures = STATE_PQ;
      MEASURMENT_BYTES = 8;
    } else if (strcmp(measuresC, "v,i,p,q") == 0) {
      measures = STATE_VIPQ;
      MEASURMENT_BYTES = 16;
    } else {
      response += F("Unsupported measures: ");
      response += measuresC;
      return;
    }
    if (strcmp(typeC, "Serial") == 0) {
      next_state = STATE_SAMPLE_USB;
    } else if (strcmp(typeC, "TCP") == 0) {
      next_state = STATE_SAMPLE_TCP;
    } else if (strcmp(typeC, "FFMPEG") == 0) {
      bool success = tryConnectStream();
      if (success) {
        next_state = STATE_STREAM_TCP;
        response += F("Connected to TCP stream");
      } else {
        response += F("Could not connect to TCP stream");
        return;
      }
    } else {
      response += F("Unsupported sampling type: ");
      response += typeC;
      return;
    }
    // Set global sampling variable
    samplingRate = rate;

    TIMER_CYCLES_FAST = (CLOCK * 1000000) / samplingRate; // Cycles between HW timer inerrupts
    chunkSize = min(max(MEASURMENT_BYTES, int(float(0.1*(float)(samplingRate*MEASURMENT_BYTES)))), BUF_SIZE);

    response += F("SamplingRate set to ");
    response += samplingRate;
    response += F("Hz\nInfo:BufferFlushSize: ");
    response += chunkSize;
    response += F("\nInfo:TIMER_CYCLES_FAST: ");
    response += TIMER_CYCLES_FAST;
    response += F("\nInfo:Data pushed over ");
    response += typeC;


    if (ts != 0) {
      response += F("\nInfo:Start Sampling at: ");
      response += printTime(ts,0);
      updateTime(true);
      uint32_t delta = ts - currentSeconds;
      uint32_t nowMs = millis();
      delta *= 1000;
      delta -= currentMilliseconds;
      if (delta > 20000 or delta < 500) {
        response += F("\nInfo:Cannot start sampling in: ");
        response += delta;
        response += F("ms");
        samplingCountdown = 0;
      } else {
        response += F("\nInfo:Start sampling in: ");
        response += delta;
        response += F("ms");
        samplingCountdown = nowMs + delta;
      }
      return;
    }
    state = next_state;
    startSampling();
  }

  /*********************** SWITCHING COMMAND ****************************/
  else if (strcmp(cmd, CMD_SWITCH) == 0) {
    // For switching we need value payload
    const char* payloadValue = doc["cmd"]["payload"]["value"];
    if (payloadValue == nullptr) {
      response += F("Not a valid \"switch\" command");
      return;
    }
    bool value = doc["cmd"]["payload"]["value"].as<bool>();
    response += F("Switching: ");
    response += value ? F("On") : F("Off");
    switchRelay(RELAY_PIN, true);
  }

  /*********************** STOP COMMAND ****************************/
  else if (strcmp(cmd, CMD_STOP) == 0) {
    // State is reset in stopSampling
    next_state = state;
    stopSampling();
    // Send remaining
    if (next_state == STATE_SAMPLE_USB) writeChunks(Serial, true);
    else if (next_state == STATE_SAMPLE_TCP) writeChunks(client, true);
    response += F("Sampled for ");
    response += printDuration(samplingDuration);
    response += F("\nInfo:Samples ");
    response += totalSamples;
    response += F("\nInfo:Sent Samples ");
    response += sentSamples;
    response += F("\nInfo:Avg SR: ");
    response += totalSamples/(samplingDuration/1000.0);
    response += F("Hz");
    response += F("\nInfo:stop");
  }

  /*********************** RESTART COMMAND ****************************/
  else if (strcmp(cmd, CMD_RESTART) == 0) {
    stopSampling();
    turnInterrupt(false);
    ESP.restart();
  }

  /*********************** INFO COMMAND ****************************/
  else if (strcmp(cmd, CMD_INFO) == 0) {
    response += F("WIFI powermeter. Version: ");
    response += VERSION;
    response += F("\nInfo:Buffer Size:");
    response += BUF_SIZE;
  }

  /*********************** MDNS COMMAND ****************************/
  // e.g. {"cmd":{"name":"mdns", "payload":{"name":"newName"}}}
  else if (strcmp(cmd, CMD_MDNS) == 0) {
    const char* newName = doc["cmd"]["payload"]["name"];
    if (newName == nullptr) {
      response += F("MDNS name required in payload with key name");
      return;
    }
    if (strlen(newName) < MAX_MDNS_LEN) {
      writeMDNS((char * )newName);
    } else {
      Serial.println(F("Not allowed"));
      response += F("MDNS name too long, only string of size ");
      response += MAX_MDNS_LEN;
      response += F(" allowed");
      return;
    }
    char * name = getMDNS();
    response = F("Info:Set MDNS name to: ");
    response += name;
  }

  /*********************** MDNS COMMAND ****************************/
  // e.g. {"cmd":{"name":"ntp"}}
  else if (strcmp(cmd, CMD_NTP) == 0) {
    if (getTimeNTP()) {
      response += F("Time synced");
    } else {
      response += F("Error syncing time");
    }
    char * timeStr = printTime(ntpEpochSeconds, ntpMilliseconds);
    Serial.println(timeStr);
    delay(1000);
    timeStr = printCurrentTime();
    Serial.println(timeStr);
  }
}

/****************************************************
 * Try to connect the streaming tcp client.
 ****************************************************/
bool tryConnectStream() {
  if (!streamClient.connected()) {
    // Look for people connecting over the streaming server
    streamClient = streamServer.available();
    if (streamClient && streamClient.connected()) {
      return true;
    } else {
      return false;
    }
  }
  return true;
}

/****************************************************
 * Stop Sampling will go into ide state, stop the
 * interrupt and if any stream client is connected,
 * will send EOF to the client
 ****************************************************/
void stopSampling() {
  state = STATE_IDLE;
  turnInterrupt(false);
  samplingDuration = millis() - startSamplingMillis;
  if (streamClient && streamClient.connected()) streamClient.stop();
}

/****************************************************
 * Start Sampling requires to start the interrupt and
 * to calculate the chunkSize size depending on
 * the samplingrate currently set. Furthermore,
 * all buffer indices are reset to the default values.
 ****************************************************/
void startSampling() {
  switchRelay(RELAY_PIN, true);
  counter = 0;
  sentSamples = 0;
  totalSamples = 0;
  TIMER_CYCLES_FAST = (CLOCK * 1000000) / samplingRate; // Cycles between HW timer inerrupts
  chunkSize = min(max(MEASURMENT_BYTES, int(float(0.1*(float)(samplingRate*MEASURMENT_BYTES)))), BUF_SIZE/2);
  writePtr = 0;
  readPtr = 0;
  startSamplingMillis = millis();
  samplingDuration = 0;
  turnInterrupt(true);
}

/****************************************************
 * Detach or attach intterupt
 ****************************************************/
void turnInterrupt(bool on) {
  cli();//stop interrupts
  if (on) {
    timer0_attachInterrupt(sample_ISR);
    timer_next = ESP.getCycleCount() + TIMER_CYCLES_FAST;
    freqCalcStart = micros();
    timer0_write(timer_next);
  } else {
    timer0_detachInterrupt();
  }
  sei();
}

/****************************************************
 * Switch relay to open or closed
 ****************************************************/
inline void switchRelay(int number, bool value) {
  digitalWrite(number, value);
}
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

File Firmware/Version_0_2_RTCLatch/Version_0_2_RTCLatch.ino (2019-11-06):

#include <Arduino.h>
#include <ArduinoOTA.h>
#include <SPI.h>
#include <esp_wifi.h>
#include <WiFi.h>
#include <WiFiAP.h>
#include <time.h>
#include <ArduinoJson.h>
#include <TimeLib.h>
#include <ESPmDNS.h>
#include <esp_int_wdt.h>
#include <esp_task_wdt.h>
#include <esp_sleep.h>
#include <esp_bt.h>
#include <esp32-hal-cpu.h>
#include <rom/rtc.h>

#include "constDefine.h"
#include "STPM.h"
#include "relay.h"
#include "rtc.h"
#include "config.h"
#include "ringbuffer.h"
#include "network.h"
#include "timeHandling.h"
#include "logger.h"


// Function prototypes required for e.g. platformio
void calcChunkSize();
bool getTimeNTP();
void handleEvent(Stream &getter);
void handleJSON();
void initMDNS();
void onIdle();
void onSampling();
void onWifiConnect();
void onWifiDisconnect();
char * printCurrentTime();
char * printDuration(unsigned long ms);
char * printTime(unsigned long s, unsigned long ms);
void IRAM_ATTR sample_ISR();
void setInfoString(char * str);
void setupOTA();
void IRAM_ATTR sqwvTriggered();
inline void startSampling();
void startSampling(bool waitVoltage);
void stopSampling();
void timer_init();
void turnInterrupt(bool on);
void updateTime(bool ntp);
void updateTimeInBG(void * pvParameters);
void writeChunks(bool tail);
void writeData(Stream &getter, uint16_t size);
char * timeStr();

TaskHandle_t xHandle = NULL;
TaskHandle_t xHandleProducer = NULL;

xQueueHandle xQueue;



// Serial logger
StreamLogger serialLog((Stream*)&Serial, &timeStr, &LOG_PREFIX_SERIAL[0], ALL);
// TCP logger
StreamLogger streamLog((Stream*)NULL, &timeStr, &LOG_PREFIX[0], INFO);
// SPIFFS logger
SPIFFSLogger spiffsLog(false, &LOG_FILE[0], &timeStr, &LOG_PREFIX_SERIAL[0], WARNING);

// MultiLogger logger(&streamLog, &timeStr);
// Create singleton here
MultiLogger& logger = MultiLogger::getInstance();

Configuration config;

Relay relay(RELAY_PIN_S, RELAY_PIN_R);

Rtc rtc(RTC_INT);
TimeHandler myTime(&rtc, ntpServerName, LOCATION_TIME_OFFSET);

// STPM Object
STPM stpm34(STPM_RES, STPM_CS, STPM_SYN);

// counter holds # isr calls
volatile uint16_t counter = 0;
// Last micros() count of isr call
volatile long nowTs = 0;
volatile long lastTs = 0;

RingBuffer ringBuffer(PS_BUF_SIZE, true);

static uint8_t sendbuffer[MAX_SEND_SIZE+16] = {0};
// Buffer read/write position
uint32_t psdReadPtr = 0;
uint32_t psdWritePtr = 0;
volatile uint32_t writePtr = 0;

// Open two TCP ports, one for commands and sampling and one for a raw data stream
WiFiServer server(STANDARD_TCP_SAMPLE_PORT);
WiFiServer streamServer(STANDARD_TCP_STREAM_PORT);

// TIMER stuff
// Calculate the number of cycles we have to wait
volatile uint32_t TIMER_CYCLES_FAST = (1000000) / DEFAULT_SR; // Cycles between HW timer inerrupts
volatile uint32_t timer_next;
volatile uint32_t timer_now;


enum StreamType{USB, TCP, UDP, TCP_RAW};

// Internal state machine for sampling
enum SampleState{STATE_IDLE, STATE_SAMPLE};

SampleState state = STATE_IDLE;
SampleState next_state = STATE_IDLE;

// Available measures are VOLTAGE+CURRENT, ACTIVE+REACTIVE Power or both
enum Measures{STATE_VI, STATE_PQ, STATE_VIPQ};

struct StreamConfig {
  bool prefix = false;                      // Send data with "data:" prefix
  Measures measures = STATE_VI;             // The measures to send
  uint8_t measurementBytes = 8;             // Number of bytes for each measurement entry
  unsigned int samplingRate = DEFAULT_SR;   // The samplingrate
  StreamType stream = USB;                  // Channel over which to send
  unsigned int countdown = 0;               // Start at specific time or immidiately
  uint32_t chunkSize = 0;                   // Chunksize of one packet sent
  IPAddress ip;                             // Ip address of data sink
  uint16_t port = STANDARD_TCP_SAMPLE_PORT; // Port of data sink
};

StreamConfig streamConfig;


// Stuff for frequency calculation
volatile long freqCalcStart;
volatile long freqCalcNow;
volatile long freq = 0;

bool tcpConnected = false;
WiFiClient tcpClient;
WiFiClient streamClient;
// UDP used for streaming
WiFiUDP udpClient;

char command[COMMAND_MAX_SIZE] = {'\0'};
StaticJsonDocument<2*COMMAND_MAX_SIZE> docRcv;
StaticJsonDocument<2*COMMAND_MAX_SIZE> docSend;
String response = "";

unsigned long samplingCountdown = 0;
unsigned long startSamplingMillis = 0;
unsigned long samplingDuration = 0;
unsigned long sentSamples = 0;
volatile unsigned long packetNumber = 0;
volatile unsigned long totalSamples = 0;

long lifenessUpdate = millis();
long mdnsUpdate = millis();
long wifiUpdate = millis();

// HW Timer and mutex for sapmpling ISR
hw_timer_t * timer = NULL;
portMUX_TYPE timerMux = portMUX_INITIALIZER_UNLOCKED;

// Current CPU speed
unsigned int coreFreq = 0;

// test stuff
long testMillis = 0;
long testMillis2 = 0;
uint16_t testSamples = 0;

// Mutex for 1s RTC Interrupt
portMUX_TYPE sqwMux = portMUX_INITIALIZER_UNLOCKED;
bool firstSqwv = true;
volatile int sqwCounter = 0;

volatile float values[4] = {0};

// FPU register state
uint32_t cp0_regs[18];


#ifdef ARDUINO_ARCH_ESP32
#include "esp32-hal-log.h"
#endif


// How can we change those parameters in Arduino, possible?
// CONFIG_TCP_MSS=1436
// CONFIG_TCP_MSL=60000
// CONFIG_TCP_SND_BUF_DEFAULT=5744
// CONFIG_TCP_WND_DEFAULT=5744

/************************ SETUP *************************/
void setup() {
  // Setup serial communication
  Serial.begin(SERIAL_SPEED);

  // At first init the rtc module to get 
  bool successAll = true;
  bool success = rtc.init();
  // Init the logging module
  logger.setTimeGetter(&timeStr);
  // Add Serial logger
  logger.addLogger(&serialLog);
  // Add spiffs logger
  logger.addLogger(&spiffsLog);
  // Init all loggers
  logger.init();

  if (!success) logger.log(ERROR, "Cannot init RTC");
  successAll &= success;
  relay.set(true);
  // We do not need bluetooth, so disable it
  esp_bt_controller_disable();
  pinMode(ERROR_LED, OUTPUT);

  // Indicate lifeness / reset
  digitalWrite(ERROR_LED, HIGH);
  delay(200);
  digitalWrite(ERROR_LED, LOW);
  delay(200);
  digitalWrite(ERROR_LED, HIGH);

  config.load();

  coreFreq = getCpuFrequencyMhz();
  logger.log(DEBUG, "%s @ firmware %s/%s", config.name, __DATE__, __TIME__);
  logger.log(DEBUG, "Core @ %u MHz", coreFreq);

  success = ringBuffer.init();
  if (!success) logger.log(ERROR, "PSRAM init failed");
  successAll &= success;

  // config.makeDefault();
  // config.store();

  timer_init();

  // Setup STPM 32
  success = stpm34.init();
  if (!success) logger.log(ERROR, "STPM Init Failed");
  successAll &= success;

  
   // Indicate error if there is any
  digitalWrite(ERROR_LED, !successAll);

  logger.log(ALL, "Connecting WLAN");

  Network::init(&config, onWifiConnect, onWifiDisconnect);
  setupOTA();

  response.reserve(2*COMMAND_MAX_SIZE);


  setInfoString(&command[0]);
  logger.log(&command[0]);

  logger.log(ALL, "Setup done");

  lifenessUpdate = millis();
  mdnsUpdate = millis();
  wifiUpdate = millis();
}
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

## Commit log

2018-11-07 Initial commit of latest files
    [CPC1998J.stl, CPC1998J.stp, Huelle_Programmer_oben.stl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]
2018-11-23 added current version
2018-12-06 Fixed that NTP timed recordings can also be startet using tcp clients
    [stpmTCP.ino]
2018-12-19 Disabled Autolatching in favour of manual latching to prevent data glitches! Added CRC disable option and autolatch On option. Tested until 8kHz even if the stpm only supports 7.8125kHz.
    [stpmTCP.ino]
2019-01-07 added ability to set mdns name using serial or tcp command -> Command: 'n12' sets mdns name to powermeter12
2019-03-06 Changed nbuffering to a ringbuffer, version 0.1 kept. Exceptions might still occur. Mutual exclusion problem?
    [Version_0_1.ino]
2019-08-05 added version 0_2_x TODO: We need SPIFFS integration to prevent data loss
    [STPM.cpp, Version_0_2_x.ino]
2019-09-06 Ported to ESP32
    [powermeter09.brd, powermeter09.sch, powermeterV2.brd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]
2019-09-27 new firmware with RTC support, PSRAM, new schematic/board with error LED, I2C pullups etc, diodes
    [powermeterV2.brd, powermeterV2.sch]
2019-10-16 objectify + added logger, timehandler
    [powermeterV2.brd]
2019-11-08 added new version where SPI is not in interrupt
2020-01-20 Version renumbering. Hardware Version 1 will now work with Software Version and Hardware Version 2 requires Software Version >= 2
    [powermeterV2.brd]
2020-01-22 fixed board/schematic inconsistencies. added 100nF on IO0
    [powermeterV2.brd, powermeterV2.sch]
2020-02-18 added sampleCB function, network switch is now not possible while sampling or OTA
2020-02-20 fixed issue #453 -> null on mqtt sampling and #454 -> stop command
    [constDefine.h, parseCommands.ino]
2020-03-19 fixed #462 and #463
    [constDefine.h, parseCommands.ino]
2020-04-23 added flow control, fixing #469, #470, #471, #474, used snprintf
    [constDefine.h, parseCommands.ino]
2020-05-18 more priority for sampling task, hopefully fixing #487
    [constDefine.h, parseCommands.ino]
2021-02-24 Speed up MQTT Reconnect and support mqtt retained switches
    [Assem1.SLDASM, case_in_cable.SLDPRT, case_in_cable.STL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]
2021-03-02 more docu
    [powermeterV2.brd]
2021-03-02 removed zips
    [powermeter09.brd, powermeter09.sch]
2021-03-02 renamed schematic folder
    [powermeterV2.brd, powermeterV2.dxf, powermeterV2.sch]
2021-03-03 changed software timers to use unsigned int
2021-03-03 chenged timer to unsigned int
2021-03-18 Fixed MQTT msg too often
    [Version_2.ino]
2021-08-06 added reset energy command
    [constDefine.h]
2021-08-06 added reset energy command, energy over mqtt
    [parseCommands.ino]
2021-08-12 added support for energy, reset, calibration
    [Version_1.ino, constDefine.h, parseCommand.ino]
2021-08-12 added config for energy, reset, calibration
    [config.h]
2021-08-12 different software timer for mqtt
2021-08-18 added sensorboard submodule with simlinks
2021-08-18 added support for sensorboard
2021-08-19 some LED patterns included
2021-08-26 each LED now indicating successfull init of a certain module
2021-09-17 sensor board config included
2021-09-17 const members converted to defines, SensorBoardCmds added
2021-09-17 sensorboard commands handled
2021-09-17 sensor MQTT now on separate topics
2021-09-17 added docu for sensor board commands
2021-09-20 fixed RMS voltage
2021-09-20 new CAD
2021-09-21 fixed storeage of energy start period
    [Version_2.ino, parseCommands.ino]
2021-09-21 added pic of powermeter
2021-10-27 latest sensorboard chechout
2022-10-29 downgraded submodules to https + sensorboard fix
    [Version_2.ino, constDefine.h]
2026-11-06 bugfix: switch value, code improvements

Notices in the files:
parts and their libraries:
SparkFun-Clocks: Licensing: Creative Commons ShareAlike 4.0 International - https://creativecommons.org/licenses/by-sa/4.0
